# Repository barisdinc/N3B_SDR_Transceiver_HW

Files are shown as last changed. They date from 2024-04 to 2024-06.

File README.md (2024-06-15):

# N3B
V/U/SHF and QO-100 SDR Transceiver Project

This project is a SDR receiver transceiver project initiated to have a portable QO-100 Satellite ground station which can receiver on 739 MHz (direct output of a standard TV LNB) and transmit on 2.4 GHz QO-100 uplink frequency.
The basic idea of the SDR is based on Arjante Marvelde's implementation of Guido's uSDX implementation on raspberry pi pico (https://github.com/ArjanteMarvelde/uSDR-pico/).

Instead of HF components as Tyloe detector Analog Devices's IQ modulator and demodulator chips are chosen to be the IQ components.

I will update the documentation as soon as possible.
Baris DINC
OH2UDS / TA7W

initial pictures of qocurrent work done
initial pictures of the working HW 
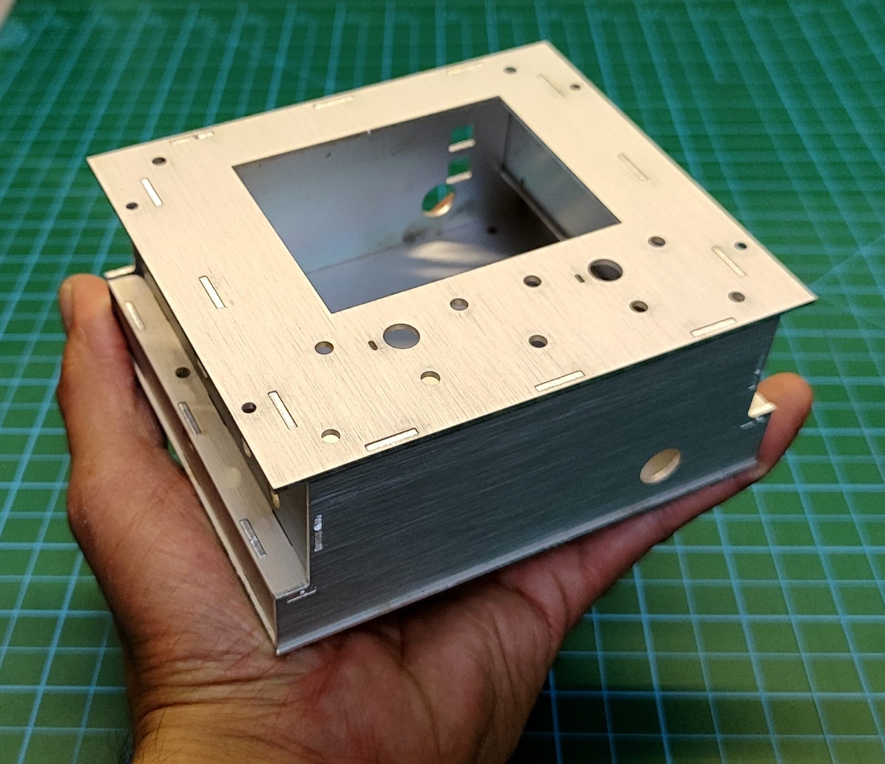
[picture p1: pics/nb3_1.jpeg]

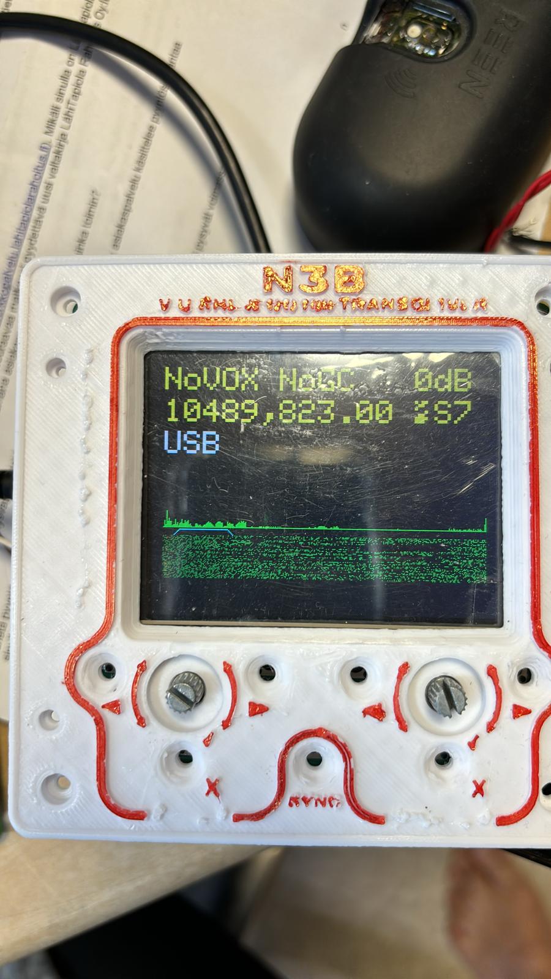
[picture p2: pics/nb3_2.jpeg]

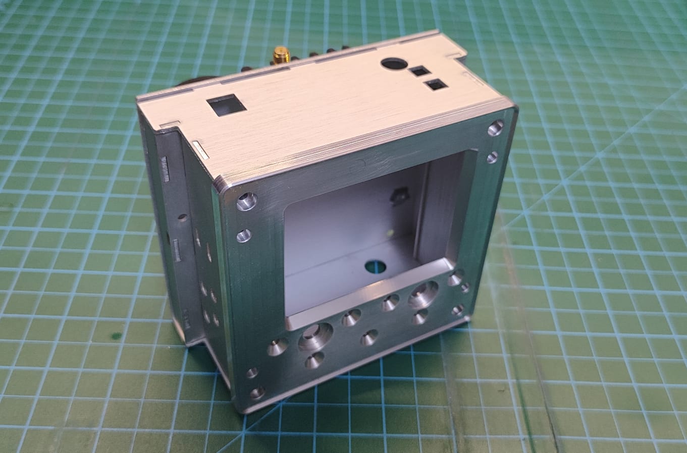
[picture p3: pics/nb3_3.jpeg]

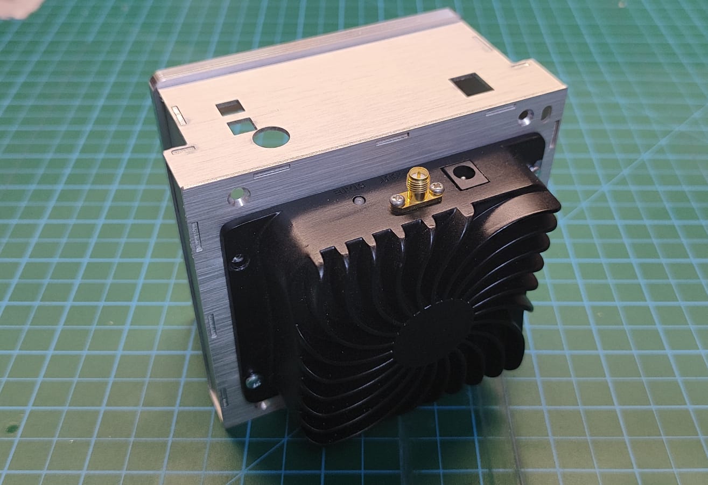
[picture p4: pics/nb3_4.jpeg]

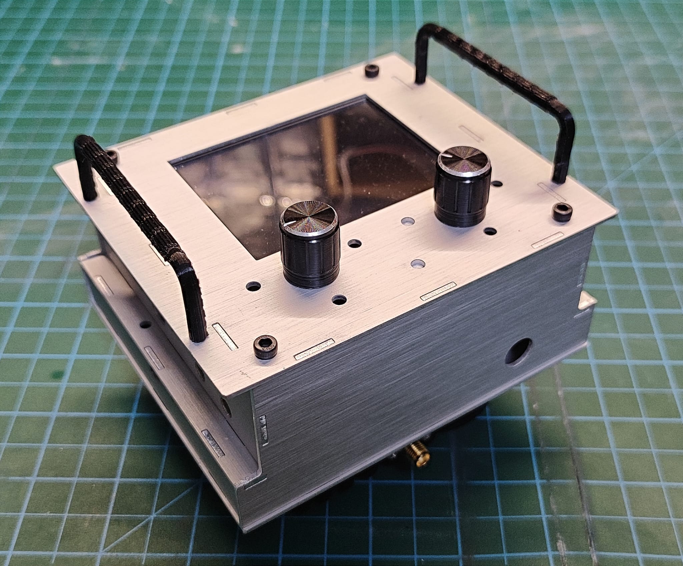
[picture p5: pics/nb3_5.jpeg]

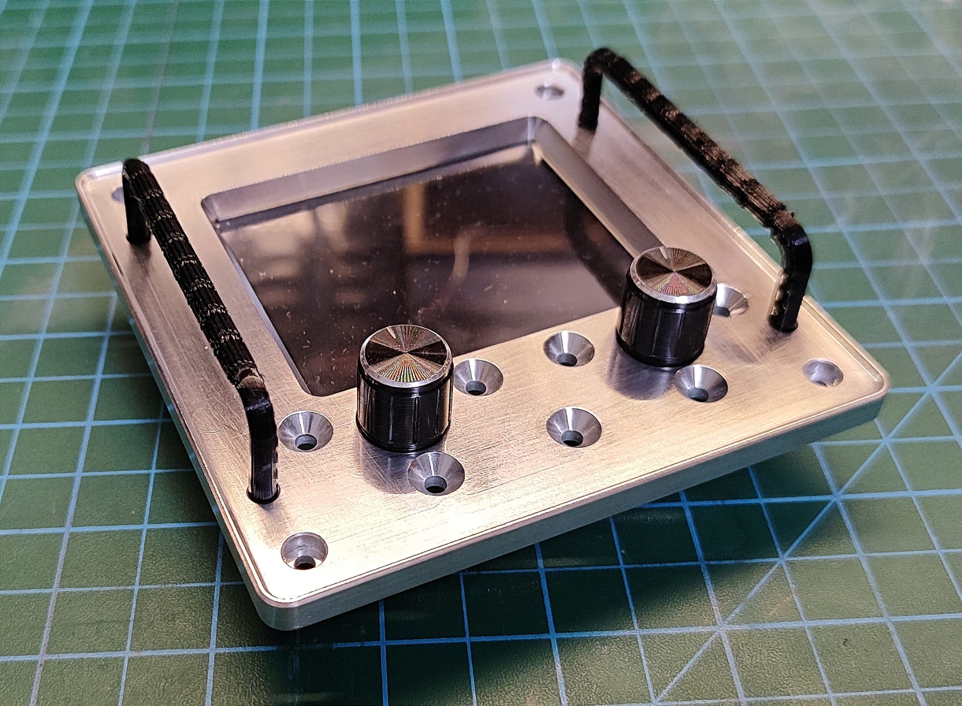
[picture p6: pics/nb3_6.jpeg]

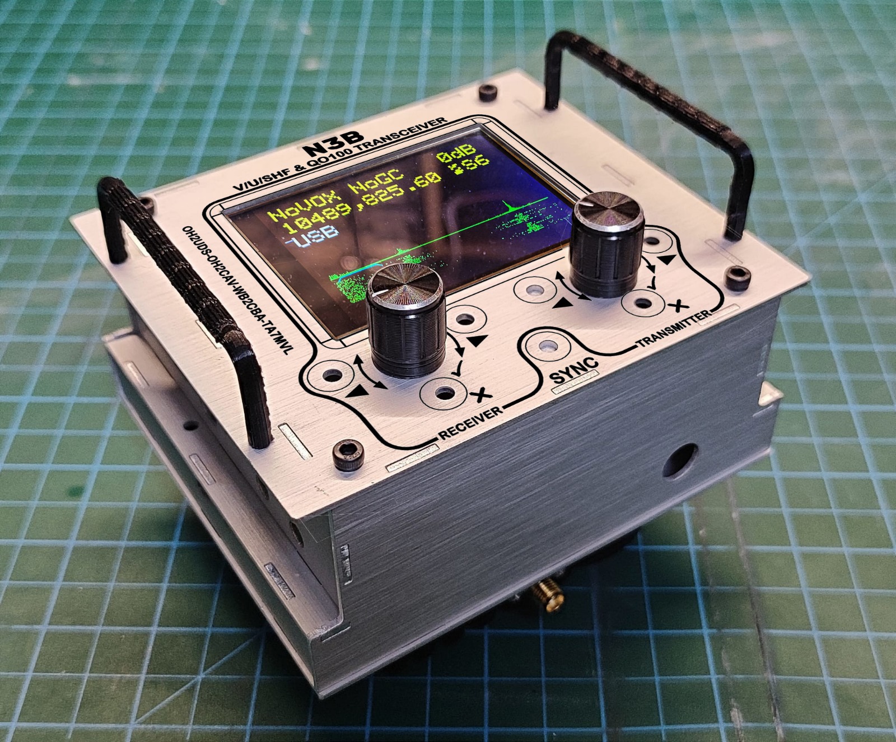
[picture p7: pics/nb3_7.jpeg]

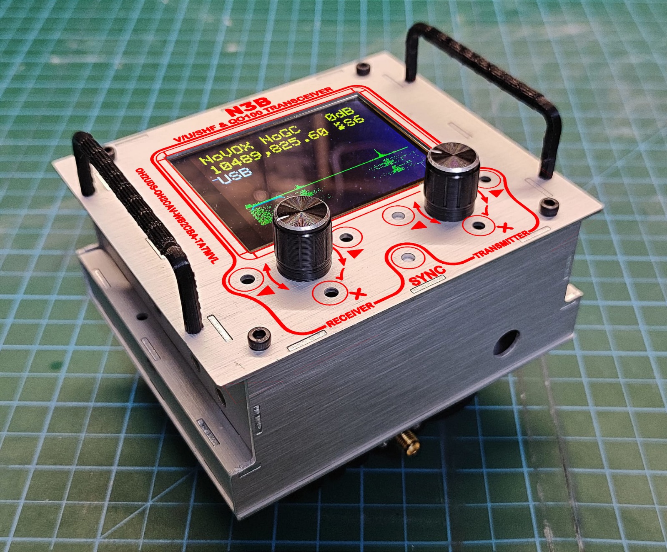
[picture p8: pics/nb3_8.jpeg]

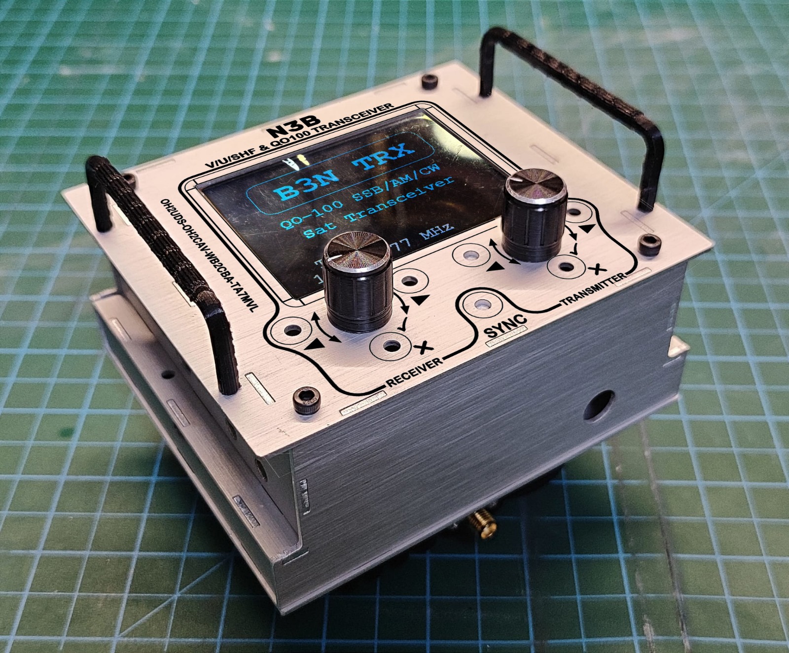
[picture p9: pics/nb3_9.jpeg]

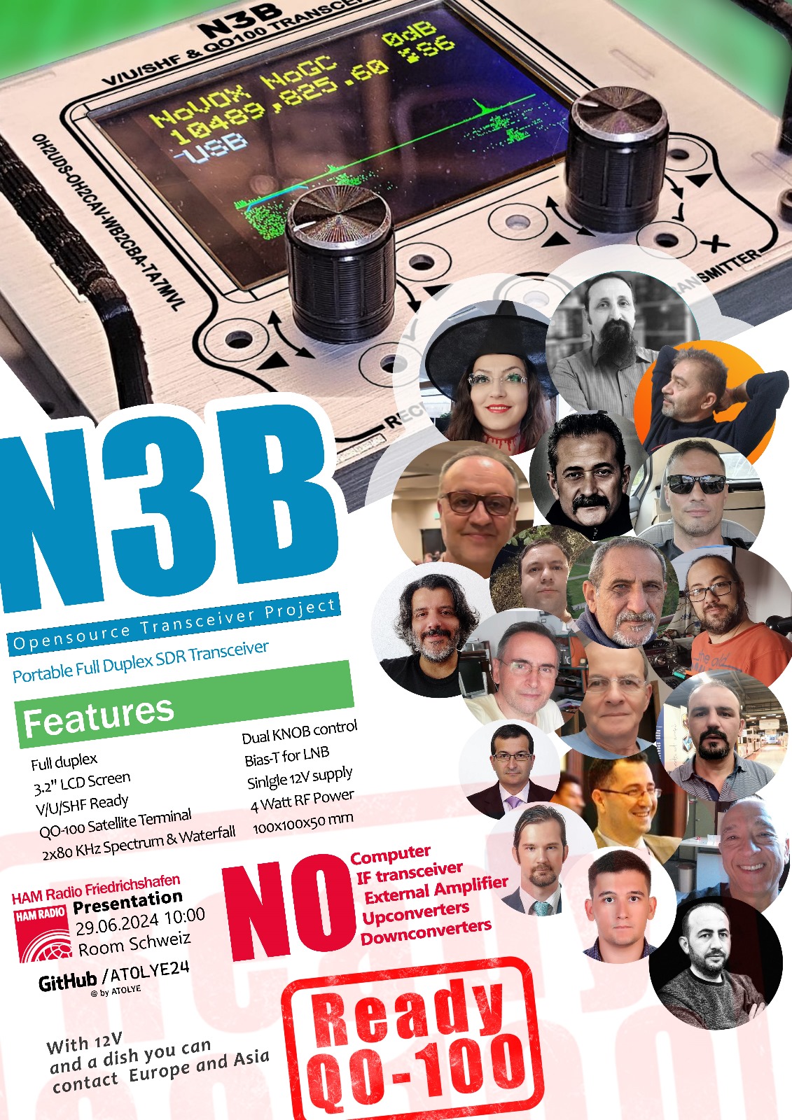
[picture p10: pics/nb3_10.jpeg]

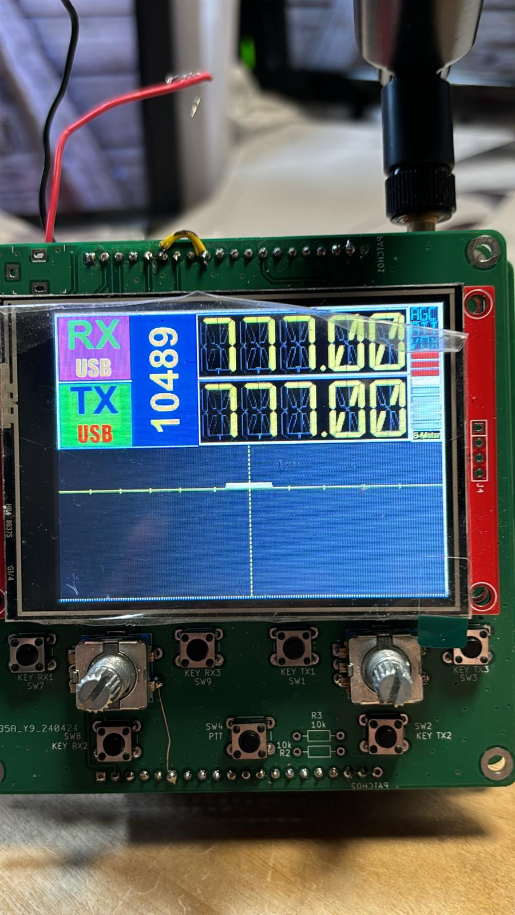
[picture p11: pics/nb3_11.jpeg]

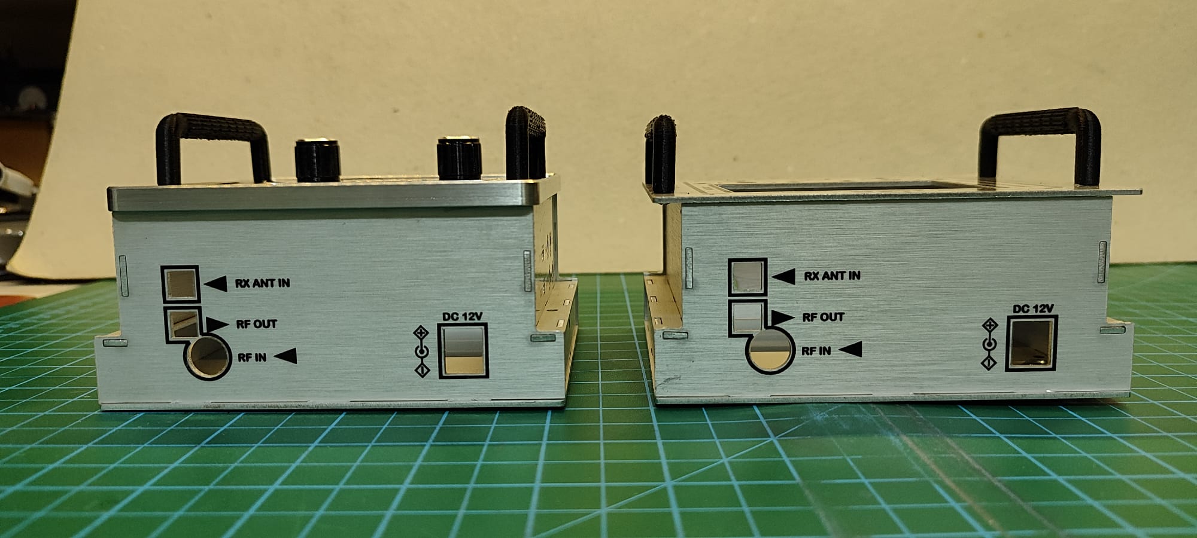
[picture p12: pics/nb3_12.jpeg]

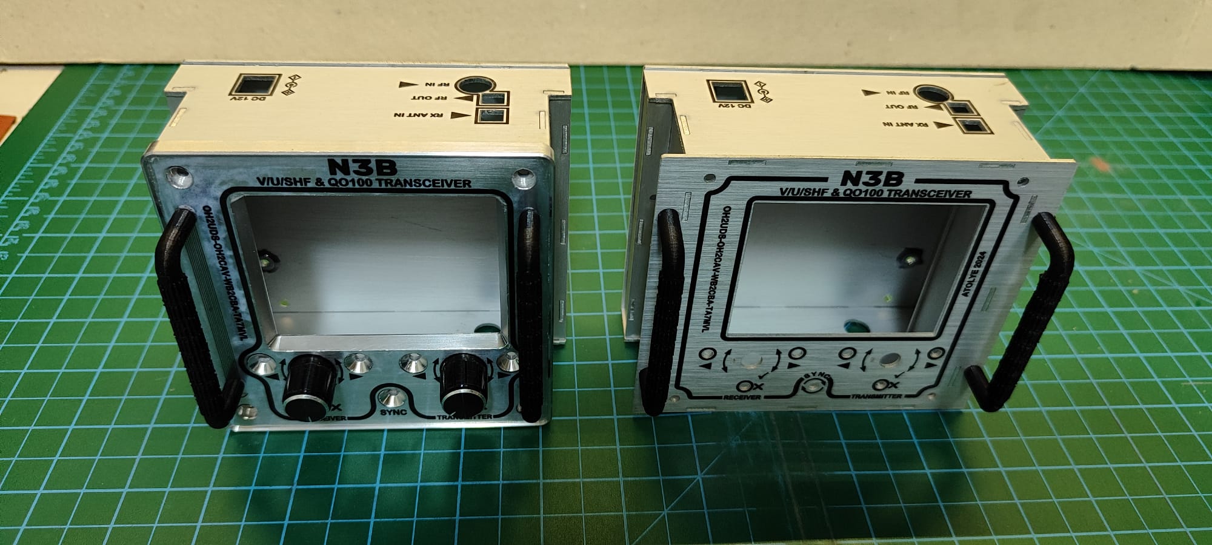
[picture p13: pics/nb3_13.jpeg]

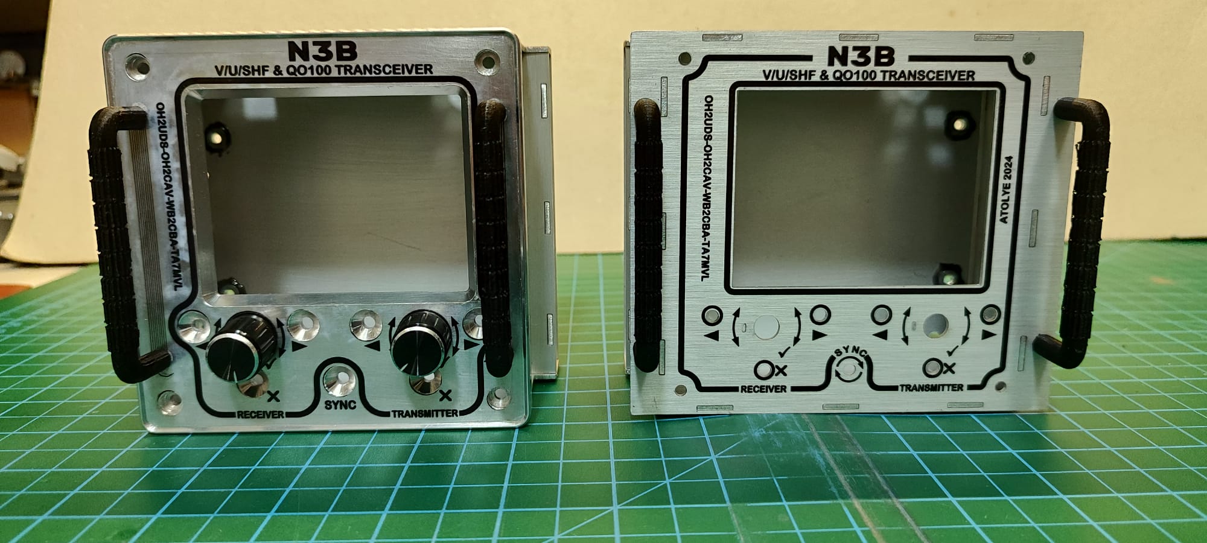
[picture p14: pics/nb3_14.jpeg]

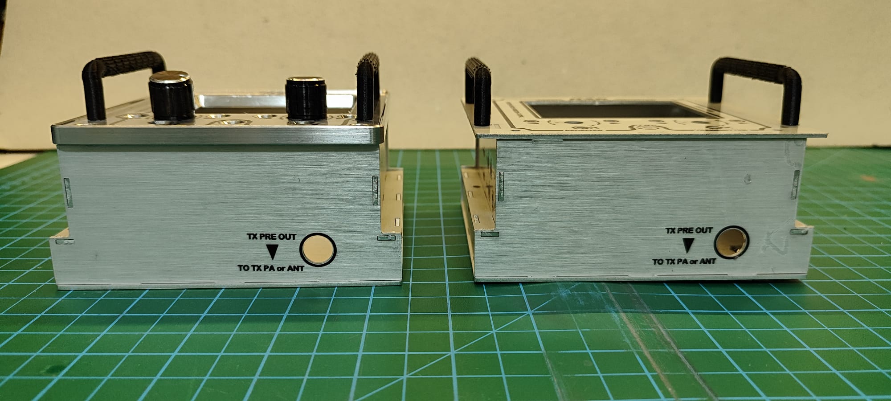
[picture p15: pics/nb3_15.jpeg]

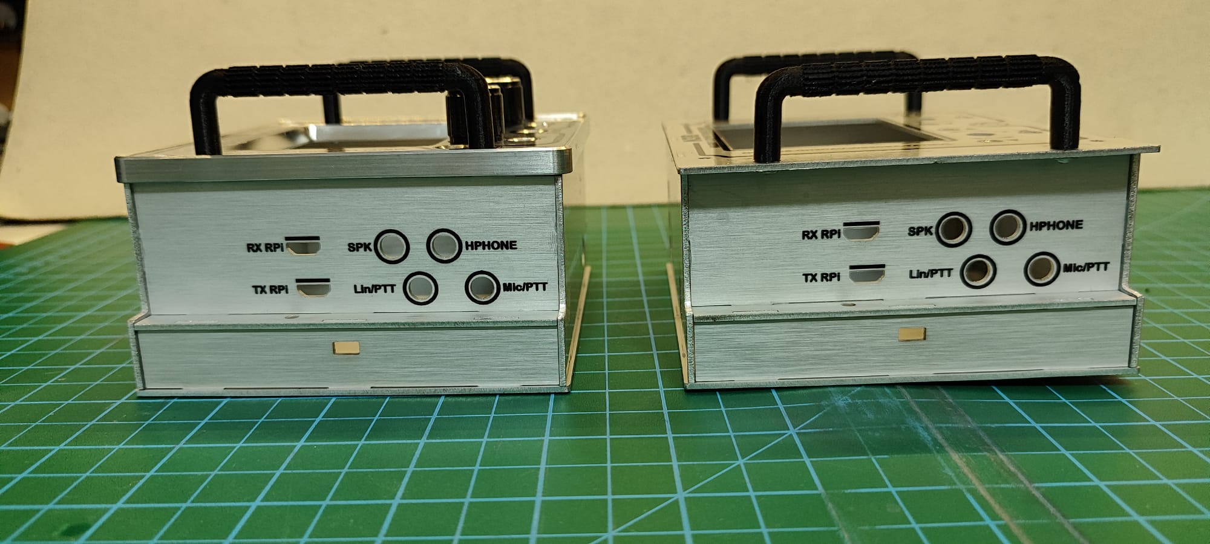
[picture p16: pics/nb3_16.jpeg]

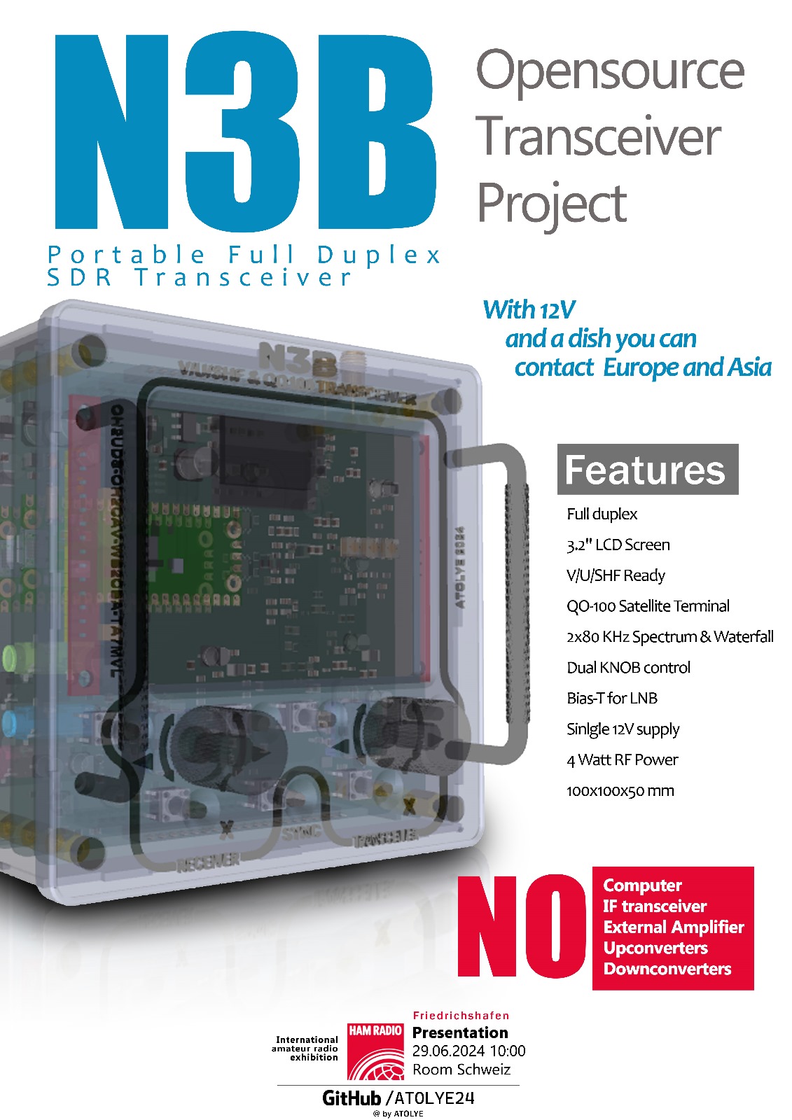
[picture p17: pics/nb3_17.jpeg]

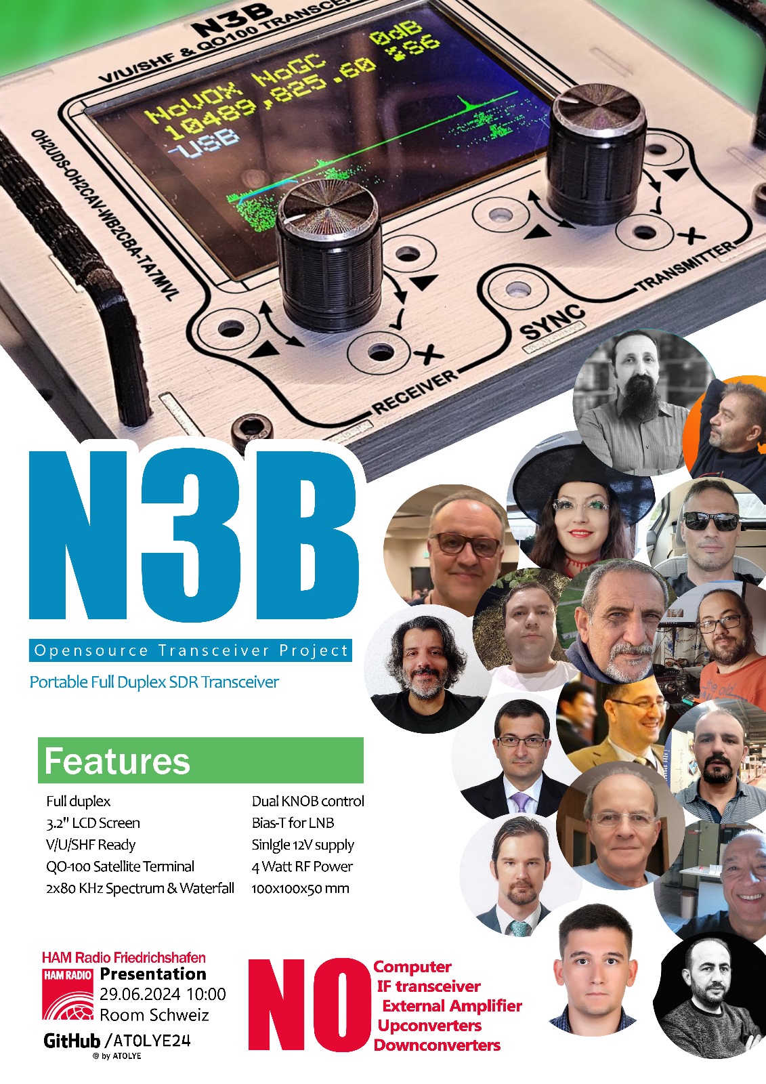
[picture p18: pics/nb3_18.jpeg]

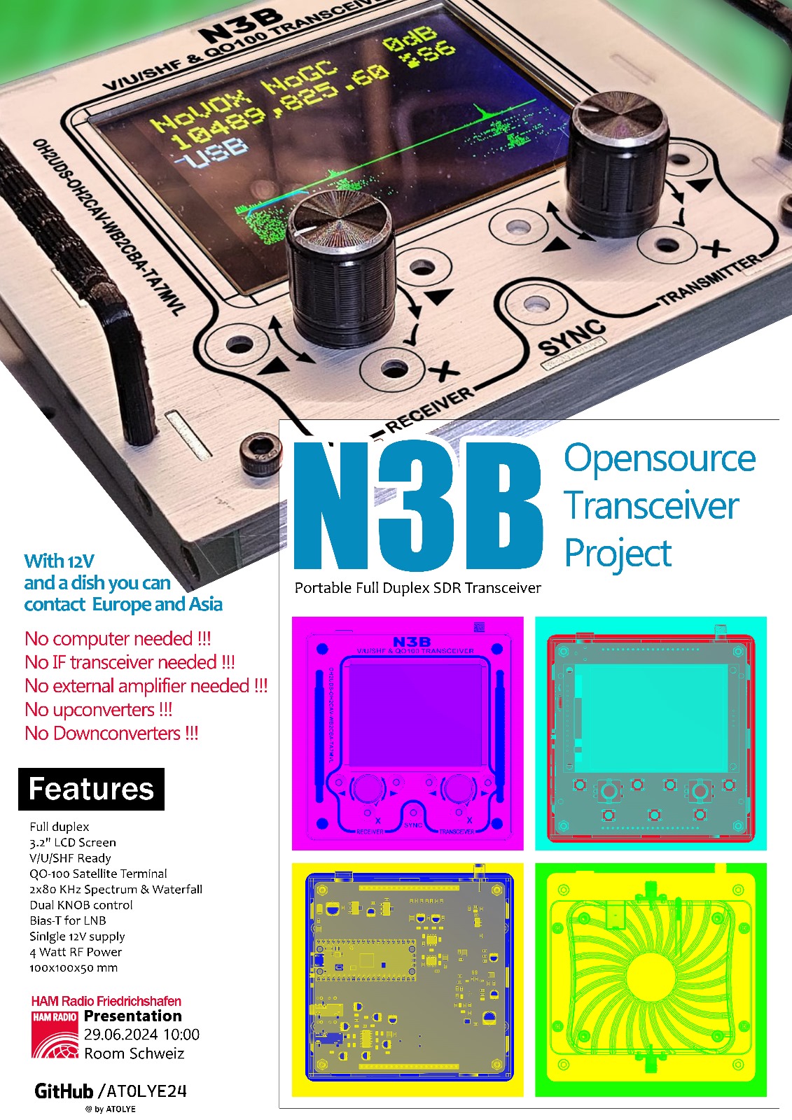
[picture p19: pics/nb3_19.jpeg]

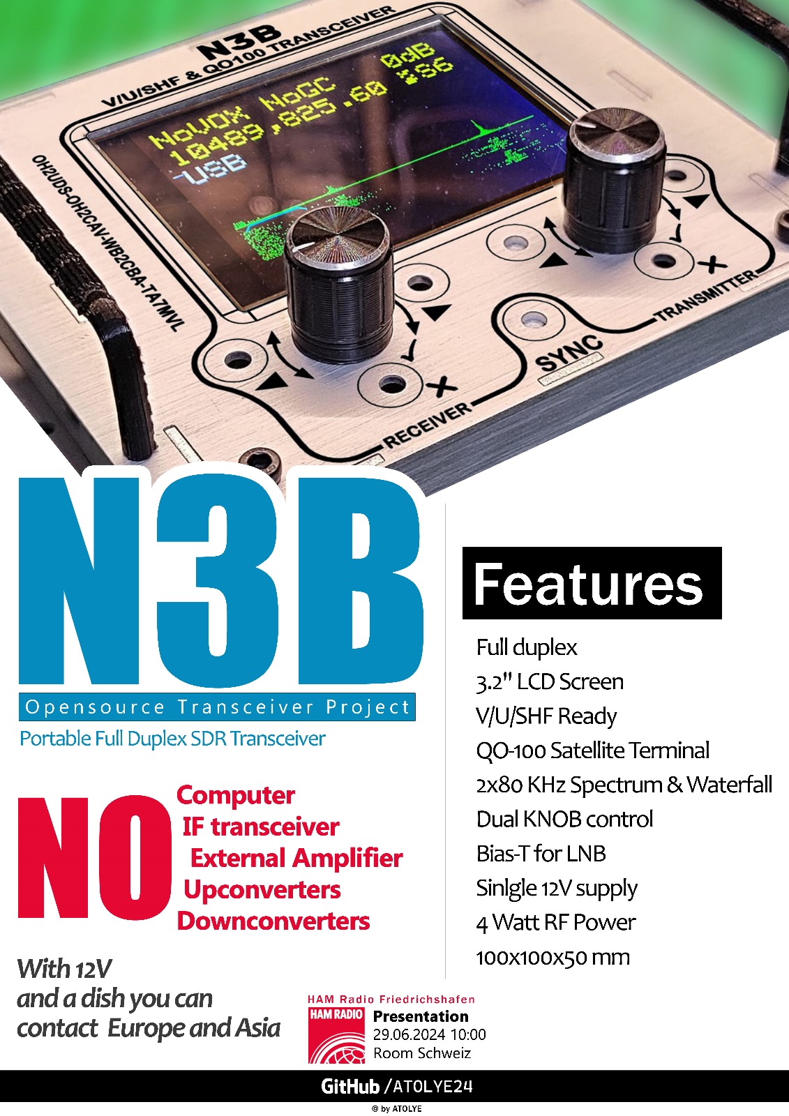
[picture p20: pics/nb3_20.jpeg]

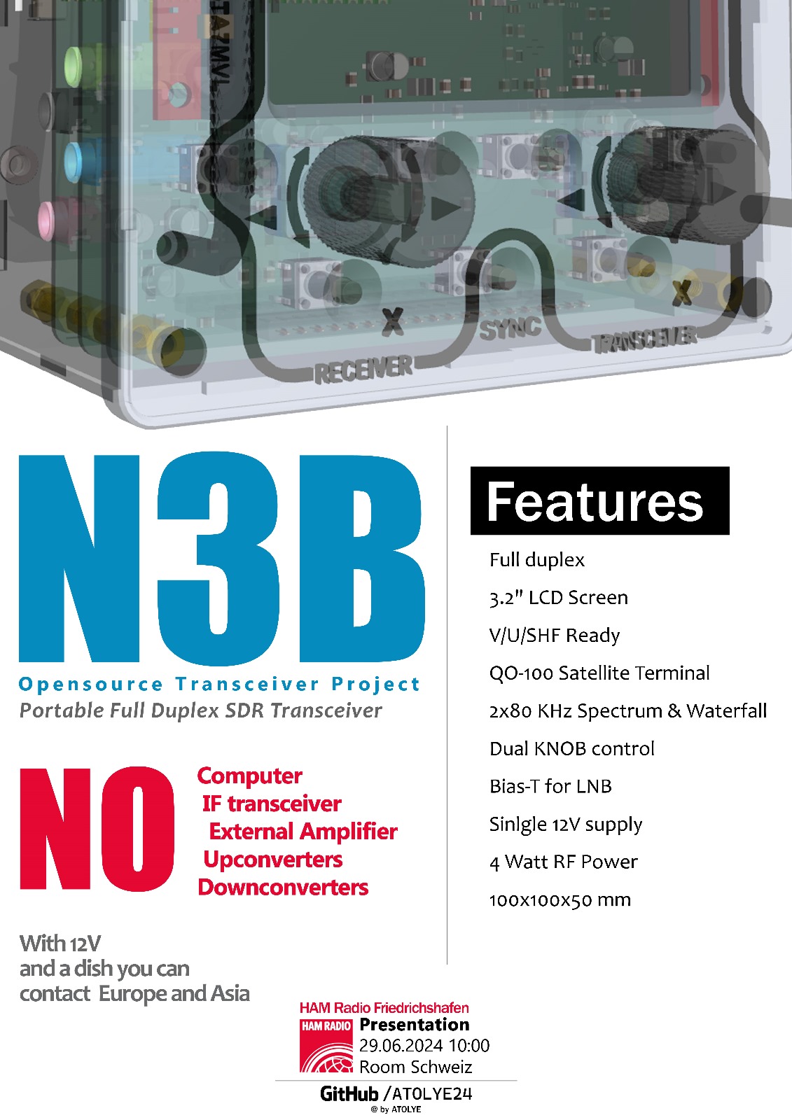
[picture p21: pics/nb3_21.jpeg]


OH2UDS / TA7W.

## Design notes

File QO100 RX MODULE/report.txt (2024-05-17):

Info: Change symbol path "C66:" to "/663CC0C7".
Info: Change symbol path "L5:" to "/664548BE".
Info: Processing component "R30:/664476E5:Resistor_SMD:R_0805_2012Metric".
Info: Change symbol path "C68:" to "/663DEFD4".
Info: Change symbol path "R30:" to "/664476E5".
Info: Processing component "C68:/663DEFD4:Capacitor_SMD:C_0805_2012Metric".
Info: Change symbol path "C67:" to "/6658E7D9".
Info: Processing component "R31:/662D891D:Resistor_SMD:R_0805_2012Metric".
Info: Processing component "C67:/6658E7D9:Capacitor_SMD:C_0805_2012Metric".
Info: Change symbol path "R33:" to "/66471DDC".
Info: Change symbol path "C76:" to "/664476D9".
Info: Processing component "R32:/664476DF:Resistor_SMD:R_0805_2012Metric".
Info: Processing component "C66:/663CC0C7:Capacitor_SMD:C_0805_2012Metric".
Info: Change symbol path "C65:" to "/6677DF00".
Info: Change symbol path "R29:" to "/662DA837".
Info: Processing component "C65:/6677DF00:Capacitor_SMD:C_0805_2012Metric".
Info: Processing component "R33:/66471DDC:Resistor_SMD:R_0805_2012Metric".
Info: Change symbol path "C64:" to "/663E3197".
Info: Processing component "C64:/663E3197:Capacitor_SMD:CP_Elec_4x5.4".
Info: Processing component "L6:/663A9446:Inductor_SMD:L_0603_1608Metric".
Info: Change symbol path "C63:" to "/6677C284".
Info: Processing component "R34:/66D28264:Resistor_SMD:R_0805_2012Metric".
Info: Processing component "C63:/6677C284:Capacitor_SMD:C_0805_2012Metric".
Info: Change symbol path "C62:" to "/663E1CF4".
Info: Change symbol path "R34:" to "/66D28264".
Info: Processing component "C62:/663E1CF4:Capacitor_SMD:C_0805_2012Metric".
Info: Processing component "R35:/66701C3B:Resistor_SMD:R_0805_2012Metric".
Info: Processing component "R27:/66D245A6:Resistor_SMD:R_0805_2012Metric".
Info: Change symbol path "R31:" to "/662D891D".
Info: Change symbol path "R24:" to "/66701C6C".
Info: Processing component "C76:/664476D9:Capacitor_SMD:C_0805_2012Metric".
Info: Processing component "R25:/668B2F03:Resistor_SMD:R_0805_2012Metric".
Info: Change symbol path "C75:" to "/662CEC74".
Info: Change symbol path "R25:" to "/668B2F03".
Info: Processing component "C75:/662CEC74:Capacitor_SMD:C_0805_2012Metric".
Info: Change symbol path "C74:" to "/66F02636".
Info: Processing component "R26:/668B1381:Resistor_SMD:R_0805_2012Metric".
Info: Processing component "C71:/662CAD43:Capacitor_SMD:C_0805_2012Metric".
Info: Change symbol path "R26:" to "/668B1381".
Info: Change symbol path "C73:" to "/66D249A5".
Info: Change symbol path "C61:" to "/6677A768".
Info: Processing component "C73:/66D249A5:Capacitor_SMD:C_0805_2012Metric".
Info: Change symbol path "C72:" to "/668B68FC".
Info: Change symbol path "R27:" to "/66D245A6".
Info: Processing component "C72:/668B68FC:Capacitor_SMD:C_0805_2012Metric".
Info: Processing component "R28:/662D695C:Resistor_SMD:R_0805_2012Metric".
Info: Processing component "C53:/669B0E9A:Capacitor_SMD:C_0805_2012Metric".
Info: Processing component "C47:/663A94C4:Capacitor_SMD:C_0805_2012Metric".
Info: Change symbol path "R28:" to "/662D695C".
Info: Change symbol path "C70:" to "/668B4AD4".
Info: Processing component "R29:/662DA837:Resistor_SMD:R_0805_2012Metric".
Info: Processing component "C70:/668B4AD4:Capacitor_SMD:C_0805_2012Metric".
Info: Change symbol path "C69:" to "/668B65B9".
Info: Processing component "C45:/663A943A:Capacitor_SMD:C_0805_2012Metric".
Info: Change symbol path "C53:" to "/669B0E9A".
Info: Processing component "U1:/66170904:RP2040_PICO:RPI2040_PICO_SMD".
Info: Processing component "C74:/66F02636:Capacitor_SMD:C_0805_2012Metric".
Info: Change symbol path "C52:" to "/6623EA73".
Info: Change symbol path "U1:" to "/66170904".
Info: Processing component "C52:/6623EA73:Capacitor_SMD:C_0805_2012Metric".
Info: Change symbol path "C51:" to "/66481EE1".
Info: Processing component "C51:/66481EE1:Capacitor_SMD:C_0805_2012Metric".
Info: Processing component "C50:/663A950D:Capacitor_SMD:CP_Elec_6.3x7.7".
Info: Processing component "C49:/663A9507:Capacitor_SMD:CP_Elec_4x5.4".
Info: Processing component "C48:/663A94CA:Capacitor_SMD:C_0805_2012Metric".
Info: Change symbol path "R1:" to "/66267878".
Info: Processing component "C46:/663A9440:Capacitor_SMD:C_0805_2012Metric".
Info: Processing component "C54:/668524BC:Capacitor_SMD:CP_Elec_4x5.4".
Info: Processing component "C44:/663A94BE:Capacitor_SMD:C_0805_2012Metric".
Info: Processing component "C43:/66706D0E:Capacitor_SMD:C_0805_2012Metric".
Info: Processing component "C42:/663A94B8:Capacitor_SMD:C_0805_2012Metric".
Info: Processing component "C41:/6670521F:Capacitor_SMD:C_0805_2012Metric".
Info: Processing component "C40:/663A94B2:Capacitor_SMD:C_0805_2012Metric".
Info: Processing component "C39:/663A94AC:Capacitor_SMD:C_0805_2012Metric".
Info: Processing component "R36:/66701C41:Resistor_SMD:R_0805_2012Metric".
Info: Processing component "L1:/662C1781:Inductor_SMD:L_1210_3225Metric".
Info: Processing component "C37:/6650C275:Capacitor_SMD:C_0805_2012Metric".
Info: Change symbol path "C36:" to "/6650DF28".
Info: Processing component "C36:/6650DF28:Capacitor_SMD:C_0805_2012Metric".
Info: Change symbol path "C35:" to "/663BE2B3".
Info: Processing component "RV2:/669DF9A2:Resistor_SMD:R_0805_2012Metric".
Info: Change symbol path "R35:" to "/66701C3B".
Info: Processing component "C61:/6677A768:Capacitor_SMD:C_0805_2012Metric".
Info: Change symbol path "R2:" to "/664604FC".
Info: Change symbol path "C57:" to "/667F7E6B".
Info: Processing component "C60:/669B49D2:Capacitor_SMD:C_0805_2012Metric".
Info: Change symbol path "R36:" to "/66701C41".
Info: Change symbol path "C59:" to "/66778975".
Info: Processing component "RV1:/669DDBF4:Resistor_SMD:R_0805_2012Metric".
Info: Processing component "C59:/66778975:Capacitor_SMD:C_0805_2012Metric".
Info: Change symbol path "C58:" to "/667087F0".
Info: Change symbol path "RV1:" to "/669DDBF4".
Info: Processing component "C58:/667087F0:Capacitor_SMD:C_0805_2012Metric".
Info: Change symbol path "RV3:" to "/669E166B".
Info: Processing component "H4:/66276D82:MountingHole:MountingHole_3.2mm_M3_DIN965_Pad".
Info: Processing component "C55:/6623D448:Capacitor_SMD:C_0805_2012Metric".
Info: Processing component "C57:/667F7E6B:Capacitor_SMD:C_0805_2012Metric".
Info: Change symbol path "RV2:" to "/669DF9A2".
Info: Change symbol path "C56:" to "/669B1360".
Info: Processing component "RV3:/669E166B:Resistor_SMD:R_0805_2012Metric".
Info: Processing component "C56:/669B1360:Capacitor_SMD:C_0805_2012Metric".
Info: Change symbol path "C55:" to "/6623D448".
Info: Change symbol path "C60:" to "/669B49D2".
Info: Processing component "SW1:/6629E30C:ADX_FOOTPRINT_LIBRARY:SW_Push_1P1T_NO_6x6mm_H9.5mm".
Info: Change symbol path "C54:" to "/668524BC".
Info: Change symbol path "SW1:" to "/6629E30C".
Info: Processing component "R5:/6645C210:Resistor_SMD:R_0805_2012Metric".
Info: Processing component "L2:/662BB9F9:Inductor_SMD:L_1210_3225Metric".
Info: Processing component "R2:/664604FC:Resistor_SMD:R_0805_2012Metric".
Info: Change symbol path "L1:" to "/662C1781".
Info: Processing component "C77:/66471DD6:Capacitor_SMD:C_0805_2012Metric".
Info: Change symbol path "J3:" to "/662B9816".
Info: Processing component "R3:/6645D7FB:Resistor_SMD:R_0805_2012Metric".
Info: Change symbol path "J6:" to "/666DE33C".
Info: Processing component "J6:/666DE33C:uSDX_MONO_PCB_Library:Jack_3.5mm_PJ-320B-SMT_Horizontal_CORR".
Info: Change symbol path "R3:" to "/6645D7FB".
Info: Processing component "R4:/6645EE0F:Resistor_SMD:R_0805_2012Metric".
Info: Change symbol path "J5:" to "/6626FDB7".
Info: Change symbol path "R4:" to "/6645EE0F".
Info: Processing component "J5:/6626FDB7:Connector_Coaxial:SMA_Samtec_SMA-J-P-X-ST-EM1_EdgeMount".
Info: Change symbol path "R8:" to "/6624112D".
Info: Change symbol path "L14:" to "/664476EB".
Info: Processing component "J3:/662B9816:uSDX_MONO_PCB_Library:Jack_3.5mm_PJ-320B-SMT_Horizontal_CORR".
Info: Change symbol path "R5:" to "/6645C210".
Info: Processing component "R6:/666D83CB:Resistor_SMD:R_0805_2012Metric".
Info: Change symbol path "R6:" to "/666D83CB".
Info: Processing component "R7:/6623FF50:Resistor_SMD:R_0805_2012Metric".
Info: Change symbol path "R7:" to "/6623FF50".
Info: Processing component "R8:/6624112D:Resistor_SMD:R_0805_2012Metric".
Info: Change symbol path "J2:" to "/6622BC8E".
Info: Change symbol path "C37:" to "/6650C275".
Info: Processing component "J2:/6622BC8E:Connector_PinHeader_2.54mm:PinHeader_1x20_P2.54mm_Vertical".
Info: Processing component "R9:/664AFDF3:Resistor_SMD:R_0805_2012Metric".
Info: Processing component "L7:/663A944C:Inductor_SMD:L_0603_1608Metric".
Info: Change symbol path "L13:" to "/66307578".
Info: Processing component "L13:/66307578:Inductor_SMD:L_0805_2012Metric".
Info: Change symbol path "L12:" to "/663E4A50".
Info: Processing component "L14:/664476EB:Inductor_SMD:L_0805_2012Metric".
Info: Processing component "L12:/663E4A50:Inductor_SMD:L_1210_3225Metric".
Info: Processing component "FL1:/662F43A0:SPF2126E:SF2126E".
Info: Change symbol path "L11:" to "/667F9DFE".
Info: Processing component "L15:/66471DE8:Inductor_SMD:L_0805_2012Metric".
Info: Processing component "L11:/667F9DFE:Inductor_SMD:L_1210_3225Metric".
Info: Processing component "L10:/663A9501:Inductor_SMD:L_1210_3225Metric".
Info: Processing component "L9:/663A9463:Inductor_SMD:L_0603_1608Metric".
Info: Processing component "L8:/663A945D:Inductor_SMD:L_0603_1608Metric".
Info: Change symbol path "R9:" to "/664AFDF3".
Info: Processing component "C38:/6676790A:Capacitor_SMD:C_0805_2012Metric".
Info: Change symbol path "L2:" to "/662BB9F9".
Info: Change symbol path "L15:" to "/66471DE8".
Info: Processing component "L5:/664548BE:Inductor_SMD:L_1210_3225Metric".
Info: Processing component "L16:/66D2CAC6:Inductor_SMD:L_0805_2012Metric".
Info: Change symbol path "L4:" to "/6636294A".
Info: Processing component "L4:/6636294A:Inductor_SMD:L_1210_3225Metric".
Info: Change symbol path "L16:" to "/66D2CAC6".
Info: Change symbol path "L3:" to "/663BB9BA".
Info: Processing component "R1:/66267878:Resistor_SMD:R_0805_2012Metric".
Info: Change symbol path "C82:" to "/66701C7A".
Info: Processing component "C80:/665907AD:Capacitor_SMD:C_0805_2012Metric".
Info: Change symbol path "R21:" to "/66243747".
Info: Change symbol path "C84:" to "/66701C74".
Info: Processing component "R19:/66683939:Resistor_SMD:R_0805_2012Metric".
Info: Processing component "C84:/66701C74:Capacitor_SMD:C_0805_2012Metric".
Info: Change symbol path "C83:" to "/66701C80".
Info: Change symbol path "R19:" to "/66683939".
Info: Processing component "C83:/66701C80:Capacitor_SMD:C_0805_2012Metric".
Info: Processing component "R20:/66681E04:Resistor_SMD:R_0805_2012Metric".
Info: Processing component "U10:/66224E30:Package_SO:SO-8_3.9x4.9mm_P1.27mm".
Info: Change symbol path "R20:" to "/66681E04".
Info: Processing component "C82:/66701C7A:Capacitor_SMD:C_0805_2012Metric".
Info: Change symbol path "C81:" to "/6658C40F".
Info: Processing component "R21:/66243747:Resistor_SMD:R_0805_2012Metric".
Info: Processing component "C81:/6658C40F:Capacitor_SMD:C_0805_2012Metric".
Info: Change symbol path "R18:" to "/669DA5DA".
Info: Change symbol path "C80:" to "/665907AD".
Info: Processing component "R22:/6646AC53:Resistor_SMD:R_0805_2012Metric".
Info: Processing component "L3:/663BB9BA:Inductor_SMD:L_0402_1005Metric".
Info: Change symbol path "C79:" to "/662CCD4D".
Info: Change symbol path "R22:" to "/6646AC53".
Info: Processing component "C79:/662CCD4D:Capacitor_SMD:C_0805_2012Metric".
Info: Processing component "R23:/6624490F:Resistor_SMD:R_0805_2012Metric".
Info: Change symbol path "C78:" to "/66D2A876".
Info: Processing component "C78:/66D2A876:Capacitor_SMD:C_0805_2012Metric".
Info: Change symbol path "R23:" to "/6624490F".
Info: Change symbol path "C77:" to "/66471DD6".
Info: Processing component "H3:/66276969:MountingHole:MountingHole_3.2mm_M3_DIN965_Pad".
Info: Change symbol path "R13:" to "/669DA320".
Info: Processing component "R10:/662424AE:Resistor_SMD:R_0805_2012Metric".
Info: Change symbol path "R10:" to "/662424AE".
Info: Processing component "R11:/663A940E:Resistor_SMD:R_0805_2012Metric".
Info: Processing component "R12:/669D85E4:Resistor_SMD:R_0805_2012Metric".
Info: Change symbol path "J1:" to "/6622BC88".
Info: Change symbol path "R12:" to "/669D85E4".
Info: Processing component "J1:/6622BC88:Connector_PinHeader_2.54mm:PinHeader_1x20_P2.54mm_Vertical".
Info: Change symbol path "R15:" to "/66B90303".
Info: Change symbol path "C23:" to "/661E46CD".
Info: Processing component "H2:/662752CF:MountingHole:MountingHole_3.2mm_M3_DIN965_Pad".
Info: Processing component "H1:/6627385C:MountingHole:MountingHole_3.2mm_M3_DIN965_Pad".
Info: Processing component "R13:/669DA320:Resistor_SMD:R_0805_2012Metric".
Info: Processing component "C1:/661A04E7:Capacitor_SMD:C_0805_2012Metric".
Info: Processing component "R14:/663A9422:Resistor_SMD:R_0805_2012Metric".
Info: Change symbol path "FL1:" to "/662F43A0".
Info: Processing component "R15:/66B90303:Resistor_SMD:R_0805_2012Metric".
Info: Change symbol path "C71:" to "/662CAD43".
Info: Processing component "R24:/66701C6C:Resistor_SMD:R_0805_2012Metric".
Info: Change symbol path "D1:" to "/664282D6".
Info: Processing component "R16:/6673A672:Resistor_SMD:R_0805_2012Metric".
Info: Processing component "D1:/664282D6:Diode_SMD:D_SMA".
Info: Processing component "R17:/66708C14:Resistor_SMD:R_0805_2012Metric".
Info: Processing component "R18:/669DA5DA:Resistor_SMD:R_0805_2012Metric".
Info: Change symbol path "C85:" to "/66701C66".
Info: Processing component "C85:/66701C66:Capacitor_SMD:C_0805_2012Metric".
Info: Change symbol path "C6:" to "/661A8007".
Info: Change symbol path "U2:" to "/666D18F3".
Info: Processing component "C30:/666D56C6:Capacitor_SMD:CP_Elec_6.3x7.7".
Info: Processing component "U2:/666D18F3:Package_SO:SO-8_3.9x4.9mm_P1.27mm".
Info: Processing component "C5:/662C6E13:Capacitor_SMD:C_0805_2012Metric".
Info: Processing component "C17:/66459781:Capacitor_SMD:C_0805_2012Metric".
Info: Processing component "C12:/666D3F2C:Capacitor_SMD:C_0805_2012Metric".
Info: Processing component "U5:/6617BE55:Package_TO_SOT_SMD:SOT-223-3_TabPin2".
Info: Change symbol path "C30:" to "/666D56C6".
Info: Change symbol path "C4:" to "/6626E9A2".
Info: Processing component "C4:/6626E9A2:Capacitor_SMD:C_0805_2012Metric".
Info: Change symbol path "C11:" to "/6645ACA6".
Info: Change symbol path "C16:" to "/666DB293".
Info: Change symbol path "C18:" to "/661DE9E5".
Info: Change symbol path "U9:" to "/6621ED04".
Info: Processing component "C31:/663A946B:Capacitor_SMD:C_0805_2012Metric".
Info: Change symbol path "U6:" to "/6617CADD".
Info: Processing component "C20:/663A93F3:Capacitor_SMD:C_0805_2012Metric".
Info: Processing component "C32:/6627184F:Capacitor_SMD:C_0805_2012Metric".
Info: Processing component "C11:/6645ACA6:Capacitor_SMD:C_0805_2012Metric".
Info: Change symbol path "U3:" to "/664305AF".
Info: Change symbol path "C27:" to "/661E6F20".
Info: Change symbol path "U10:" to "/66224E30".
Info: Change symbol path "C9:" to "/661A4FAA".
Info: Processing component "C18:/661DE9E5:Capacitor_SMD:C_0805_2012Metric".
Info: Processing component "C6:/661A8007:Capacitor_SMD:C_0805_2012Metric".
Info: Processing component "C25:/666D6E58:Capacitor_SMD:C_0805_2012Metric".
Info: Processing component "C28:/66271849:Capacitor_SMD:CP_Elec_6.3x7.7".
Info: Processing component "C24:/663A9402:Capacitor_SMD:C_0805_2012Metric".
Info: Processing component "C69:/668B65B9:Capacitor_SMD:C_0805_2012Metric".
Info: Change symbol path "C25:" to "/666D6E58".
Info: Change symbol path "C10:" to "/667DC316".
Info: Processing component "C23:/661E46CD:Capacitor_SMD:CP_Elec_4x5.4".
Info: Change symbol path "C5:" to "/662C6E13".
Info: Change symbol path "C17:" to "/66459781".
Info: Change symbol path "C28:" to "/66271849".
Info: Change symbol path "C19:" to "/66458273".
Info: Change symbol path "U5:" to "/6617BE55".
Info: Change symbol path "C12:" to "/666D3F2C".
Info: Processing component "U6:/6617CADD:Package_TO_SOT_SMD:SOT-223-3_TabPin2".
Info: Change symbol path "C7:" to "/66454012".
Info: Processing component "C29:/663A942E:Capacitor_SMD:C_0805_2012Metric".
Info: Change symbol path "U7:" to "/663A5B81".
Info: Change symbol path "C2:" to "/661A2793".
Info: Processing component "U3:/664305AF:Package_SO:SO-8_3.9x4.9mm_P1.27mm".
Info: Processing component "C26:/663A9408:Capacitor_SMD:C_0805_2012Metric".
Info: Change symbol path "C34:" to "/66271855".
Info: Change symbol path "C1:" to "/661A04E7".
Info: Change symbol path "U11:" to "/66289188".
Info: Processing component "C7:/66454012:Capacitor_SMD:CP_Elec_4x5.4".
Info: Processing component "C2:/661A2793:Capacitor_SMD:C_0805_2012Metric".
Info: Change symbol path "C13:" to "/662856A4".
Info: Change symbol path "C21:" to "/661DF5A6".
Info: Processing component "C34:/66271855:Capacitor_SMD:C_0805_2012Metric".
Info: Processing component "C35:/663BE2B3:Capacitor_SMD:C_0805_2012Metric".
Info: Change symbol path "C14:" to "/66283728".
Info: Processing component "C21:/661DF5A6:Capacitor_SMD:C_0805_2012Metric".
Info: Processing component "C16:/666DB293:Capacitor_SMD:CP_Elec_4x5.4".
Info: Processing component "C22:/666D9ABC:Capacitor_SMD:C_0805_2012Metric".
Info: Change symbol path "C8:" to "/661A762A".
Info: Processing component "C14:/66283728:Capacitor_SMD:C_0805_2012Metric".
Info: Processing component "Y1:/661E7D14:Crystal:Crystal_SMD_SeikoEpson_FA238V-4Pin_3.2x2.5mm".
Info: Processing component "U4:/66271843:Package_TO_SOT_SMD:SOT-223-3_TabPin2".
Info: Processing component "C10:/667DC316:Capacitor_SMD:CP_Elec_4x5.4".
Info: Processing component "C13:/662856A4:Capacitor_SMD:C_0805_2012Metric".
Info: Processing component "U11:/66289188:AD8348ARUZ:AD8348SEDA".
Info: Change symbol path "R32:" to "/664476DF".
Info: Change symbol path "C22:" to "/666D9ABC".
Info: Processing component "C9:/661A4FAA:Capacitor_SMD:C_0805_2012Metric".
Info: Change symbol path "C32:" to "/6627184F".
Info: Change symbol path "C3:" to "/661B85C5".
Info: Processing component "C8:/661A762A:Capacitor_SMD:C_0805_2012Metric".
Info: Change symbol path "U4:" to "/66271843".
Info: Processing component "C27:/661E6F20:Capacitor_SMD:C_0805_2012Metric".
Info: Change symbol path "C15:" to "/661DD41F".
Info: Processing component "C33:/66455496:Capacitor_SMD:CP_Elec_4x5.4".
Info: Processing component "C19:/66458273:Capacitor_SMD:C_0805_2012Metric".
Info: Processing component "U7:/663A5B81:BGA7L1BN6:IC_BGC100GN6E6327XTSA1".
Info: Processing component "C3:/661B85C5:Capacitor_SMD:C_0805_2012Metric".
Info: Change symbol path "C33:" to "/66455496".
Info: Processing component "U9:/6621ED04:Package_SO:SO-8_3.9x4.9mm_P1.27mm".
Info: Processing component "U8:/66390867:ADF4360-5BCP:ADF4360SEDA".
Info: Processing component "C15:/661DD41F:Capacitor_SMD:CP_Elec_6.3x7.7".
Connect R10 pin 1 to Net-(R10-Pad1).
Connect R9 pin 1 to LNA_Cont.
Add R12 (footprint "Resistor_SMD:R_0805_2012Metric").
Change REF** reference to R12.
Change R12 value from R_0805_2012Metric to 200R.
Connect U10 pin 7 to Net-(C84-Pad1).
Connect U10 pin 8 to Net-(C55-Pad1).
Connect R12 pin 2 to GNDPWR.
Connect R12 pin 1 to IOFS.
Change U10 value from SO-8_3.9x4.9mm_P1.27mm to LM4562.
Connect U10 pin 6 to Net-(C83-Pad1).
Connect U10 pin 5 to Net-(C82-Pad1).
Connect R10 pin 2 to VCMO.
Add R15 (footprint "Resistor_SMD:R_0805_2012Metric").
Change R10 value from R_0805_2012Metric to 10R.
Change REF** reference to R10.
Add R10 (footprint "Resistor_SMD:R_0805_2012Metric").
Connect U10 pin 4 to GNDPWR.
Change REF** reference to R7.
Connect R19 pin 1 to Net-(C59-Pad1).
Change R8 value from R_0805_2012Metric to 1k.
Connect U9 pin 8 to Net-(C55-Pad1).
Connect R18 pin 2 to GNDPWR.
Change U9 value from SO-8_3.9x4.9mm_P1.27mm to LM4562.
Connect R18 pin 1 to Net-(C60-Pad1).
Connect R20 pin 1 to Net-(C59-Pad1).
Connect U7 pin 4 to GNDPWR.
Change REF** reference to R19.
Change R19 value from R_0805_2012Metric to 3.9k.
Add U9 (footprint "Package_SO:SO-8_3.9x4.9mm_P1.27mm").
Connect R19 pin 2 to Net-(R19-Pad2).
Change R18 value from R_0805_2012Metric to 200R.
Add R20 (footprint "Resistor_SMD:R_0805_2012Metric").
Connect U7 pin 5 to Net-(L3-Pad2).
Change REF** reference to R20.
Change R20 value from R_0805_2012Metric to 3.9k.
Connect U7 pin 2 to Net-(C36-Pad1).
Connect R20 pin 2 to Net-(R20-Pad2).
Connect U9 pin 2 to VCMO.
Change REF** reference to U9.
Add R21 (footprint "Resistor_SMD:R_0805_2012Metric").
Change REF** reference to R21.
Change R15 value from R_0805_2012Metric to 3.9k.
Add U10 (footprint "Package_SO:SO-8_3.9x4.9mm_P1.27mm").
Add R13 (footprint "Resistor_SMD:R_0805_2012Metric").
Change REF** reference to R13.
Change R13 value from R_0805_2012Metric to 200R.
Connect R13 pin 2 to GNDPWR.
Connect R13 pin 1 to QOFS.
Connect U9 pin 1 to Net-(R10-Pad1).
Change REF** reference to R1.
Connect L15 pin 1 to QAIN.
Change REF** reference to R15.
Change REF** reference to U10.
Connect U9 pin 3 to Net-(C52-Pad1).
Connect U9 pin 4 to GNDPWR.
Connect R15 pin 2 to Net-(R15-Pad2).
Connect R15 pin 1 to Net-(C59-Pad1).
Connect U9 pin 5 to Net-(U9-Pad5).
Connect U9 pin 6 to GNDPWR.
Connect U9 pin 7 to Net-(U9-Pad5).
Add R18 (footprint "Resistor_SMD:R_0805_2012Metric").
Change REF** reference to R18.
Connect R2 pin 2 to Net-(C10-Pad2).
Add C33 (footprint "Capacitor_SMD:CP_Elec_4x5.4").
Connect U11 pin 12 to Net-(C59-Pad1).
Add L16 (footprint "Inductor_SMD:L_0805_2012Metric").
Change REF** reference to L16.
Change L16 value from L_0805_2012Metric to 1.2uH.
Connect U11 pin 13 to IOFS.
Connect L16 pin 2 to Net-(C74-Pad1).
Connect U11 pin 14 to Net-(C58-Pad1).
Connect L16 pin 1 to Net-(L16-Pad1).
Connect U11 pin 15 to Net-(R20-Pad2).
Add R1 (footprint "Resistor_SMD:R_0805_2012Metric").
Connect L14 pin 1 to Net-(C76-Pad1).
Change L13 value from L_0805_2012Metric to 680nH.
Change R1 value from R_0805_2012Metric to 4.7k.
Connect U11 pin 17 to Net-(RV3-Pad2).
Connect R1 pin 2 to Net-(R1-Pad2).
Connect R1 pin 1 to Net-(C4-Pad1).
Connect U11 pin 18 to Net-(U11-Pad18).
Add R2 (footprint "Resistor_SMD:R_0805_2012Metric").
Connect U11 pin 19 to Net-(U11-Pad19).
Change REF** reference to R2.
Change R2 value from R_0805_2012Metric to 12k.
Connect U11 pin 20 to Net-(C59-Pad1).
Connect U11 pin 21 to QMXO.
Add R19 (footprint "Resistor_SMD:R_0805_2012Metric").
Connect U11 pin 11 to Net-(C70-Pad1).
Add C1 (footprint "Capacitor_SMD:C_0805_2012Metric").
Connect L13 pin 2 to Net-(L13-Pad2).
Connect L13 pin 1 to Net-(C75-Pad1).
Connect U11 pin 1 to ADF_LOP.
Add L14 (footprint "Inductor_SMD:L_0805_2012Metric").
Change REF** reference to L14.
Connect U11 pin 2 to Net-(C59-Pad1).
Change L14 value from L_0805_2012Metric to 680nH.
Connect U11 pin 3 to DEM_I_N.
Connect L14 pin 2 to Net-(L14-Pad2).
Add R6 (footprint "Resistor_SMD:R_0805_2012Metric").
Change REF** reference to R6.
Connect U11 pin 5 to VCMO.
Connect U11 pin 6 to IAIN.
Connect U11 pin 7 to GNDPWR.
Connect U11 pin 8 to IMXO.
Add L15 (footprint "Inductor_SMD:L_0805_2012Metric").
Change REF** reference to L15.
Connect U11 pin 9 to GNDPWR.
Change L15 value from L_0805_2012Metric to 1.2uH.
Connect U11 pin 10 to Net-(C69-Pad1).
Connect L15 pin 2 to Net-(L15-Pad2).
Connect R7 pin 1 to Net-(C55-Pad1).
Connect R4 pin 2 to Net-(C11-Pad1).
Connect R4 pin 1 to Net-(C17-Pad2).
Change R6 value from R_0805_2012Metric to 10R.
Change REF** reference to U11.
Connect R6 pin 2 to GNDPWR.
Connect R6 pin 1 to Net-(C25-Pad2).
Add R7 (footprint "Resistor_SMD:R_0805_2012Metric").
Connect U6 pin 2 to +3V3.
Change R7 value from R_0805_2012Metric to 1k.
Add U11 (footprint "AD8348ARUZ:AD8348SEDA").
Connect R7 pin 2 to Net-(C52-Pad1).
Change U11 value from SOP65P640X120-28N to AD8348ARUZ.
Change REF** reference to R8.
Change REF** reference to C77.
Connect U10 pin 1 to Net-(C68-Pad2).
Connect R8 pin 2 to GNDPWR.
Connect U10 pin 2 to Net-(C80-Pad1).
Connect R8 pin 1 to Net-(C52-Pad1).
Connect U10 pin 3 to Net-(C67-Pad1).
Add R9 (footprint "Resistor_SMD:R_0805_2012Metric").
Change REF** reference to R9.
Change R9 value from R_0805_2012Metric to 10k.
Change REF** reference to R4.
Connect R2 pin 1 to Net-(C11-Pad1).
Connect U11 pin 22 to GNDPWR.
Add R8 (footprint "Resistor_SMD:R_0805_2012Metric").
Change REF** reference to R3.
Change R3 value from R_0805_2012Metric to 12k.
Connect U11 pin 23 to QAIN.
Connect R3 pin 2 to Net-(C11-Pad1).
Connect R3 pin 1 to Net-(C17-Pad1).
Connect U11 pin 24 to Net-(R19-Pad2).
Add R4 (footprint "Resistor_SMD:R_0805_2012Metric").
Connect U11 pin 25 to DEM_Q_P.
Connect R9 pin 2 to Net-(C36-Pad1).
Change R4 value from R_0805_2012Metric to 100k.
Connect U11 pin 26 to DEM_Q_N.
Connect U2 pin 6 to +12VA.
Change RV1 value from R_0805_2012Metric to 5k.
Connect U11 pin 27 to GNDPWR.
Connect U11 pin 28 to ADF_LON.
Add R5 (footprint "Resistor_SMD:R_0805_2012Metric").
Change REF** reference to R5.
Change R5 value from R_0805_2012Metric to 100k.
Connect R5 pin 2 to GNDPWR.
Connect R5 pin 1 to Net-(R5-Pad1).
Change RV2 value from R_0805_2012Metric to 5k.
Connect U2 pin 5 to Net-(C25-Pad1).
Add RV1 (footprint "Resistor_SMD:R_0805_2012Metric").
Change REF** reference to RV1.
Connect U2 pin 2 to GNDPWR.
Connect U11 pin 4 to DEM_I_P.
Connect U2 pin 7 to Net-(U2-Pad7).
Connect RV1 pin 2 to Net-(C59-Pad1).
Connect RV1 pin 1 to Net-(C59-Pad1).
Connect U2 pin 8 to Net-(C12-Pad1).
Add RV2 (footprint "Resistor_SMD:R_0805_2012Metric").
Change REF** reference to RV2.
Connect R36 pin 1 to Net-(C83-Pad1).
Change U2 value from SO-8_3.9x4.9mm_P1.27mm to LM386.
Connect RV2 pin 2 to Net-(C59-Pad1).
Change REF** reference to U2.
Change REF** reference to R34.
Change R34 value from R_0805_2012Metric to 2.
Add RV3 (footprint "Resistor_SMD:R_0805_2012Metric").
Change REF** reference to RV3.
Change RV3 value from R_0805_2012Metric to 5k.
Connect RV3 pin 2 to Net-(RV3-Pad2).
Connect RV3 pin 1 to Net-(R15-Pad2).
Connect U1 pin 1 to RXUART_TX.
Change REF** reference to R35.
Connect R33 pin 2 to Net-(L15-Pad2).
Connect R33 pin 1 to Net-(C76-Pad2).
Add R34 (footprint "Resistor_SMD:R_0805_2012Metric").
Change U3 value from SO-8_3.9x4.9mm_P1.27mm to LM4562.
Connect RV2 pin 1 to Net-(C59-Pad1).
Add U2 (footprint "Package_SO:SO-8_3.9x4.9mm_P1.27mm").
Connect R34 pin 2 to IAIN.
Connect R34 pin 1 to Net-(L16-Pad1).
Change REF** reference to U3.
Add U3 (footprint "Package_SO:SO-8_3.9x4.9mm_P1.27mm").
Add R35 (footprint "Resistor_SMD:R_0805_2012Metric").
Connect U1 pin 2 to RXUART_RX.
Change R35 value from R_0805_2012Metric to 3.3k.
Connect U2 pin 1 to Net-(C12-Pad2).
Connect R35 pin 2 to Net-(C83-Pad1).
Connect R35 pin 1 to DEM_Q_N.
Connect U1 pin 16 to ILI_CS.
Connect U1 pin 17 to ADF_RX_LE.
Add R36 (footprint "Resistor_SMD:R_0805_2012Metric").
Change R36 value from R_0805_2012Metric to 4.7k.
Connect U2 pin 3 to Net-(C10-Pad1).
Connect U2 pin 4 to GNDPWR.
Connect R36 pin 2 to Net-(C84-Pad1).
Connect U1 pin 32 to RX_Q.
Connect U1 pin 11 to KEYRX2.
Connect U1 pin 12 to KEYRX3.
Connect U1 pin 13 to GNDPWR.
Connect U1 pin 14 to ILI_SCK.
Connect U1 pin 15 to ILI_MOSI.
Connect U1 pin 8 to GNDPWR.
Connect U6 pin 3 to +5V.
Connect U1 pin 18 to GNDPWR.
Connect U1 pin 34 to Net-(U1-Pad34).
Connect U1 pin 33 to GNDPWR.
Connect U1 pin 19 to ADF_RX_CLK.
Connect U1 pin 10 to KEYRX1.
Connect U1 pin 31 to RX_I.
Connect U1 pin 30 to RST_RX.
Connect U1 pin 29 to Net-(R1-Pad2).
Connect U1 pin 28 to GNDPWR.
Connect U1 pin 20 to ADF_RX_DATA.
Connect U1 pin 27 to Net-(U1-Pad27).
Connect SW1 pin 1 to RST_RX.
Connect SW1 pin 1 to RST_RX.
Connect U1 pin 25 to LCD_SCL.
Connect U1 pin 21 to MCU_SDA.
Connect U1 pin 24 to LCD_SDA.
Connect U1 pin 23 to GNDPWR.
Change REF** reference to U1.
Add SW1 (footprint "ADX_FOOTPRINT_LIBRARY:SW_Push_1P1T_NO_6x6mm_H9.5mm").
Change REF** reference to SW1.
Change SW1 value from SW_Push_1P1T_NO_6x6mm_H9.5mm Mod to RESET.
Connect U1 pin 3 to GNDPWR.
Connect U1 pin 4 to ROTRX_A.
Connect SW1 pin 2 to GNDPWR.
Change REF** reference to U7.
Connect U1 pin 26 to LNA_Cont.
Connect SW1 pin 2 to GNDPWR.
Connect U1 pin 5 to ROTRX_B.
Add U1 (footprint "RP2040_PICO:RPI2040_PICO_SMD").
Connect U3 pin 8 to Net-(C19-Pad1).
Connect U1 pin 6 to ILI_DC.
Change U1 value from RPI_PICO to RP2040_PICO.
Connect U1 pin 7 to ILI_RST.
Connect U1 pin 40 to Net-(C19-Pad1).
Connect U1 pin 39 to Net-(U1-Pad39).
Connect U1 pin 38 to GNDPWR.
Connect R25 pin 2 to Net-(C72-Pad1).
Connect U1 pin 37 to Net-(U1-Pad37).
Connect U1 pin 35 to Net-(U1-Pad35).
Connect U1 pin 9 to ROTRX_SW.
Connect U5 pin 2 to +5V.
Connect R24 pin 2 to DEM_Q_P.
Connect R24 pin 1 to Net-(C82-Pad1).
Change U6 value from SOT-223-3_TabPin2 to LM1117-3.3.
Add R25 (footprint "Resistor_SMD:R_0805_2012Metric").
Change REF** reference to U6.
Change REF** reference to R25.
Change R25 value from R_0805_2012Metric to 57.6R.
Add U6 (footprint "Package_TO_SOT_SMD:SOT-223-3_TabPin2").
Add R27 (footprint "Resistor_SMD:R_0805_2012Metric").
Connect R25 pin 1 to GNDPWR.
Change R24 value from R_0805_2012Metric to 3.3k.
Add R26 (footprint "Resistor_SMD:R_0805_2012Metric").
Change REF** reference to R26.
Change R26 value from R_0805_2012Metric to 174R.
Connect U5 pin 2 to +5V.
Connect U5 pin 3 to +12VA.
Connect R26 pin 2 to Net-(C72-Pad1).
Connect R26 pin 1 to Net-(C70-Pad2).
Connect U5 pin 1 to GNDPWR.
Change REF** reference to R27.
Connect U1 pin 36 to Net-(U1-Pad36).
Change R27 value from R_0805_2012Metric to 100.
Connect R22 pin 1 to Net-(C67-Pad1).
Change R21 value from R_0805_2012Metric to 3.3k.
Connect U7 pin 6 to LNA_Cont.
Connect U7 pin 1 to GNDPWR.
Connect R21 pin 2 to Net-(C80-Pad1).
Connect R21 pin 1 to DEM_I_N.
Add R22 (footprint "Resistor_SMD:R_0805_2012Metric").
Change REF** reference to R22.
Change U7 value from IC_BGC100GN6E6327XTSA1 to MXD8015LL.
Change R22 value from R_0805_2012Metric to 3.3k.
Connect R22 pin 2 to DEM_I_P.
Change C52 value from C_0805_2012Metric to 100nF.
Change U5 value from SOT-223-3_TabPin2 to LM1117-5.0.
Add U7 (footprint "BGA7L1BN6:IC_BGC100GN6E6327XTSA1").
Add R23 (footprint "Resistor_SMD:R_0805_2012Metric").
Change REF** reference to R23.
Change R23 value from R_0805_2012Metric to 4.7k.
Connect U6 pin 2 to +3V3.
Connect R23 pin 2 to Net-(C68-Pad2).
Connect U1 pin 22 to MCU_SCL.
Connect R23 pin 1 to Net-(C80-Pad1).
Add R24 (footprint "Resistor_SMD:R_0805_2012Metric").
Change REF** reference to R24.
Connect U3 pin 3 to Net-(R5-Pad1).
Change REF** reference to U4.
Add R32 (footprint "Resistor_SMD:R_0805_2012Metric").
Connect R30 pin 2 to QMXO.
Connect R30 pin 1 to Net-(C76-Pad1).
Add U4 (footprint "Package_TO_SOT_SMD:SOT-223-3_TabPin2").
Add R31 (footprint "Resistor_SMD:R_0805_2012Metric").
Change REF** reference to R31.
Change R31 value from R_0805_2012Metric to 2.
Connect U3 pin 1 to Net-(C17-Pad1).
Connect R31 pin 2 to Net-(L13-Pad2).
Connect R31 pin 1 to Net-(C74-Pad1).
Connect U3 pin 2 to Net-(C17-Pad2).
Change C34 value from C_0805_2012Metric to 100nF.
Connect C34 pin 2 to GNDPWR.
Change REF** reference to R32.
Change R32 value from R_0805_2012Metric to 2.
Connect U3 pin 4 to GNDPWR.
Connect R32 pin 2 to Net-(L14-Pad2).
Connect U3 pin 5 to Net-(U3-Pad5).
Connect R32 pin 1 to Net-(C76-Pad2).
Connect U3 pin 6 to GNDPWR.
Add R33 (footprint "Resistor_SMD:R_0805_2012Metric").
Change REF** reference to R33.
Change R33 value from R_0805_2012Metric to 2.
Connect U7 pin 3 to AD8348_IN.
Change REF** reference to R29.
Connect R27 pin 2 to VCMO.
Connect R27 pin 1 to IAIN.
Change REF** reference to U5.
Add U5 (footprint "Package_TO_SOT_SMD:SOT-223-3_TabPin2").
Add R28 (footprint "Resistor_SMD:R_0805_2012Metric").
Change REF** reference to R28.
Change R28 value from R_0805_2012Metric to 100.
Connect R28 pin 2 to VCMO.
Connect U4 pin 2 to Net-(C34-Pad1).
Connect R28 pin 1 to QAIN.
Connect U4 pin 2 to Net-(C34-Pad1).
Connect U3 pin 7 to GNDPWR.
Add R29 (footprint "Resistor_SMD:R_0805_2012Metric").
Change R29 value from R_0805_2012Metric to 200.
Connect U4 pin 3 to +12VA.
Connect U4 pin 1 to GNDPWR.
Connect R29 pin 2 to IMXO.
Connect R29 pin 1 to Net-(C75-Pad1).
Add R30 (footprint "Resistor_SMD:R_0805_2012Metric").
Change REF** reference to R30.
Change R30 value from R_0805_2012Metric to 100.
Change U4 value from SOT-223-3_TabPin2 to LM1117-5.0.
Change REF** reference to C37.
Add C37 (footprint "Capacitor_SMD:C_0805_2012Metric").
Change REF** reference to C34.
Connect C34 pin 1 to Net-(C34-Pad1).
Add C35 (footprint "Capacitor_SMD:C_0805_2012Metric").
Change REF** reference to C35.
Change C35 value from C_0805_2012Metric to 1nF.
Connect C35 pin 2 to Net-(C35-Pad2).
Connect C35 pin 1 to Net-(C35-Pad1).
Add C36 (footprint "Capacitor_SMD:C_0805_2012Metric").
Change REF** reference to C36.
Change C36 value from C_0805_2012Metric to 100pF.
Connect C36 pin 2 to GNDPWR.
Connect C36 pin 1 to Net-(C36-Pad1).
Change REF** reference to C33.
Change REF** reference to R36.
Change C37 value from C_0805_2012Metric to 1nF.
Connect C37 pin 2 to GNDPWR.
Connect C37 pin 1 to Net-(C36-Pad1).
Add C51 (footprint "Capacitor_SMD:C_0805_2012Metric").
Change REF** reference to C51.
Change C51 value from C_0805_2012Metric to 100nF.
Connect C51 pin 2 to GNDPWR.
Connect C51 pin 1 to Net-(C36-Pad1).
Add C52 (footprint "Capacitor_SMD:C_0805_2012Metric").
Change REF** reference to C52.
Connect C28 pin 2 to GNDPWR.
Connect C28 pin 1 to +12VA.
Connect C52 pin 1 to Net-(C52-Pad1).
Change C30 value from CP_Elec_6.3x7.7 to 220uF/16V.
Connect C25 pin 1 to Net-(C25-Pad1).
Add C27 (footprint "Capacitor_SMD:C_0805_2012Metric").
Change REF** reference to C27.
Change C27 value from C_0805_2012Metric to 100nF.
Connect C27 pin 2 to GNDPWR.
Connect C27 pin 1 to +3V3.
Add C28 (footprint "Capacitor_SMD:CP_Elec_6.3x7.7").
Change REF** reference to C28.
Change C28 value from CP_Elec_6.3x7.7 to 100uF/16V.
Connect U11 pin 16 to QOFS.
Connect C52 pin 2 to GNDPWR.
Add C30 (footprint "Capacitor_SMD:CP_Elec_6.3x7.7").
Change REF** reference to C30.
Add C53 (footprint "Capacitor_SMD:C_0805_2012Metric").
Connect C30 pin 2 to Net-(C30-Pad2).
Connect C30 pin 1 to Net-(C25-Pad1).
Add C32 (footprint "Capacitor_SMD:C_0805_2012Metric").
Change REF** reference to C32.
Change C32 value from C_0805_2012Metric to 100nF.
Connect C32 pin 2 to GNDPWR.
Connect C32 pin 1 to +12VA.
Add C60 (footprint "Capacitor_SMD:C_0805_2012Metric").
Change REF** reference to C60.
Connect U6 pin 1 to GNDPWR.
Connect C33 pin 2 to Net-(C33-Pad2).
Connect C33 pin 1 to Net-(C17-Pad1).
Add C34 (footprint "Capacitor_SMD:C_0805_2012Metric").
Connect C61 pin 2 to GNDPWR.
Connect C58 pin 1 to Net-(C58-Pad1).
Add C59 (footprint "Capacitor_SMD:C_0805_2012Metric").
Change REF** reference to C59.
Change C59 value from C_0805_2012Metric to 1nF.
Connect C59 pin 2 to GNDPWR.
Connect C59 pin 1 to Net-(C59-Pad1).
Add C56 (footprint "Capacitor_SMD:C_0805_2012Metric").
Change REF** reference to C56.
Change C60 value from C_0805_2012Metric to 100nF.
Connect C60 pin 2 to GNDPWR.
Connect C60 pin 1 to Net-(C60-Pad1).
Add C61 (footprint "Capacitor_SMD:C_0805_2012Metric").
Change REF** reference to C61.
Change C61 value from C_0805_2012Metric to 10nF.
Connect C58 pin 2 to GNDPWR.
Connect C61 pin 1 to Net-(C59-Pad1).
Add C62 (footprint "Capacitor_SMD:C_0805_2012Metric").
Change REF** reference to C62.
Change C62 value from C_0805_2012Metric to 100nF.
Connect C53 pin 2 to GNDPWR.
Connect C53 pin 1 to IOFS.
Connect C62 pin 1 to +5V.
Add C63 (footprint "Capacitor_SMD:C_0805_2012Metric").
Change REF** reference to C63.
Change C63 value from C_0805_2012Metric to 1nF.
Connect C63 pin 2 to GNDPWR.
Connect C63 pin 1 to Net-(C59-Pad1).
Add C64 (footprint "Capacitor_SMD:CP_Elec_4x5.4").
Change REF** reference to C64.
Connect C55 pin 1 to Net-(C55-Pad1).
Change REF** reference to C53.
Change C53 value from C_0805_2012Metric to 100nF.
Connect C11 pin 1 to Net-(C11-Pad1).
Connect C62 pin 2 to GNDPWR.
Add C54 (footprint "Capacitor_SMD:CP_Elec_4x5.4").
Change REF** reference to C54.
Change C54 value from CP_Elec_4x5.4 to 10uF/16V.
Connect C54 pin 2 to GNDPWR.
Connect C54 pin 1 to +5V.
Add C55 (footprint "Capacitor_SMD:C_0805_2012Metric").
Change REF** reference to C55.
Change C55 value from C_0805_2012Metric to 100nF.
Connect C55 pin 2 to GNDPWR.
Connect C25 pin 2 to Net-(C25-Pad2).
Connect C2 pin 1 to ROTRX_B.
Change C56 value from C_0805_2012Metric to 100nF.
Connect C56 pin 2 to GNDPWR.
Connect C56 pin 1 to QOFS.
Add C57 (footprint "Capacitor_SMD:C_0805_2012Metric").
Change REF** reference to C57.
Change C57 value from C_0805_2012Metric to 100nF.
Connect C57 pin 2 to GNDPWR.
Connect C57 pin 1 to +5V.
Add C58 (footprint "Capacitor_SMD:C_0805_2012Metric").
Change REF** reference to C58.
Change C58 value from C_0805_2012Metric to 100nF.
Connect C9 pin 2 to GNDPWR.
Connect C6 pin 1 to KEYRX3.
Add C7 (footprint "Capacitor_SMD:CP_Elec_4x5.4").
Change REF** reference to C7.
Change C7 value from CP_Elec_4x5.4 to 4.7uF/16V.
Connect C7 pin 2 to Net-(C4-Pad1).
Connect C7 pin 1 to Net-(C10-Pad2).
Add C8 (footprint "Capacitor_SMD:C_0805_2012Metric").
Change REF** reference to C8.
Change C8 value from C_0805_2012Metric to 100nF.
Connect C8 pin 2 to GNDPWR.
Connect C8 pin 1 to KEYRX2.
Add C9 (footprint "Capacitor_SMD:C_0805_2012Metric").
Change REF** reference to C9.
Change C9 value from C_0805_2012Metric to 100nF.
Connect C6 pin 2 to GNDPWR.
Connect C9 pin 1 to KEYRX1.
Add C10 (footprint "Capacitor_SMD:CP_Elec_4x5.4").
Change REF** reference to C10.
Change C10 value from CP_Elec_4x5.4 to 4.7uF/16V.
Connect C10 pin 2 to Net-(C10-Pad2).
Connect C10 pin 1 to Net-(C10-Pad1).
Add C11 (footprint "Capacitor_SMD:C_0805_2012Metric").
Change REF** reference to C11.
Change C11 value from C_0805_2012Metric to 10nF.
Connect C11 pin 2 to GNDPWR.
Connect C17 pin 1 to Net-(C17-Pad1).
Add C12 (footprint "Capacitor_SMD:C_0805_2012Metric").
Change REF** reference to C12.
Connect C3 pin 1 to ROTRX_SW.
Change REF** reference to C1.
Change C1 value from C_0805_2012Metric to 100nF.
Connect C1 pin 2 to GNDPWR.
Connect C1 pin 1 to ROTRX_A.
Add C2 (footprint "Capacitor_SMD:C_0805_2012Metric").
Change REF** reference to C2.
Change C2 value from C_0805_2012Metric to 100nF.
Connect C2 pin 2 to GNDPWR.
Change REF** reference to C5.
Change C5 value from C_0805_2012Metric to 100nF.
Add C3 (footprint "Capacitor_SMD:C_0805_2012Metric").
Change REF** reference to C3.
Change C3 value from C_0805_2012Metric to 100nF.
Connect C3 pin 2 to GNDPWR.
Change C12 value from C_0805_2012Metric to 10uF.
Add C4 (footprint "Capacitor_SMD:C_0805_2012Metric").
Change REF** reference to C4.
Change C4 value from C_0805_2012Metric to 4.7nF.
Connect C4 pin 2 to GNDPWR.
Connect C4 pin 1 to Net-(C4-Pad1).
Add C5 (footprint "Capacitor_SMD:C_0805_2012Metric").
Connect C12 pin 1 to Net-(C12-Pad1).
Change REF** reference to C19.
Connect C5 pin 2 to GNDPWR.
Connect C5 pin 1 to +5V.
Add C6 (footprint "Capacitor_SMD:C_0805_2012Metric").
Change REF** reference to C6.
Change C6 value from C_0805_2012Metric to 100nF.
Connect C21 pin 1 to +5V.
Change REF** reference to C18.
Change C18 value from C_0805_2012Metric to 100nF.
Connect C18 pin 2 to GNDPWR.
Connect C18 pin 1 to +12VA.
Connect C22 pin 1 to +12VA.
Connect C22 pin 2 to GNDPWR.
Change C22 value from C_0805_2012Metric to 100nF.
Change REF** reference to C22.
Add C22 (footprint "Capacitor_SMD:C_0805_2012Metric").
Add C18 (footprint "Capacitor_SMD:C_0805_2012Metric").
Connect C21 pin 2 to GNDPWR.
Change C21 value from C_0805_2012Metric to 100nF.
Change REF** reference to C21.
Add C21 (footprint "Capacitor_SMD:C_0805_2012Metric").
Connect C19 pin 1 to Net-(C19-Pad1).
Connect C19 pin 2 to GNDPWR.
Change C19 value from C_0805_2012Metric to 100nF.
Add C19 (footprint "Capacitor_SMD:C_0805_2012Metric").
Add C23 (footprint "Capacitor_SMD:CP_Elec_4x5.4").
Change REF** reference to C23.
Change C23 value from CP_Elec_4x5.4 to 10uF/16V.
Connect C23 pin 2 to GNDPWR.
Connect C23 pin 1 to +5V.
Add C25 (footprint "Capacitor_SMD:C_0805_2012Metric").
Change REF** reference to C25.
Change C33 value from CP_Elec_4x5.4 to 4.7uF/16V.
Change C25 value from C_0805_2012Metric to 47nF.
Change REF** reference to C15.
Connect C12 pin 2 to Net-(C12-Pad2).
Change C15 value from CP_Elec_6.3x7.7 to 100uF/16V.
Connect C15 pin 2 to GNDPWR.
Change REF** reference to C13.
Change C13 value from C_0805_2012Metric to 100pF.
Connect C13 pin 2 to Net-(C13-Pad2).
Connect C13 pin 1 to Net-(C13-Pad1).
Add C14 (footprint "Capacitor_SMD:C_0805_2012Metric").
Change REF** reference to C14.
Change C14 value from C_0805_2012Metric to 1nF.
Connect C14 pin 2 to Net-(C13-Pad2).
Connect C14 pin 1 to Net-(C13-Pad1).
Add C15 (footprint "Capacitor_SMD:CP_Elec_6.3x7.7").
Add L13 (footprint "Inductor_SMD:L_0805_2012Metric").
Connect J2 pin 5 to KEYRX1.
Add C13 (footprint "Capacitor_SMD:C_0805_2012Metric").
Connect C15 pin 1 to +12VA.
Add C16 (footprint "Capacitor_SMD:CP_Elec_4x5.4").
Change REF** reference to C16.
Change C16 value from CP_Elec_4x5.4 to 10uF/16V.
Connect C16 pin 2 to GNDPWR.
Connect C16 pin 1 to +12VA.
Add C17 (footprint "Capacitor_SMD:C_0805_2012Metric").
Change REF** reference to C17.
Change C17 value from C_0805_2012Metric to 220pF.
Connect C17 pin 2 to Net-(C17-Pad2).
Connect J2 pin 17 to LCD_SDA.
Connect J2 pin 16 to LCD_SCL.
Connect J1 pin 5 to ILI_RST.
Connect J1 pin 4 to ILI_SCK.
Connect J1 pin 3 to ILI_MOSI.
Connect J1 pin 2 to ILI_CS.
Connect J1 pin 1 to ILI_DC.
Add J2 (footprint "Connector_PinHeader_2.54mm:PinHeader_1x20_P2.54mm_Vertical").
Change REF** reference to J2.
Change J2 value from PinHeader_1x20_P2.54mm_Vertical to PATCH02.
Connect J2 pin 20 to GNDPWR.
Connect J2 pin 19 to GNDPWR.
Connect J2 pin 18 to GNDPWR.
Connect C64 pin 2 to GNDPWR.
Connect J2 pin 14 to TXUART_RX.
Connect J2 pin 15 to RST_RX.
Connect J1 pin 6 to ILI+5V.
Connect J2 pin 13 to TXUART_TX.
Connect J2 pin 12 to MCU_SDA.
Connect J2 pin 11 to MCU_SCL.
Connect J2 pin 10 to +3V3.
Connect J2 pin 9 to +5V.
Connect J2 pin 8 to RXUART_RX.
Connect J2 pin 7 to RXUART_TX.
Connect J2 pin 6 to ROTRX_SW.
Change REF** reference to L11.
Connect J2 pin 3 to KEYRX3.
Connect J2 pin 2 to ROTRX_A.
Connect J2 pin 1 to ROTRX_B.
Connect J1 pin 20 to GNDPWR.
Change REF** reference to FL1.
Change FL1 value from SM3030-8_RFI to SF2126E.
Connect FL1 pin 4 to GNDPWR.
Connect FL1 pin 6 to GNDPWR.
Connect FL1 pin 8 to GNDPWR.
Connect FL1 pin 2 to GNDPWR.
Connect FL1 pin 7 to GNDPWR.
Connect FL1 pin 5 to Net-(C35-Pad2).
Connect FL1 pin 3 to GNDPWR.
Connect FL1 pin 1 to Net-(C13-Pad1).
Add J1 (footprint "Connector_PinHeader_2.54mm:PinHeader_1x20_P2.54mm_Vertical").
Change REF** reference to J1.
Change J1 value from PinHeader_1x20_P2.54mm_Vertical to PATCH01.
Add J3 (footprint "uSDX_MONO_PCB_Library:Jack_3.5mm_PJ-320B-SMT_Horizontal_CORR").
Connect J1 pin 19 to GNDPWR.
Connect J1 pin 18 to GNDPWR.
Connect J1 pin 17 to PTT.
Connect J1 pin 16 to ROTX_SW.
Connect J1 pin 15 to ROTX_B.
Connect J1 pin 14 to ROTX_A.
Connect J1 pin 13 to KEYTX3.
Connect J1 pin 12 to KEYTX2.
Connect J1 pin 11 to KEYTX1.
Connect J1 pin 10 to TX+3.3V.
Connect J1 pin 9 to TX+5V.
Connect J1 pin 8 to +12V.
Connect J1 pin 7 to RST_TX.
Change L5 value from L_1210_3225Metric to 100uH.
Connect L2 pin 1 to +12V.
Add L3 (footprint "Inductor_SMD:L_0402_1005Metric").
Change REF** reference to L3.
Change L3 value from L_0402_1005Metric to 33nH.
Connect L3 pin 2 to Net-(L3-Pad2).
Add C73 (footprint "Capacitor_SMD:C_0805_2012Metric").
Add L4 (footprint "Inductor_SMD:L_1210_3225Metric").
Change REF** reference to L4.
Change L4 value from L_1210_3225Metric to 100uH.
Connect L4 pin 2 to ILI+5V.
Connect L4 pin 1 to Net-(C34-Pad1).
Add L5 (footprint "Inductor_SMD:L_1210_3225Metric").
Change REF** reference to L5.
Connect L2 pin 2 to Net-(C13-Pad2).
Connect L5 pin 2 to Net-(C36-Pad1).
Connect L5 pin 1 to +3V3.
Add L11 (footprint "Inductor_SMD:L_1210_3225Metric").
Connect J2 pin 4 to KEYRX2.
Change L11 value from L_1210_3225Metric to 100uH.
Connect L11 pin 2 to Net-(C59-Pad1).
Connect L11 pin 1 to +5V.
Add L12 (footprint "Inductor_SMD:L_1210_3225Metric").
Change REF** reference to L12.
Change L12 value from L_1210_3225Metric to 100uH.
Connect L12 pin 2 to +5V.
Connect L12 pin 1 to Net-(C55-Pad1).
Change REF** reference to L13.
Add J6 (footprint "uSDX_MONO_PCB_Library:Jack_3.5mm_PJ-320B-SMT_Horizontal_CORR").
Change REF** reference to J3.
Change J3 value from Jack_3.5mm_PJ-320B-SMT_Horizontal_CORR to HEADPHONE.
Connect J3 pin R to GNDPWR.
Connect J3 pin S to GNDPWR.
Connect J3 pin T to Net-(C33-Pad2).
Add J5 (footprint "Connector_Coaxial:SMA_Samtec_SMA-J-P-X-ST-EM1_EdgeMount").
Change REF** reference to J5.
Change J5 value from SMA_Samtec_SMA-J-P-X-ST-EM1_EdgeMount to SMA RF Input.
Connect J5 pin 1 to Net-(C13-Pad2).
Connect J5 pin 2 to GNDPWR.
Connect J5 pin 2 to GNDPWR.
Connect J5 pin 2 to GNDPWR.
Connect J5 pin 2 to GNDPWR.
Add R3 (footprint "Resistor_SMD:R_0805_2012Metric").
Change REF** reference to J6.
Change J6 value from Jack_3.5mm_PJ-320B-SMT_Horizontal_CORR to SPEAKER.
Connect J6 pin R to GNDPWR.
Connect J6 pin S to GNDPWR.
Connect J6 pin T to Net-(C30-Pad2).
Add L1 (footprint "Inductor_SMD:L_1210_3225Metric").
Change REF** reference to L1.
Change L1 value from L_1210_3225Metric to 100uH.
Connect L1 pin 2 to Net-(C19-Pad1).
Connect L1 pin 1 to +5V.
Add L2 (footprint "Inductor_SMD:L_1210_3225Metric").
Change REF** reference to L2.
Change L2 value from L_1210_3225Metric to 100uH.
Change REF** reference to C66.
Change REF** reference to C70.
Change C70 value from C_0805_2012Metric to 820pF.
Connect C70 pin 2 to Net-(C70-Pad2).
Connect C70 pin 1 to Net-(C70-Pad1).
Add C71 (footprint "Capacitor_SMD:C_0805_2012Metric").
Change REF** reference to C71.
Change C71 value from C_0805_2012Metric to 82pF.
Connect C71 pin 2 to VCMO.
Connect C71 pin 1 to QAIN.
Add C72 (footprint "Capacitor_SMD:C_0805_2012Metric").
Change REF** reference to C72.
Connect C74 pin 1 to Net-(C74-Pad1).
Add C75 (footprint "Capacitor_SMD:C_0805_2012Metric").
Connect C72 pin 2 to AD8348_IN.
Connect C72 pin 1 to Net-(C72-Pad1).
Add C70 (footprint "Capacitor_SMD:C_0805_2012Metric").
Change REF** reference to C73.
Change C73 value from C_0805_2012Metric to 82pF.
Connect C73 pin 2 to VCMO.
Connect C73 pin 1 to IAIN.
Add C74 (footprint "Capacitor_SMD:C_0805_2012Metric").
Change REF** reference to C74.
Change C74 value from C_0805_2012Metric to 150pF.
Connect C74 pin 2 to VCMO.
Change C82 value from C_0805_2012Metric to 47nF.
Connect C82 pin 2 to GNDPWR.
Change REF** reference to C75.
Change C75 value from C_0805_2012Metric to 4.7pF.
Connect C75 pin 2 to Net-(C74-Pad1).
Change REF** reference to C67.
Change C64 value from CP_Elec_4x5.4 to 10uF/16V.
Connect C64 pin 1 to +5V.
Add C65 (footprint "Capacitor_SMD:C_0805_2012Metric").
Change REF** reference to C65.
Change C65 value from C_0805_2012Metric to 10nF.
Connect C65 pin 2 to GNDPWR.
Add C66 (footprint "Capacitor_SMD:C_0805_2012Metric").
Connect C68 pin 2 to Net-(C68-Pad2).
Change C66 value from C_0805_2012Metric to 100nF.
Connect C66 pin 2 to Net-(C55-Pad1).
Connect C66 pin 1 to GNDPWR.
Add C67 (footprint "Capacitor_SMD:C_0805_2012Metric").
Connect D1 pin 1 to +12VA.
Change C67 value from C_0805_2012Metric to 47nF.
Connect C67 pin 2 to GNDPWR.
Connect C67 pin 1 to Net-(C67-Pad1).
Add C68 (footprint "Capacitor_SMD:C_0805_2012Metric").
Change REF** reference to C68.
Change C68 value from C_0805_2012Metric to 1uF.
Change REF** reference to C76.
Connect C68 pin 1 to RX_I.
Add C69 (footprint "Capacitor_SMD:C_0805_2012Metric").
Change REF** reference to C69.
Change C69 value from C_0805_2012Metric to 820pF.
Connect C69 pin 2 to GNDPWR.
Connect C69 pin 1 to Net-(C69-Pad1).
Change REF** reference to C84.
Connect C81 pin 2 to Net-(C80-Pad1).
Connect C81 pin 1 to Net-(C68-Pad2).
Add C82 (footprint "Capacitor_SMD:C_0805_2012Metric").
Change REF** reference to C82.
Change C72 value from C_0805_2012Metric to 1nF.
Connect C82 pin 1 to Net-(C82-Pad1).
Add C83 (footprint "Capacitor_SMD:C_0805_2012Metric").
Change REF** reference to C83.
Change C83 value from C_0805_2012Metric to 47nF.
Connect C83 pin 2 to GNDPWR.
Connect C83 pin 1 to Net-(C83-Pad1).
Add C84 (footprint "Capacitor_SMD:C_0805_2012Metric").
Add C76 (footprint "Capacitor_SMD:C_0805_2012Metric").
Change C84 value from C_0805_2012Metric to 220pF.
Connect C84 pin 2 to Net-(C83-Pad1).
Connect C84 pin 1 to Net-(C84-Pad1).
Add C85 (footprint "Capacitor_SMD:C_0805_2012Metric").
Add C81 (footprint "Capacitor_SMD:C_0805_2012Metric").
Change C85 value from C_0805_2012Metric to 1uF.
Connect C85 pin 2 to Net-(C84-Pad1).
Connect C85 pin 1 to RX_I.
Add D1 (footprint "Diode_SMD:D_SMA").
Change REF** reference to D1.
Change D1 value from D_SMA to SS34.
Connect D1 pin 2 to +12V.
Add FL1 (footprint "SPF2126E:SF2126E").
Change REF** reference to C81.
Connect C75 pin 1 to Net-(C75-Pad1).
Connect L3 pin 1 to Net-(C35-Pad1).
Connect C78 pin 2 to IAIN.
Connect C65 pin 1 to Net-(C59-Pad1).
Connect C76 pin 2 to Net-(C76-Pad2).
Connect C76 pin 1 to Net-(C76-Pad1).
Add C77 (footprint "Capacitor_SMD:C_0805_2012Metric").
Change C77 value from C_0805_2012Metric to 8.2pF.
Connect C77 pin 2 to Net-(C76-Pad2).
Connect C77 pin 1 to QAIN.
Add C78 (footprint "Capacitor_SMD:C_0805_2012Metric").
Change REF** reference to C78.
Change C78 value from C_0805_2012Metric to 8.2pF.
Connect C78 pin 1 to Net-(C74-Pad1).
Change C81 value from C_0805_2012Metric to 220pF.
Change C76 value from C_0805_2012Metric to 4.7pF.
Connect C80 pin 1 to Net-(C80-Pad1).
Connect C80 pin 2 to GNDPWR.
Change C80 value from C_0805_2012Metric to 47nF.
Change REF** reference to C80.
Add C80 (footprint "Capacitor_SMD:C_0805_2012Metric").
Connect C79 pin 1 to Net-(C76-Pad2).
Connect C79 pin 2 to VCMO.
Change C79 value from C_0805_2012Metric to 150pF.
Change REF** reference to C79.
Add C79 (footprint "Capacitor_SMD:C_0805_2012Metric").
Change REF** reference to C85.
Error: RV1 pad 3 not found in Resistor_SMD:R_0805_2012Metric.
Error: RV2 pad 3 not found in Resistor_SMD:R_0805_2012Metric.
Error: RV3 pad 3 not found in Resistor_SMD:R_0805_2012Metric.

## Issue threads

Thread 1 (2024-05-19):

RX Prototipindeki  tespit edilen hatalar ve modifikasyonlar.

partal, 2024-05-19:
Prototip üzerinde çalışırken aşağıdaki sorunları tespi eddik ve düzeltmeleri yaptık.
@barisdinc @wb2cba

- [ ] Mod 1: pin 13,16 100 nf > gnd
Değişken gerilim bölücüler iptal.
Figure 49. Basic Connections
Schematic

- [ ] Mod 2 :U3B pin7-pin5 bağlanacak .  Opamp çıkışı gnd ye kısadevre.
- [ ] Mod 3: R11 iptal  tcxo kontrol pini negatif te ikende çalıştı .
- [ ] Mod 4: Opampların pozitif girişleri polarıldı.
İnvert sinyaller kullanılmadı.
AC kuplaj için kontensatör ilave edildi.

Hatırladığım kadar giriş dirençleri yükseltildi
Detay için modifiyeli karta bak
- [ ] Mod 5:Şemada ROTRX_SW j2-6 gidiyor .
Oysa pcb de J1-7 ge bağlanmış. PCB düzeltilecek.
- [ ] Mod 6: U3A pin e 3 pozitife  verilercek. örnek R12
- [ ] Mod 7 :  Lop filitredeki serikol ters dönecek. C43 R17  yerdeğişecek.
[Rx_modi.pdf](https://github.com/barisdinc/N3B_SDR_Transceiver_HW/files/15370299/Rx_modi.pdf)

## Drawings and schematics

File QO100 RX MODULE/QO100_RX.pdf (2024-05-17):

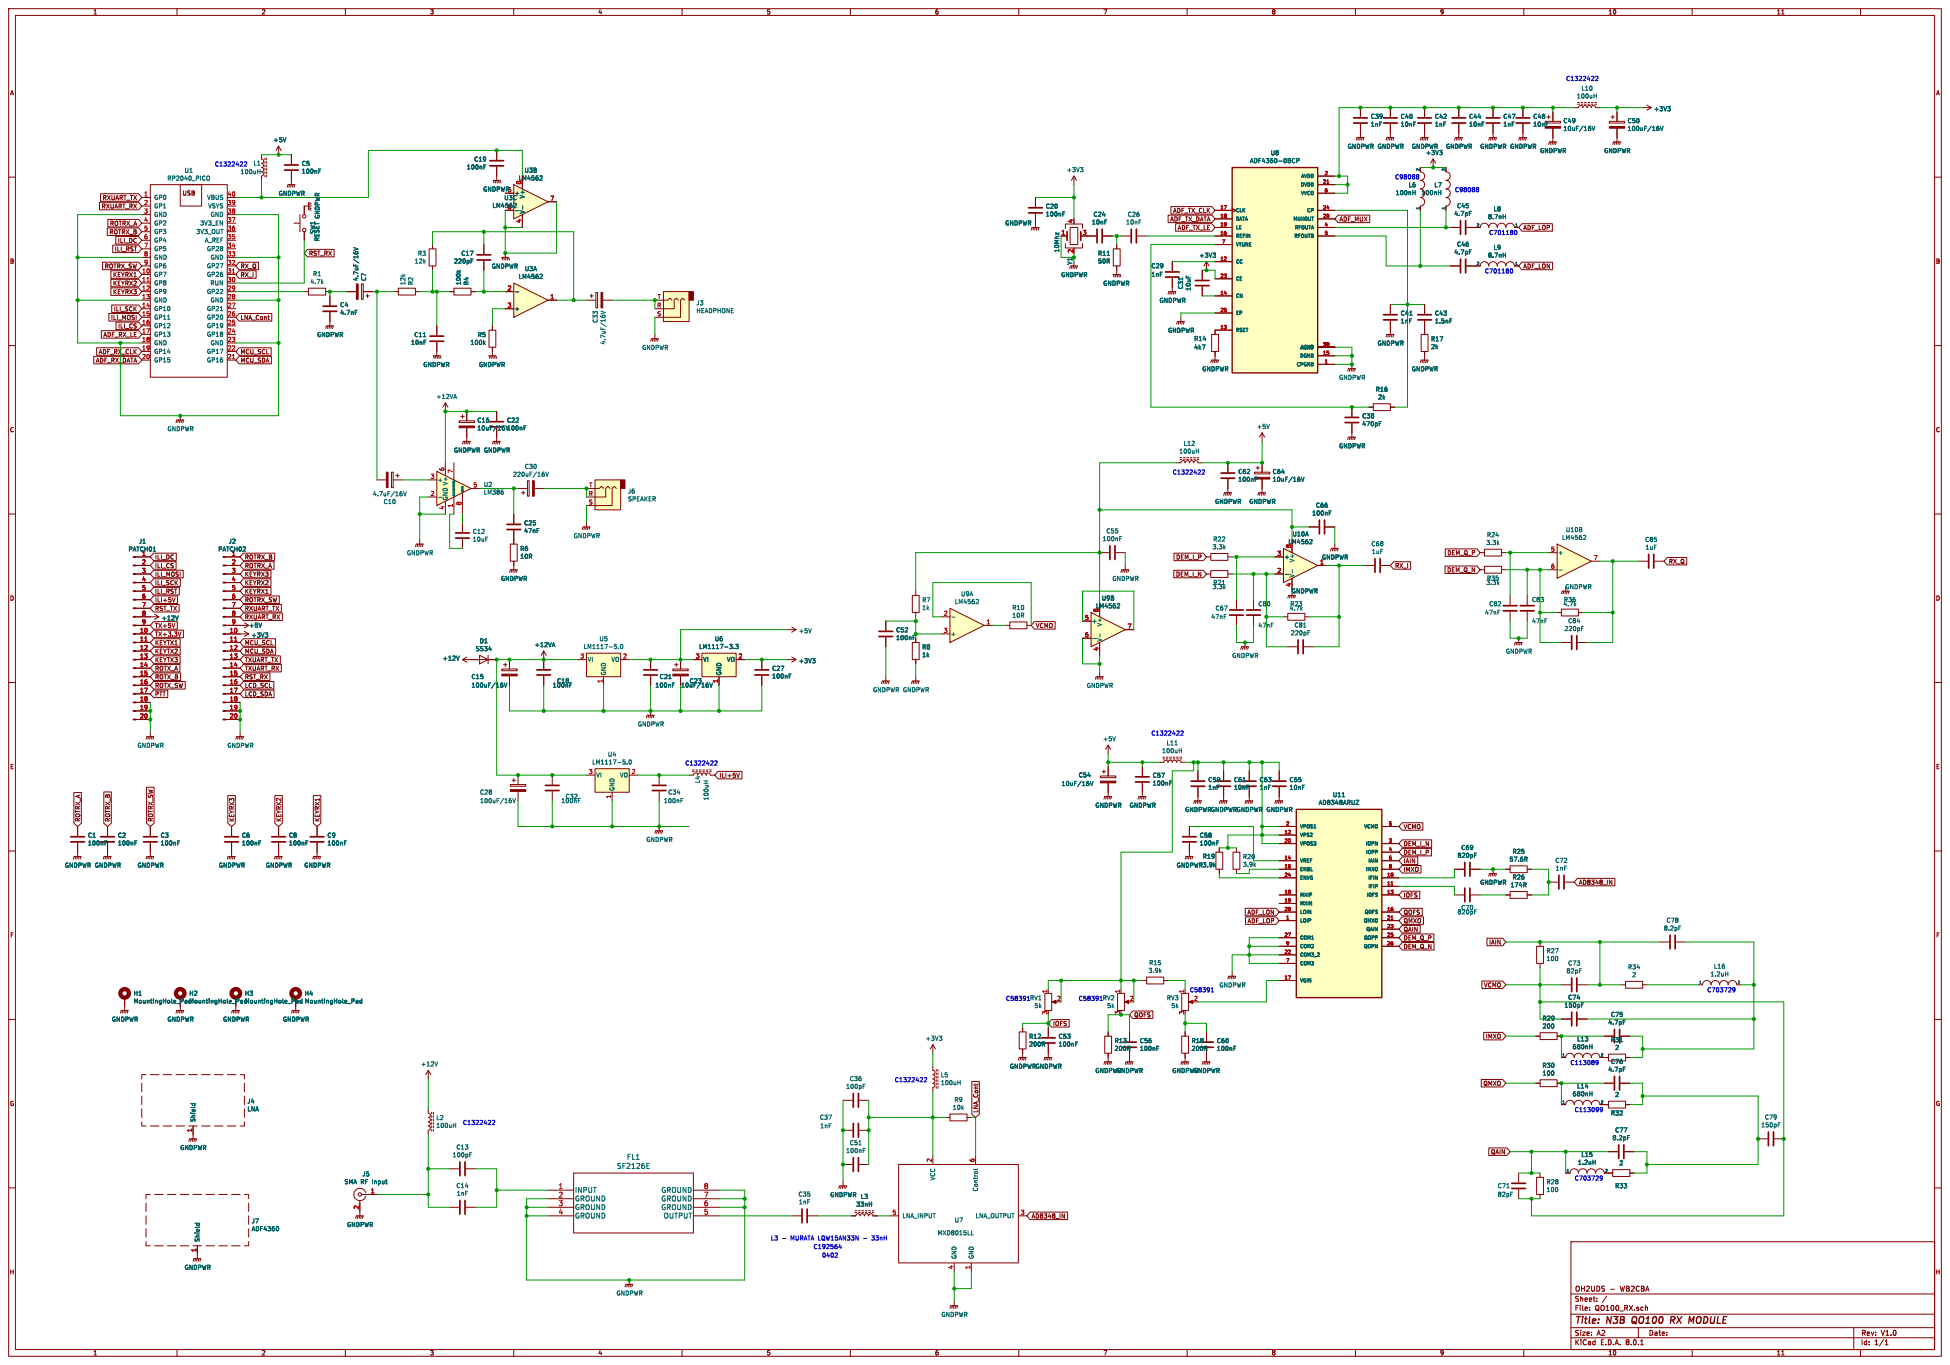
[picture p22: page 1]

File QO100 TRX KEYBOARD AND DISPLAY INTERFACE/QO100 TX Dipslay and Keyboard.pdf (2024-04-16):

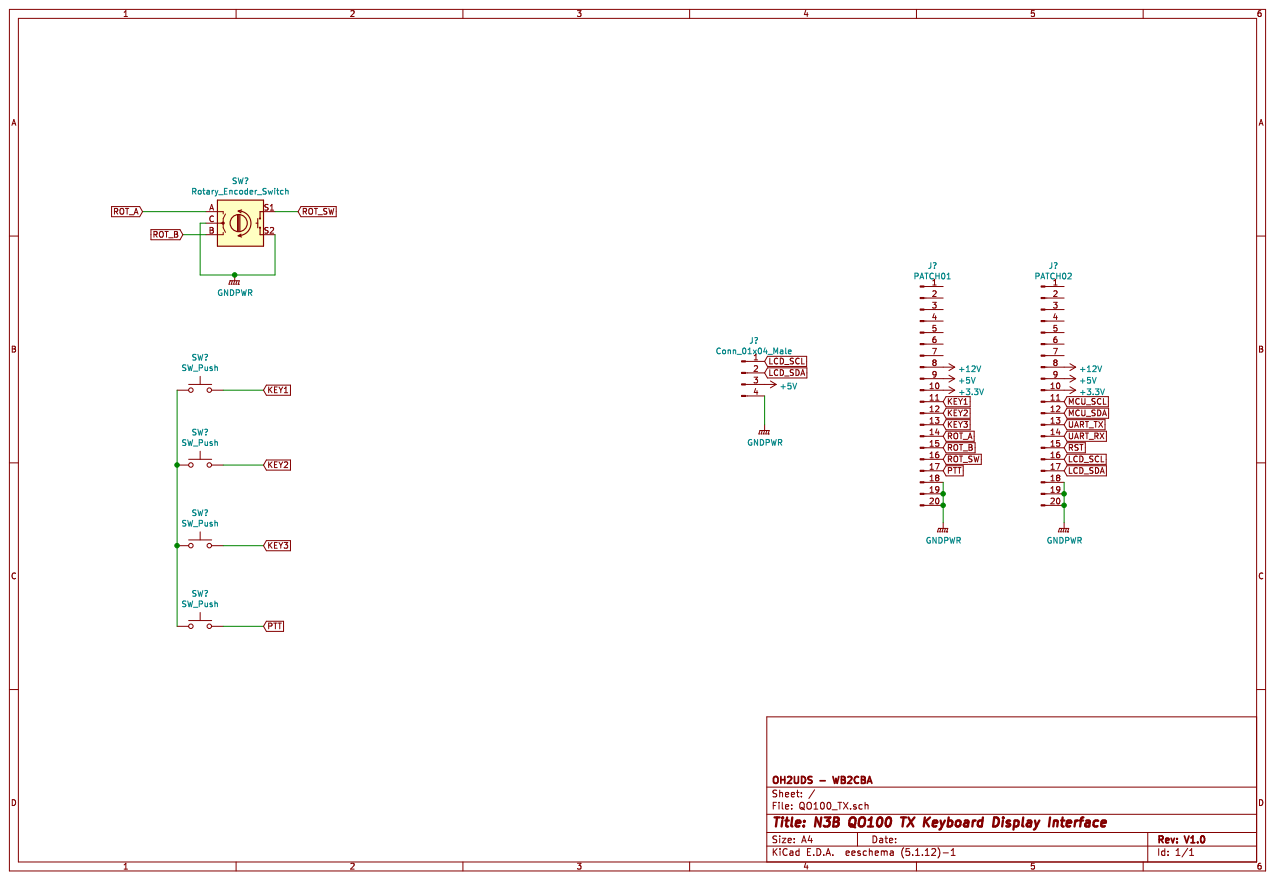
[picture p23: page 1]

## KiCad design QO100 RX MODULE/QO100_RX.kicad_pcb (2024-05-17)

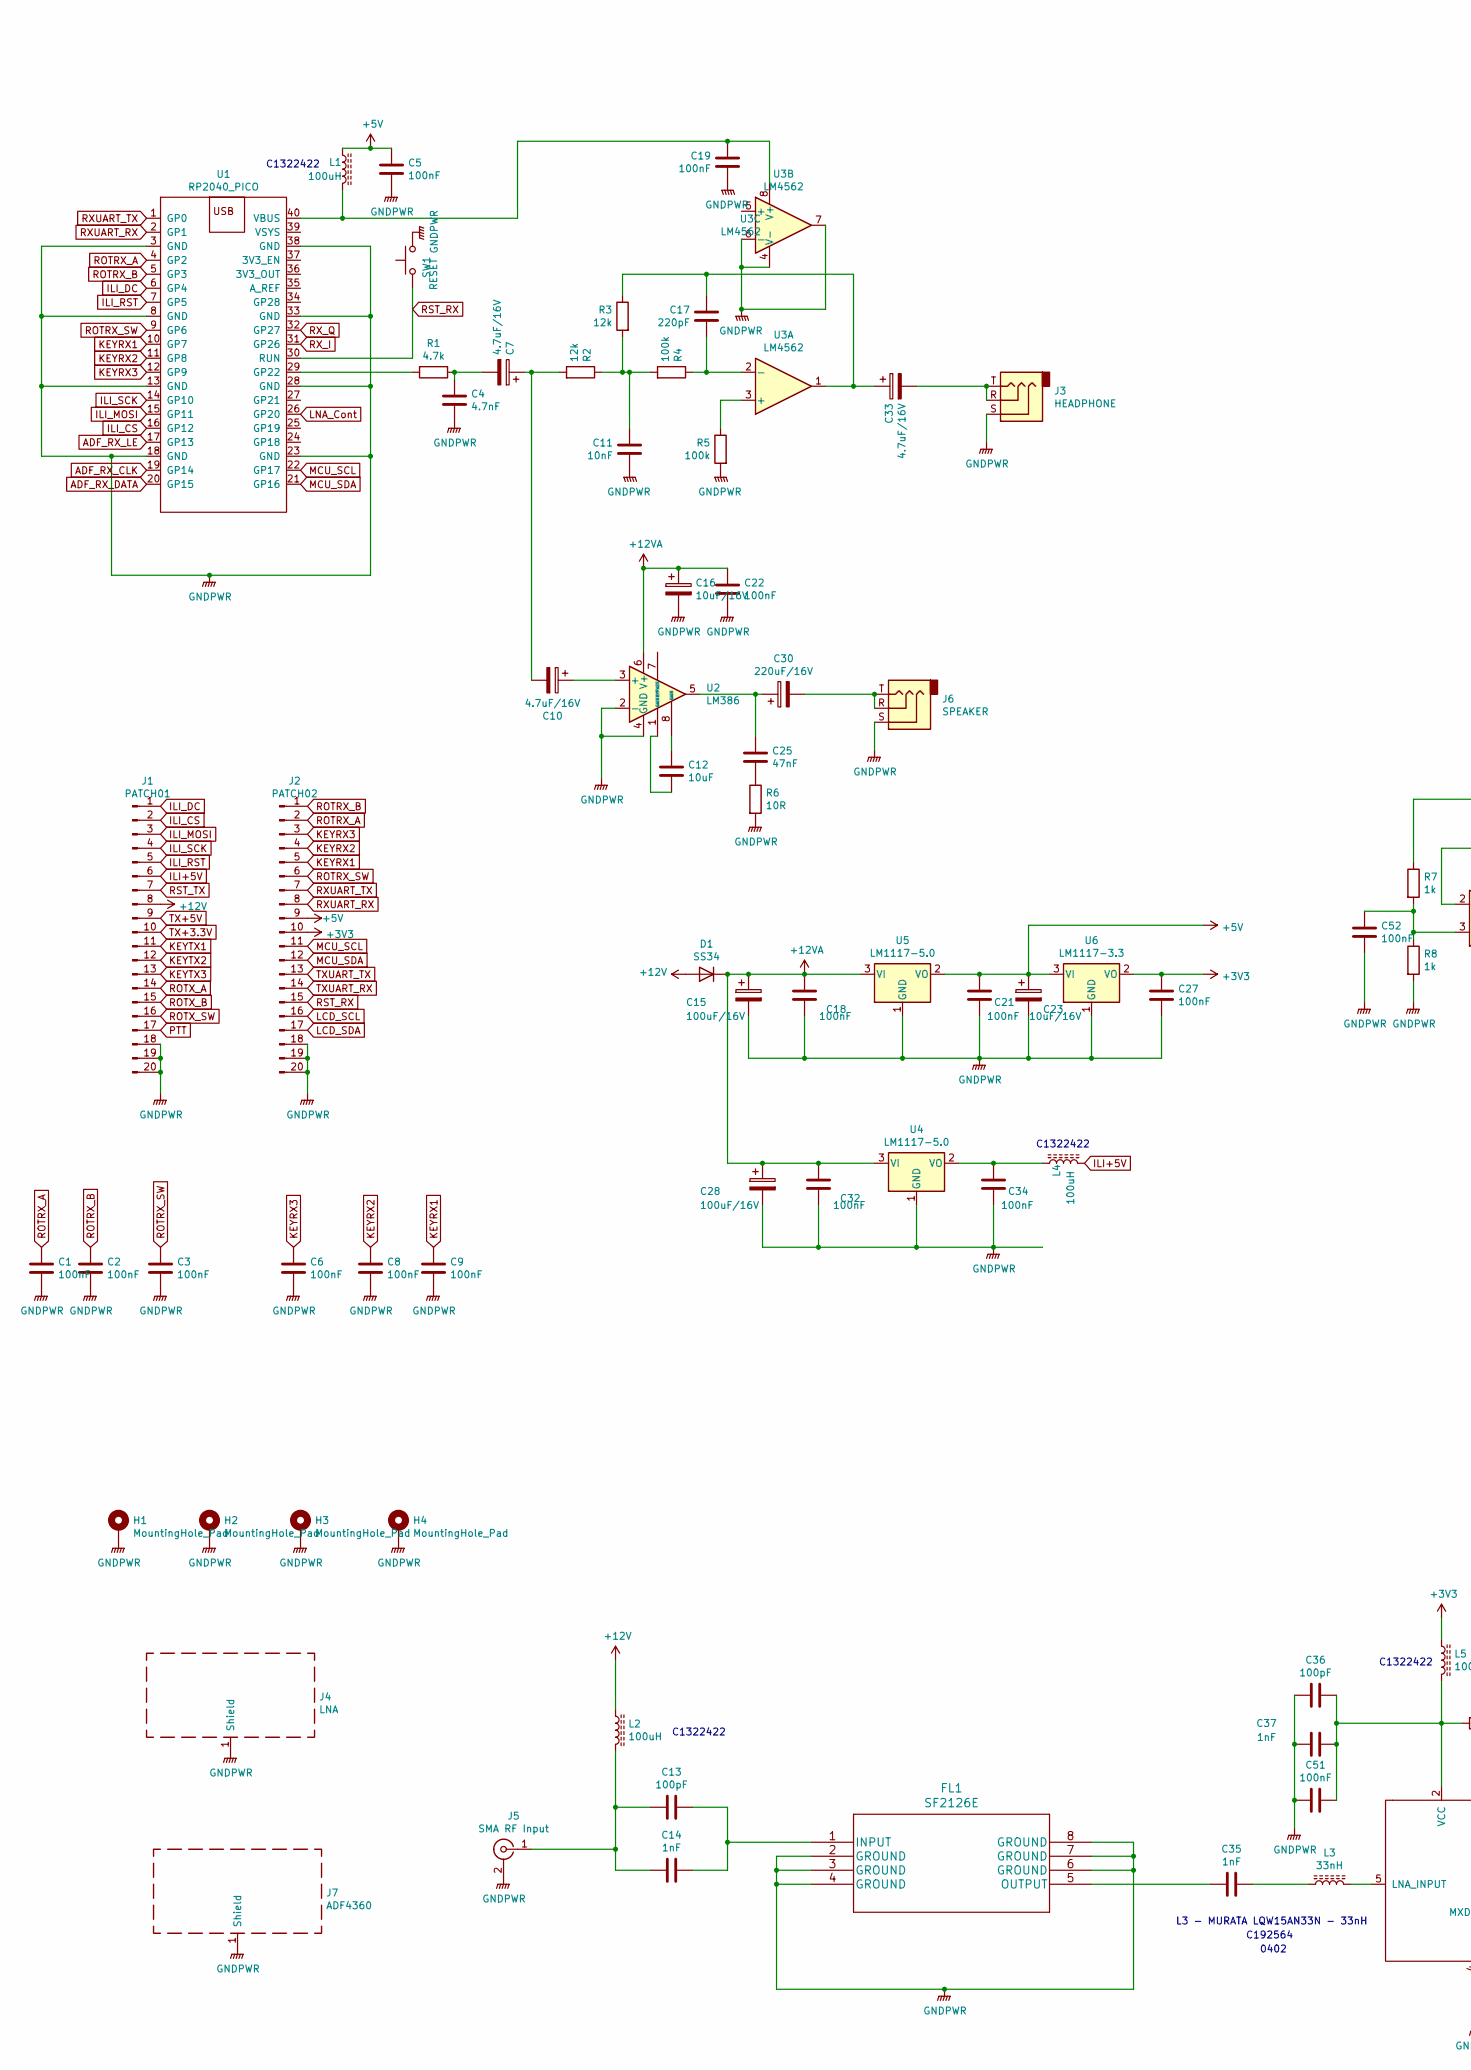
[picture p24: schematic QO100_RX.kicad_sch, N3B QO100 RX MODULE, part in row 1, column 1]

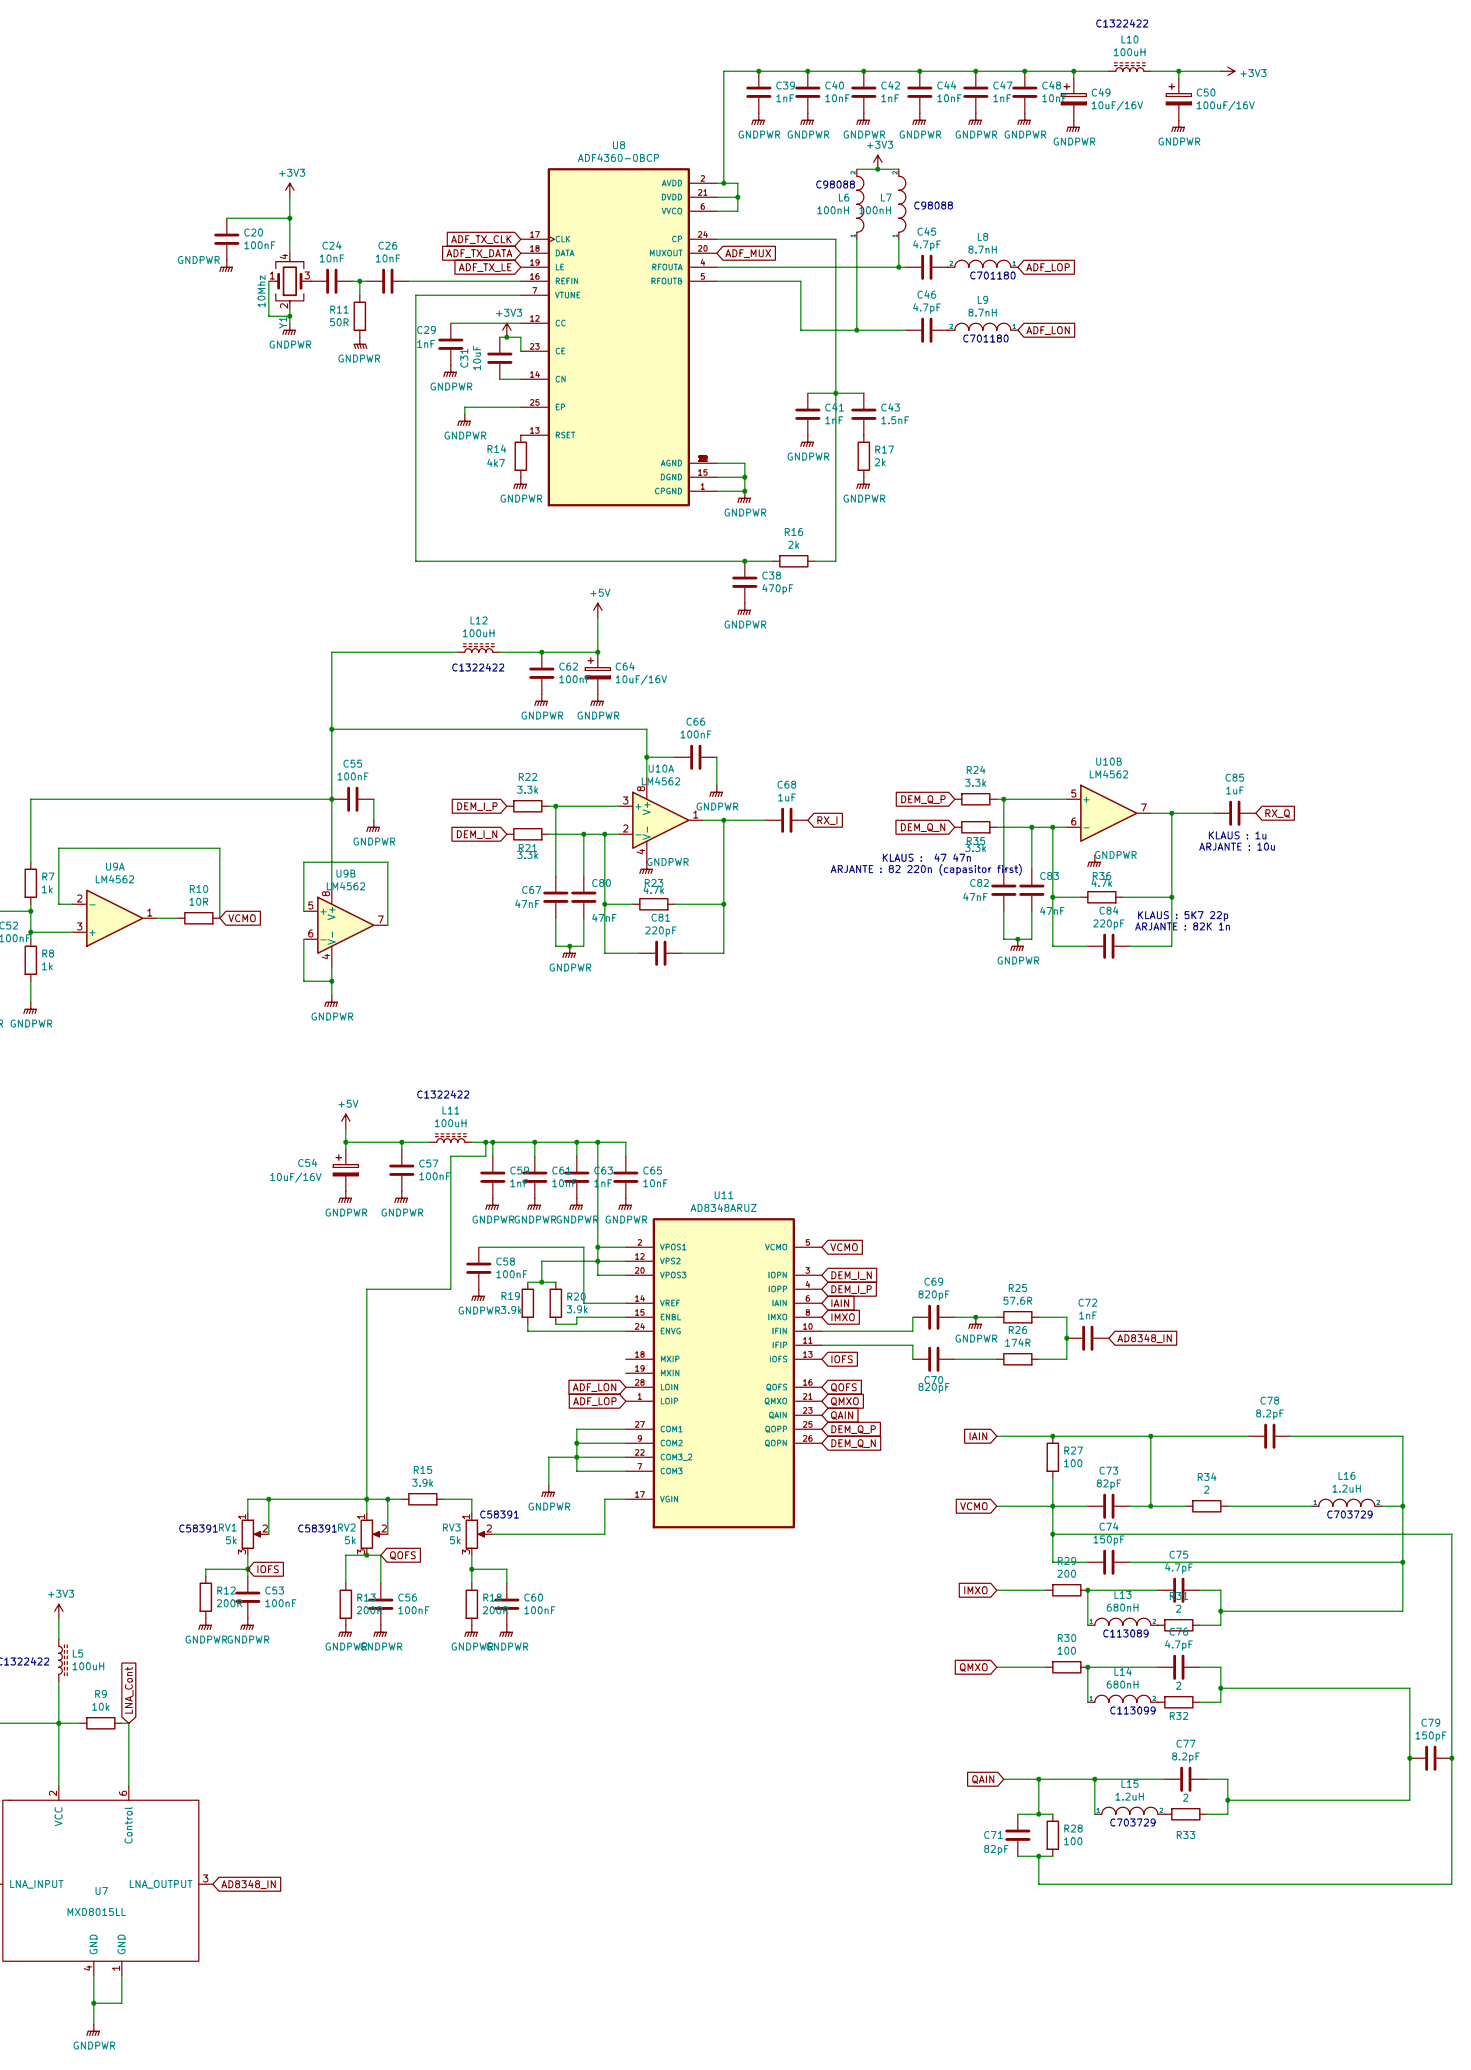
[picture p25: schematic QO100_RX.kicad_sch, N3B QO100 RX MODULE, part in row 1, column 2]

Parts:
C1, C2, C3, C5, C6, C8, C9, C18, C19, C20, C21, C22, C27, C32, C34, C51, C52, C53, C55, C56, C57, C58, C60, C62, C66: 100nF; C_0805_2012Metric
C4: 4.7nF; C_0805_2012Metric
C7, C10, C33: 4.7uF/16V; CP_Elec_4x5.4
C11, C24, C26, C40, C44, C48, C61, C65: 10nF; C_0805_2012Metric
C12, C31: 10uF; C_0805_2012Metric
C13, C36: 100pF; C_0805_2012Metric
C14, C29, C35, C37, C39, C41, C42, C47, C59, C63, C72: 1nF; C_0805_2012Metric
C15, C28, C50: 100uF/16V; CP_Elec_6.3x7.7
C16, C23, C49, C54, C64: 10uF/16V; CP_Elec_4x5.4
C17, C81, C84: 220pF; C_0805_2012Metric
C25, C67, C80, C82, C83: 47nF; C_0805_2012Metric
C30: 220uF/16V; CP_Elec_6.3x7.7
C38: 470pF; C_0805_2012Metric
C43: 1.5nF; C_0805_2012Metric
C45, C46, C75, C76: 4.7pF; C_0805_2012Metric
C68, C85: 1uF; C_0805_2012Metric
C69, C70: 820pF; C_0805_2012Metric
C71, C73: 82pF; C_0805_2012Metric
C74, C79: 150pF; C_0805_2012Metric
C77, C78: 8.2pF; C_0805_2012Metric
D1: SS34; D_SMA
FL1: SF2126E
H1, H2, H3, H4: MountingHole_Pad; MountingHole_3.2mm_M3_DIN965_Pad
J1: PATCH01; PinHeader_1x20_P2.54mm_Vertical
J2: PATCH02; PinHeader_1x20_P2.54mm_Vertical
J3: HEADPHONE; Jack_3.5mm_PJ-320B-SMT_Horizontal_CORR
J4: LNA; Laird_Technologies_BMI-S-102_16.50x16.50mm
J5: SMA RF Input; SMA_Samtec_SMA-J-P-X-ST-EM1_EdgeMount
J6: SPEAKER; Jack_3.5mm_PJ-320B-SMT_Horizontal_CORR
J7: ADF4360; Laird_Technologies_BMI-S-204-F_32.00x32.00mm
L1, L2, L4, L5, L10, L11, L12: 100uH; L_1210_3225Metric
L3: 33nH; L_0402_1005Metric
L6, L7: 100nH; L_0603_1608Metric
L8, L9: 8.7nH; L_0603_1608Metric
L13, L14: 680nH; L_0805_2012Metric
L15, L16: 1.2uH; L_0805_2012Metric
R1, R23, R36: 4.7k; R_0805_2012Metric
R2, R3: 12k; R_0805_2012Metric
R4, R5: 100k; R_0805_2012Metric
R6, R10: 10R; R_0805_2012Metric
R7, R8: 1k; R_0805_2012Metric
R9: 10k; R_0805_2012Metric
R11: 50R; R_0805_2012Metric
R12, R13, R18: 200R; R_0805_2012Metric
R14: 4k7; R_0805_2012Metric
R15, R19, R20: 3.9k; R_0805_2012Metric
R16, R17: 2k; R_0805_2012Metric
R21, R22, R24, R35: 3.3k; R_0805_2012Metric
R25: 57.6R; R_0805_2012Metric
R26: 174R; R_0805_2012Metric
R27, R28, R30: 100; R_0805_2012Metric
R29: 200; R_0805_2012Metric
R31, R32, R33, R34: 2; R_0805_2012Metric
RV1, RV2, RV3: 5k; Potentiometer_Bourns_3314J_Vertical
SW1: RESET; SW_Push_1P1T_NO_6x6mm_H9.5mm
U1: RP2040_PICO; RPI2040_PICO_SMD
U2: LM386; SO-8_3.9x4.9mm_P1.27mm
U3, U9, U10: LM4562; SO-8_3.9x4.9mm_P1.27mm
U4, U5: LM1117-5.0; SOT-223-3_TabPin2
U6: LM1117-3.3; SOT-223-3_TabPin2
U7: MXD8015LL; IC_BGC100GN6E6327XTSA1
U8: ADF4360-0BCP; ADF4360SEDA
U11: AD8348ARUZ; AD8348SEDA; MPN AD8348ARUZ
Y1: 10Mhz; Crystal_SMD_SeikoEpson_FA238V-4Pin_3.2x2.5mm

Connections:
+3V3: C20.1, C27.1, C31.1, C50.1, J2.10, L5.1, L6.2, L7.2, L10.2, U6.2 (VO), U8.23 (CE), Y1.4
+5V: C5.1, C21.1, C23.1, C54.1, C57.1, C62.1, C64.1, J2.9, L1.1, L11.1, L12.2, U5.2 (VO), U6.3 (VI)
+12V: D1.2 (A), J1.8, L2.1
+12VA: C15.1, C16.1, C18.1, C22.1, C28.1, C32.1, D1.1 (K), U2.6 (V+), U4.3 (VI), U5.3 (VI)
AD8348_IN: C72.2, U7.3 (LNA_OUTPUT)
ADF_LON: L9.1, U11.28 (LOIN)
ADF_LOP: L8.1, U11.1 (LOIP)
ADF_MUX: U8.20 (MUXOUT)
ADF_RX_CLK: U1.19 (GP14)
ADF_RX_DATA: U1.20 (GP15)
ADF_RX_LE: U1.17 (GP13)
ADF_TX_CLK: U8.17 (CLK)
ADF_TX_DATA: U8.18 (DATA)
ADF_TX_LE: U8.19 (LE)
DEM_I_N: R21.1, U11.3 (IOPN)
DEM_I_P: R22.2, U11.4 (IOPP)
DEM_Q_N: R35.1, U11.26 (QOPN)
DEM_Q_P: R24.2, U11.25 (QOPP)
GNDPWR: C1.2, C2.2, C3.2, C4.2, C5.2, C6.2, C8.2, C9.2, C11.2, C15.2, C16.2, C18.2, C19.2, C20.2, C21.2, C22.2, C23.2, C27.2, C28.2, C29.2, C32.2, C34.2, C36.2, C37.2, C38.2, C39.2, C40.2, C41.2, C42.2, C44.2, C47.2, C48.2, C49.2, C50.2, C51.2, C52.2, C53.2, C54.2, C55.2, C56.2, C57.2, C58.2, C59.2, C60.2, C61.2, C62.2, C63.2, C64.2, C65.2, C66.1, C67.2, C69.2, C80.2, C82.2, C83.2, FL1.2 (GROUND), FL1.3 (GROUND), FL1.4 (GROUND), FL1.6 (GROUND), FL1.7 (GROUND), FL1.8 (GROUND), H1.1, H2.1, H3.1, H4.1, J1.18, J1.19, J1.20, J2.18, J2.19, J2.20, J3.S, J4.1, J5.2 (Ext), J6.S, J7.1, R5.2, R6.2, R8.2, R11.2, R12.2, R13.2, R14.2, R17.2, R18.2, R25.1, SW1.2, U1.3 (GND), U1.8 (GND), U1.13 (GND), U1.18 (GND), U1.23 (GND), U1.28 (GND), U1.33 (GND), U1.38 (GND), U2.2 (-), U2.4 (GND), U3.4 (V-), U3.6 (-), U3.7, U4.1 (GND), U5.1 (GND), U6.1 (GND), U7.1 (GND), U7.4 (GND), U8.1 (CPGND), U8.3 (AGND), U8.8 (AGND), U8.9 (AGND), U8.10 (AGND), U8.11 (AGND), U8.15 (DGND), U8.22 (AGND), U8.25 (EP), U9.4 (V-), U9.6 (-), U10.4 (V-), U11.7 (COM3), U11.9 (COM2), U11.22 (COM3_2), U11.27 (COM1), Y1.1, Y1.2
IAIN: C73.1, C78.2, R27.1, R34.2, U11.6 (IAIN)
ILI+5V: J1.6, L4.2
ILI_CS: J1.2, U1.16 (GP12)
ILI_DC: J1.1, U1.6 (GP4)
ILI_MOSI: J1.3, U1.15 (GP11)
ILI_RST: J1.5, U1.7 (GP5)
ILI_SCK: J1.4, U1.14 (GP10)
IMXO: R29.2, U11.8 (IMXO)
IOFS: C53.1, R12.1, RV1.3, U11.13 (IOFS)
KEYRX1: C9.1, J2.5, U1.10 (GP7)
KEYRX2: C8.1, J2.4, U1.11 (GP8)
KEYRX3: C6.1, J2.3, U1.12 (GP9)
KEYTX1: J1.11
KEYTX2: J1.12
KEYTX3: J1.13
LCD_SCL: J2.16
LCD_SDA: J2.17
LNA_Cont: R9.1, U1.26 (GP20), U7.6 (Control)
MCU_SCL: J2.11, U1.22 (GP17)
MCU_SDA: J2.12, U1.21 (GP16)
unnamed: C4.1, C7.2, R1.1
unnamed: C10.1, U2.3 (+)
unnamed: C7.1, C10.2, R2.2
unnamed: C11.1, R2.1, R3.2, R4.2
unnamed: C12.1, U2.8 (GAIN)
unnamed: C12.2, U2.1 (GAIN)
unnamed: C13.1, C14.1, FL1.1 (INPUT)
unnamed: C13.2, C14.2, J5.1 (In), L2.2
unnamed: C17.1, C33.1, R3.1, U3.1
unnamed: C17.2, R4.1, U3.2 (-)
unnamed: C19.1, L1.2, U1.40 (VBUS), U3.8 (V+)
unnamed: C24.1, Y1.3
unnamed: C24.2, C26.1, R11.1
unnamed: C25.1, C30.1, U2.5
unnamed: C25.2, R6.1
unnamed: C26.2, U8.16 (REFIN)
unnamed: C29.1, U8.12 (CC)
unnamed: C30.2, J6.R, J6.T
unnamed: C31.2, U8.14 (CN)
unnamed: C33.2, J3.R, J3.T
unnamed: C34.1, L4.1, U4.2 (VO)
unnamed: C35.1, L3.1
unnamed: C35.2, FL1.5 (OUTPUT)
unnamed: C36.1, C37.1, C51.1, L5.2, R9.2, U7.2 (VCC)
unnamed: C38.1, R16.2, U8.7 (VTUNE)
unnamed: C39.1, C40.1, C42.1, C44.1, C47.1, C48.1, C49.1, L10.1, U8.2 (AVDD), U8.6 (VVCO), U8.21 (DVDD)
unnamed: C41.1, C43.1, R16.1, U8.24 (CP)
unnamed: C43.2, R17.1
unnamed: C45.1, L7.1, U8.4 (RFOUTA)
unnamed: C45.2, L8.2
unnamed: C46.1, L6.1, U8.5 (RFOUTB)
unnamed: C46.2, L9.2
unnamed: C52.1, R7.2, R8.1, U9.3 (+)
unnamed: C55.1, C66.2, L12.1, R7.1, U9.8 (V+), U10.8 (V+)
unnamed: C58.1, U11.14 (VREF)
unnamed: C59.1, C61.1, C63.1, C65.1, L11.2, R15.1, R19.1, R20.1, RV1.1, RV1.2, RV2.1, RV2.2, U11.2 (VPOS1), U11.12 (VPS2), U11.20 (VPOS3)
unnamed: C60.1, R18.1, RV3.3
unnamed: C67.1, R22.1, U10.3 (+)
unnamed: C68.2, C81.1, R23.2, U10.1
unnamed: C69.1, U11.10 (IFIN)
unnamed: C70.1, U11.11 (IFIP)
unnamed: C70.2, R26.1
unnamed: C72.1, R25.2, R26.2
unnamed: C74.1, C75.2, C78.1, L16.2, R31.1
unnamed: C75.1, L13.1, R29.1
unnamed: C76.1, L14.1, R30.1
unnamed: C76.2, C77.2, C79.1, R32.1, R33.1
unnamed: C80.1, C81.2, R21.2, R23.1, U10.2 (-)
unnamed: C82.1, R24.1, U10.5 (+)
unnamed: C83.1, C84.2, R35.2, R36.1, U10.6 (-)
unnamed: C84.1, C85.2, R36.2, U10.7
unnamed: L3.2, U7.5 (LNA_INPUT)
unnamed: L13.2, R31.2
unnamed: L14.2, R32.2
unnamed: L15.2, R33.2
unnamed: L16.1, R34.1
unnamed: R1.2, U1.29 (GP22)
unnamed: R5.1, U3.3 (+)
unnamed: R10.1, U9.1
unnamed: R14.1, U8.13 (RSET)
unnamed: R15.2, RV3.1
unnamed: R19.2, U11.24 (ENVG)
unnamed: R20.2, U11.15 (ENBL)
unnamed: RV3.2, U11.17 (VGIN)
unnamed: U9.5 (+), U9.7
PTT: J1.17
QAIN: C71.1, C77.1, L15.1, R28.1, U11.23 (QAIN)
QMXO: R30.2, U11.21 (QMXO)
QOFS: C56.1, R13.1, RV2.3, U11.16 (QOFS)
ROTRX_A: C1.1, J2.2, U1.4 (GP2)
ROTRX_B: C2.1, J2.1, U1.5 (GP3)
ROTRX_SW: C3.1, J2.6, U1.9 (GP6)
ROTX_A: J1.14
ROTX_B: J1.15
ROTX_SW: J1.16
RST_RX: J2.15, SW1.1, U1.30 (RUN)
RST_TX: J1.7
RXUART_RX: J2.8, U1.2 (GP1)
RXUART_TX: J2.7, U1.1 (GP0)
RX_I: C68.1, U1.31 (GP26)
RX_Q: C85.1, U1.32 (GP27)
TX+3.3V: J1.10
TX+5V: J1.9
TXUART_RX: J2.14
TXUART_TX: J2.13
VCMO: C71.2, C73.2, C74.2, C79.2, R10.2, R27.2, R28.2, U9.2 (-), U11.5 (VCMO)

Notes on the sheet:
C1322422
C701180
L3 - MURATA LQW15AN33N - 33nH
C113099
C58391
KLAUS : 1u ARJANTE : 10u
C192564
C98088
C703729
C113089
KLAUS : 5K7 22p ARJANTE : 82K 1n
KLAUS : 47 47n ARJANTE : 82 220n (capasitor first)
0402

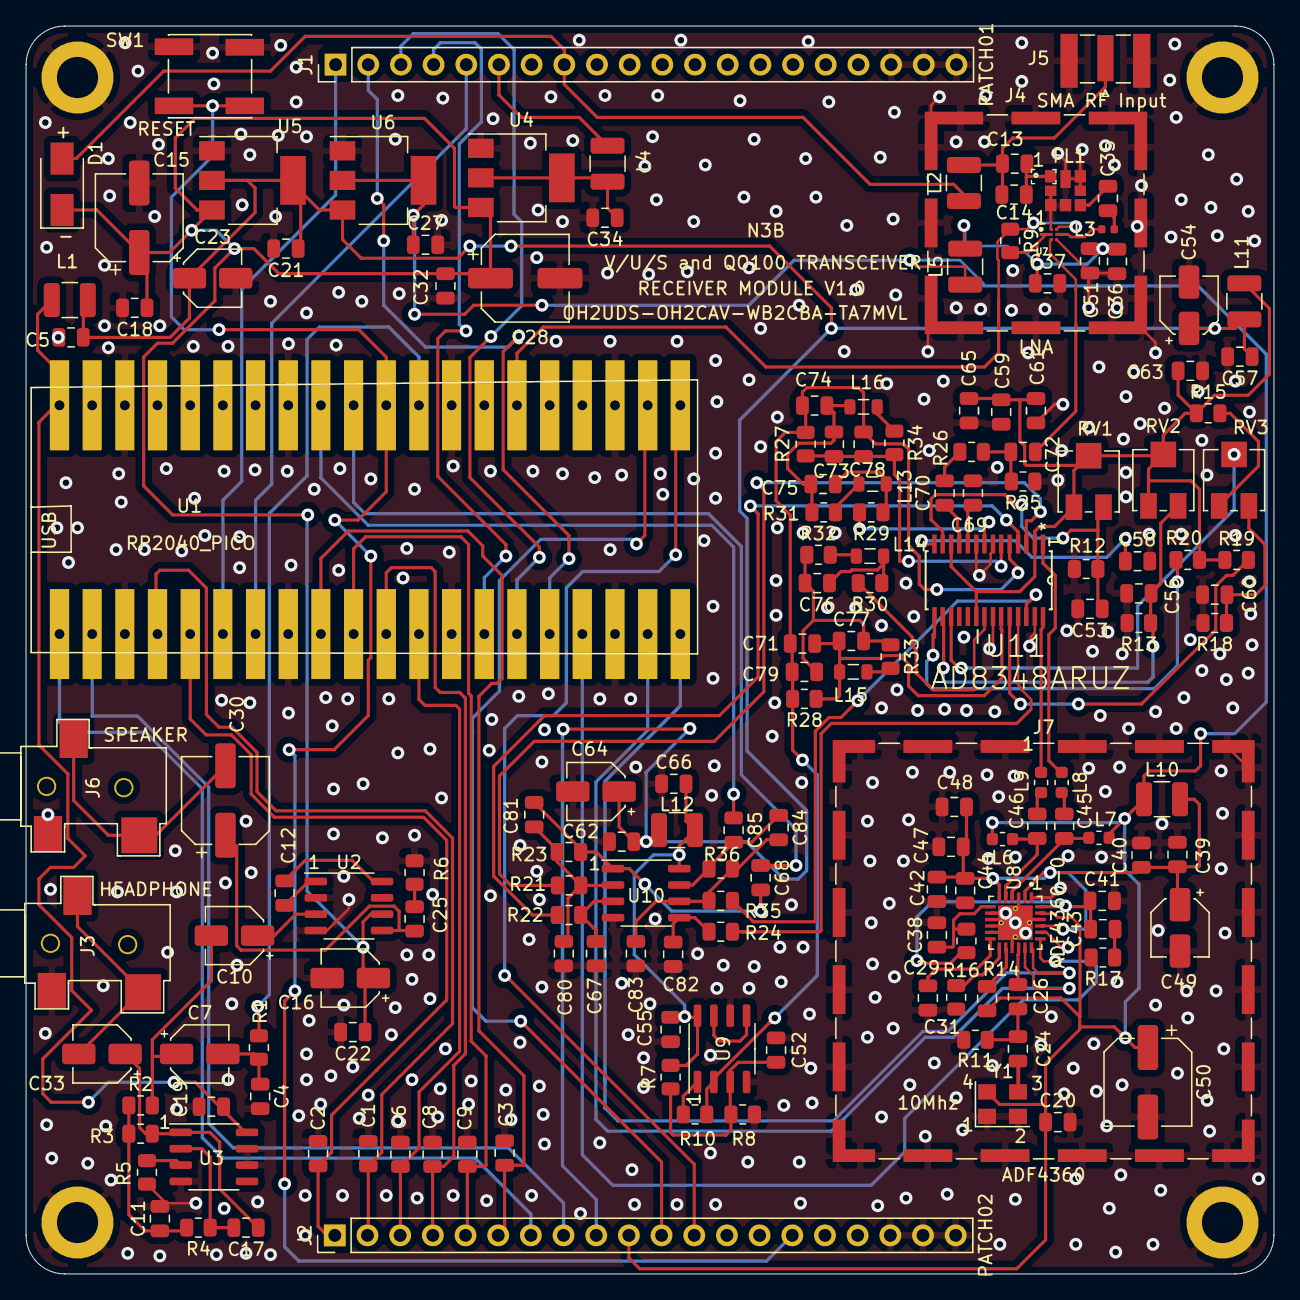
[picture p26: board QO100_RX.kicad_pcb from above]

Board: 2 copper layers, 97.0 x 97.0 mm, 166 parts (0 on the bottom side), 104 nets.

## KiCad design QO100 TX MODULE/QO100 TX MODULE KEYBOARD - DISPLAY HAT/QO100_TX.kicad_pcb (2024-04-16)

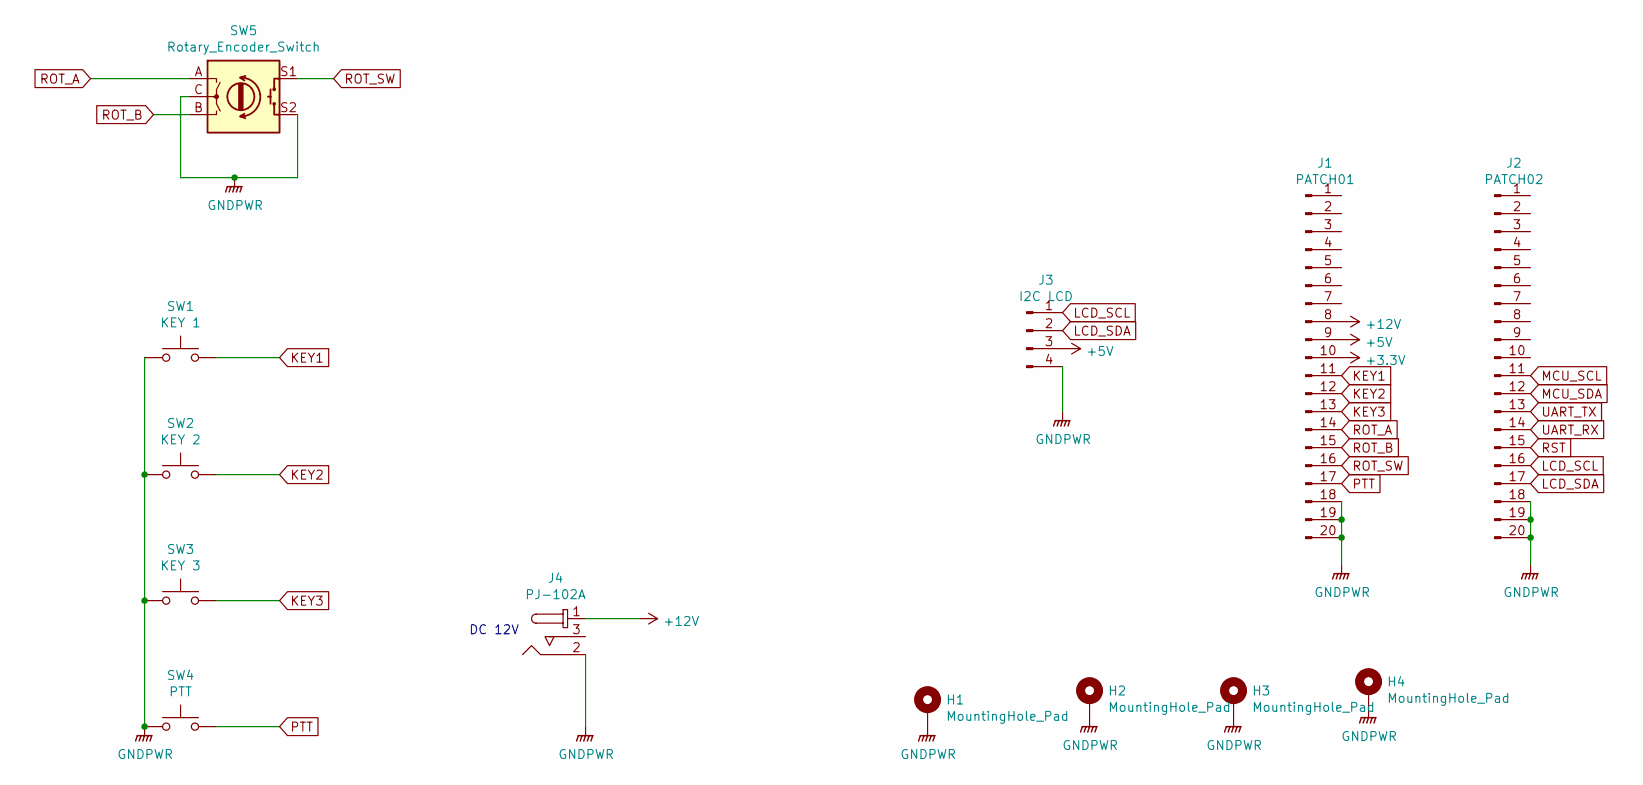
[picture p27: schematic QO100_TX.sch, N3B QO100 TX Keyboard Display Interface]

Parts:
H1, H2, H3, H4: MountingHole_Pad; MountingHole_3.2mm_M3_DIN965_Pad
J1: PATCH01; PinHeader_1x20_P2.54mm_Vertical
J2: PATCH02; PinHeader_1x20_P2.54mm_Vertical
J3: I2C LCD; PinHeader_1x04_P2.54mm_Vertical
J4: PJ-102A; Barrel_Jack_5.5mmODx2.1mmID_PJ-102A; MPN PJ-102A; Digi-Key_PN CP-102A-ND
SW1: KEY 1; SW_PUSH_6mm
SW2: KEY 2; SW_PUSH_6mm
SW3: KEY 3; SW_PUSH_6mm
SW4: PTT; SW_PUSH_6mm
SW5: Rotary_Encoder_Switch; RotaryEncoder_Alps_EC11E-Switch_Vertical_H20mm

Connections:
+3V3: J1.10
+5V: J1.9, J3.3
+12V: J1.8, J4.1
GNDPWR: H1.1, H2.1, H3.1, H4.1, J1.18, J1.19, J1.20, J2.18, J2.19, J2.20, J3.4, J4.2, SW1.1, SW2.1, SW3.1, SW4.1, SW5.C, SW5.S2
KEY1: J1.11, SW1.2
KEY2: J1.12, SW2.2
KEY3: J1.13, SW3.2
LCD_SCL: J2.16, J3.1
LCD_SDA: J2.17, J3.2
MCU_SCL: J2.11
MCU_SDA: J2.12
PTT: J1.17, SW4.2
ROT_A: J1.14, SW5.A
ROT_B: J1.15, SW5.B
ROT_SW: J1.16, SW5.S1
RST: J2.15
UART_RX: J2.14
UART_TX: J2.13

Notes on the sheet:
DC 12V

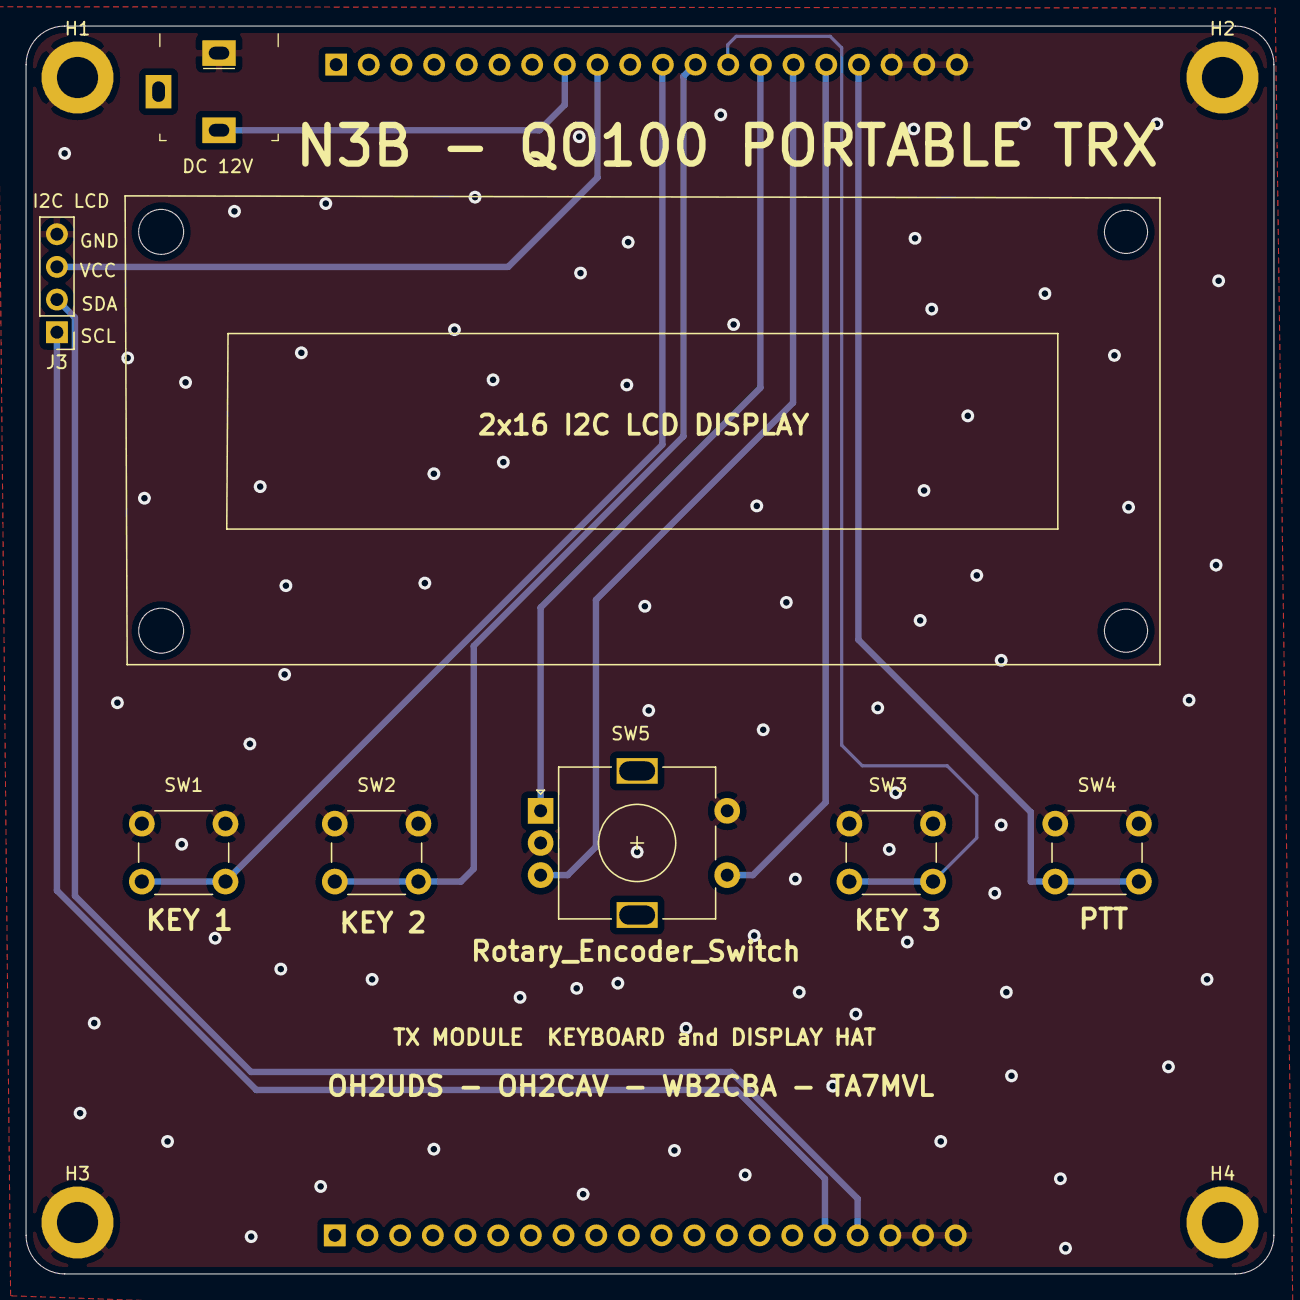
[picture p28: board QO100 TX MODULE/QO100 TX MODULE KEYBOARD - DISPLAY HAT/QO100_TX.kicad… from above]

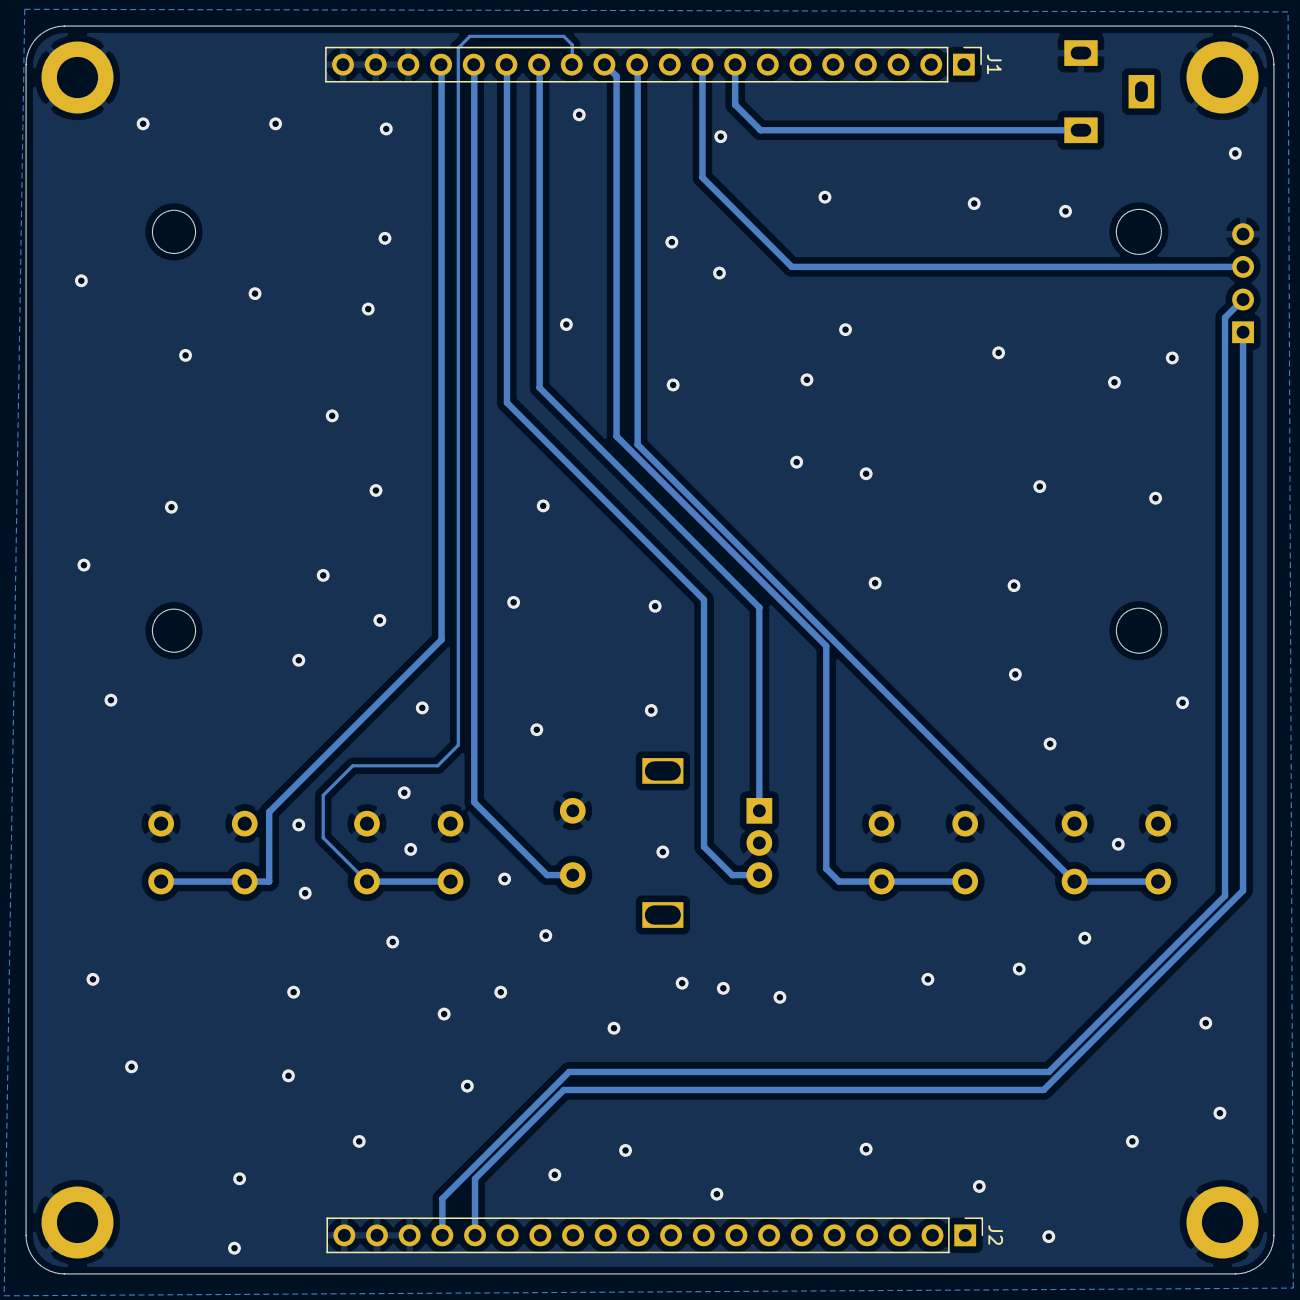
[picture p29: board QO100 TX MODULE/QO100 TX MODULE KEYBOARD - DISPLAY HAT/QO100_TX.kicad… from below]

Board: 2 copper layers, 97.0 x 97.0 mm, 13 parts (2 on the bottom side), 12 nets.

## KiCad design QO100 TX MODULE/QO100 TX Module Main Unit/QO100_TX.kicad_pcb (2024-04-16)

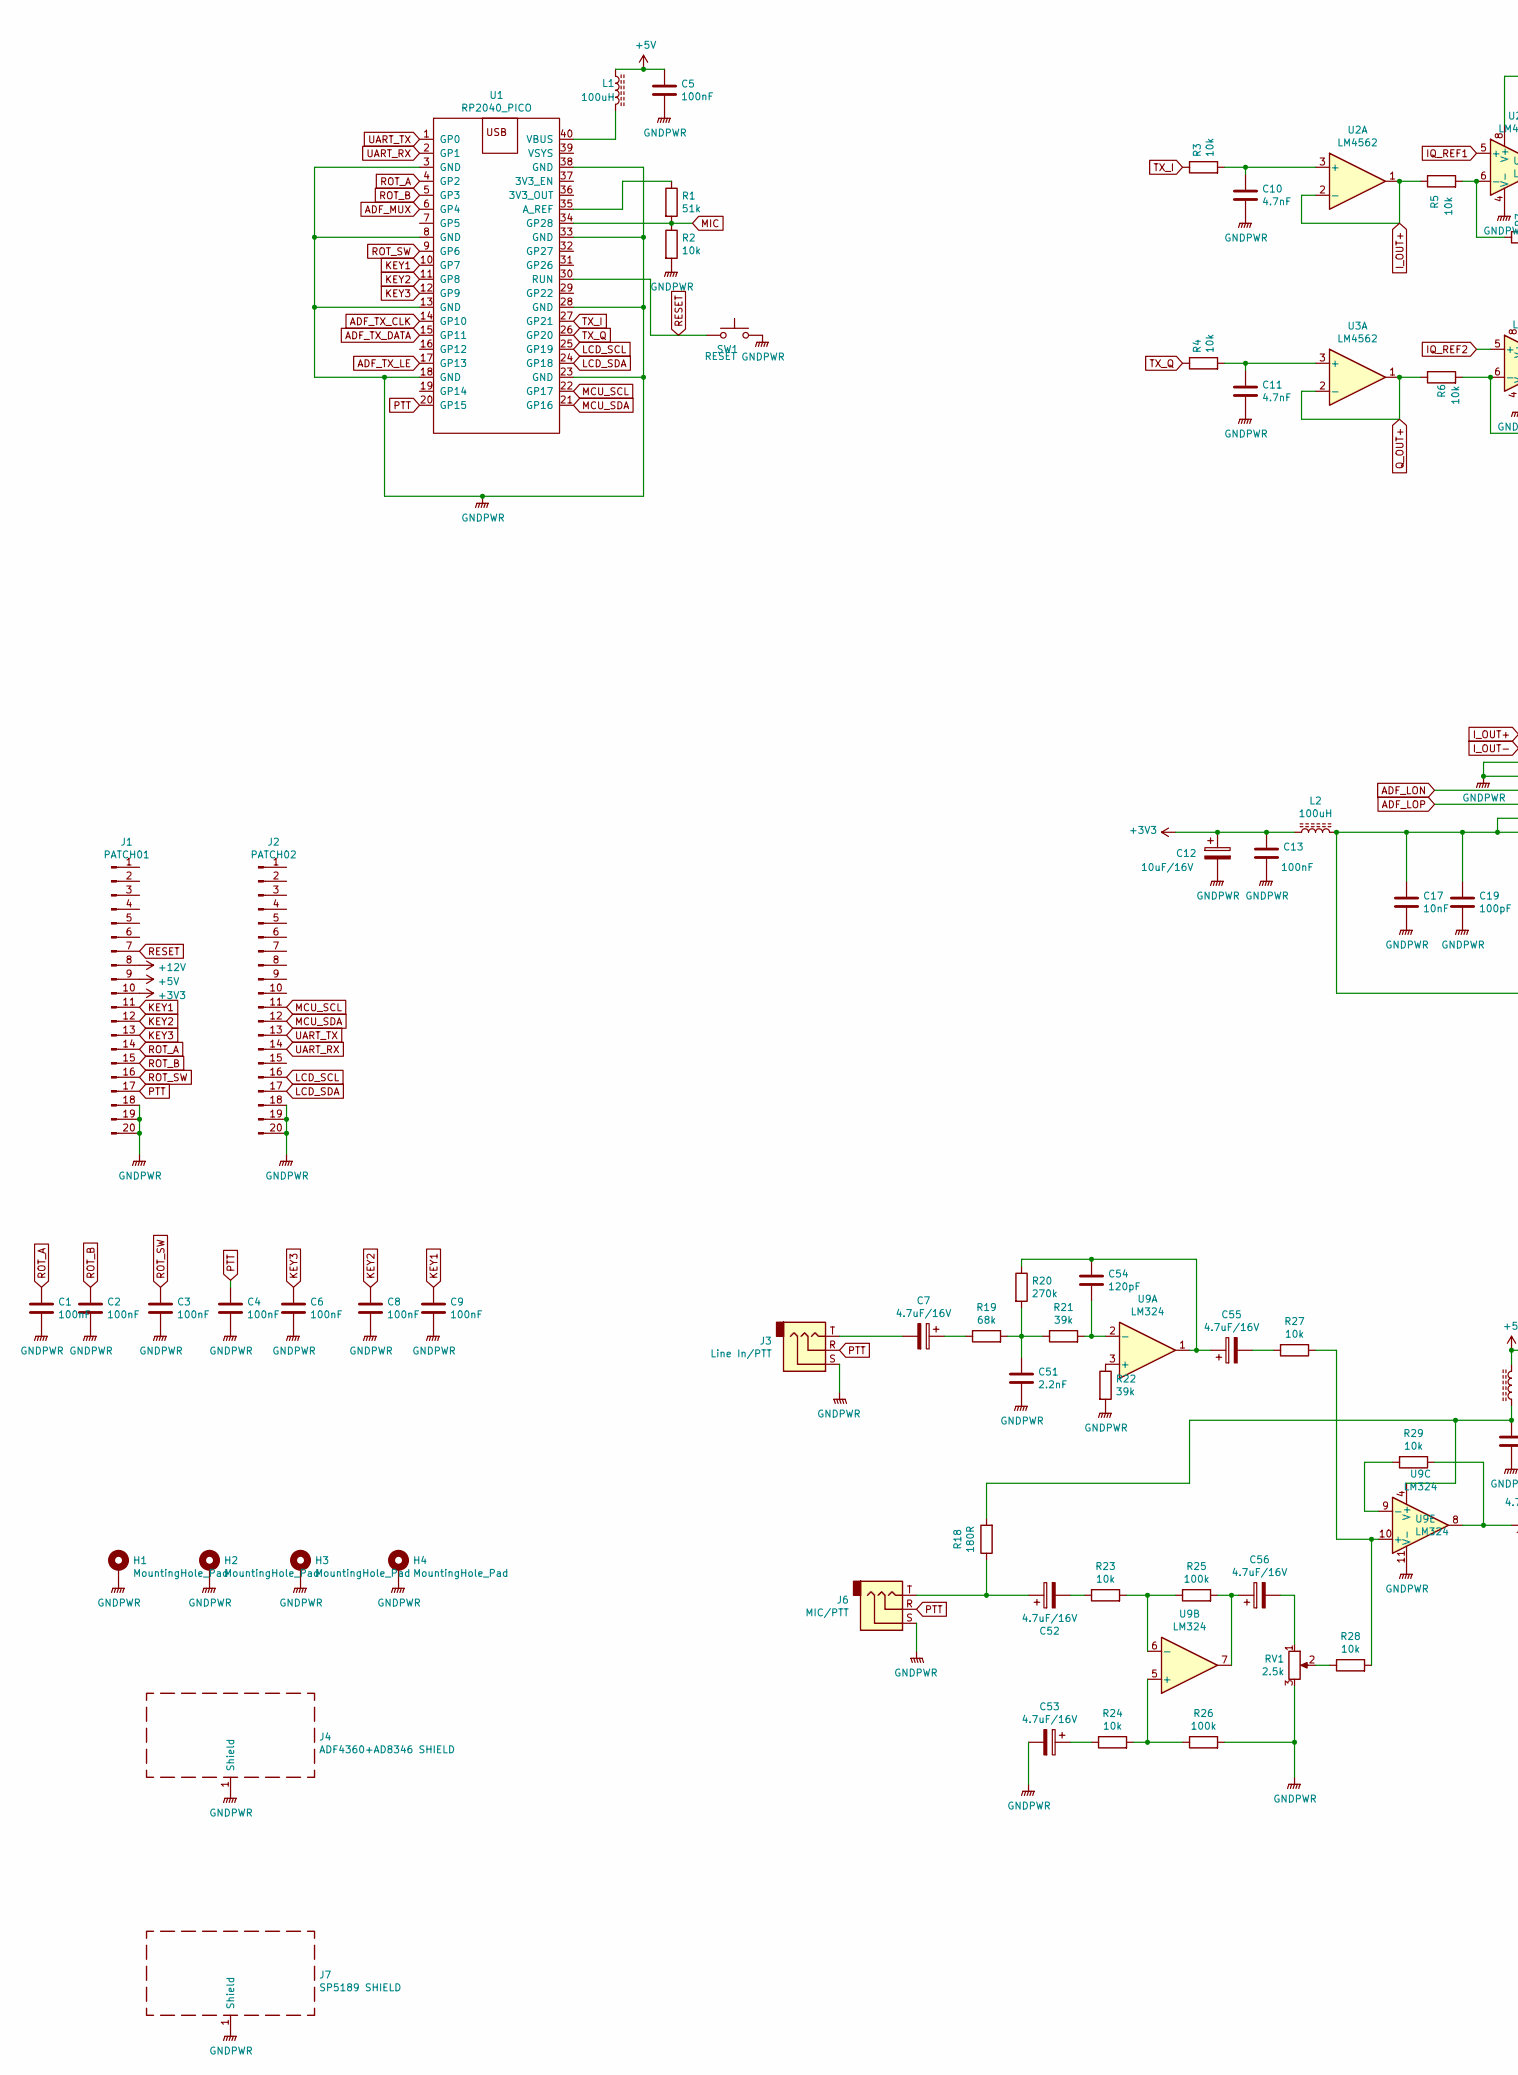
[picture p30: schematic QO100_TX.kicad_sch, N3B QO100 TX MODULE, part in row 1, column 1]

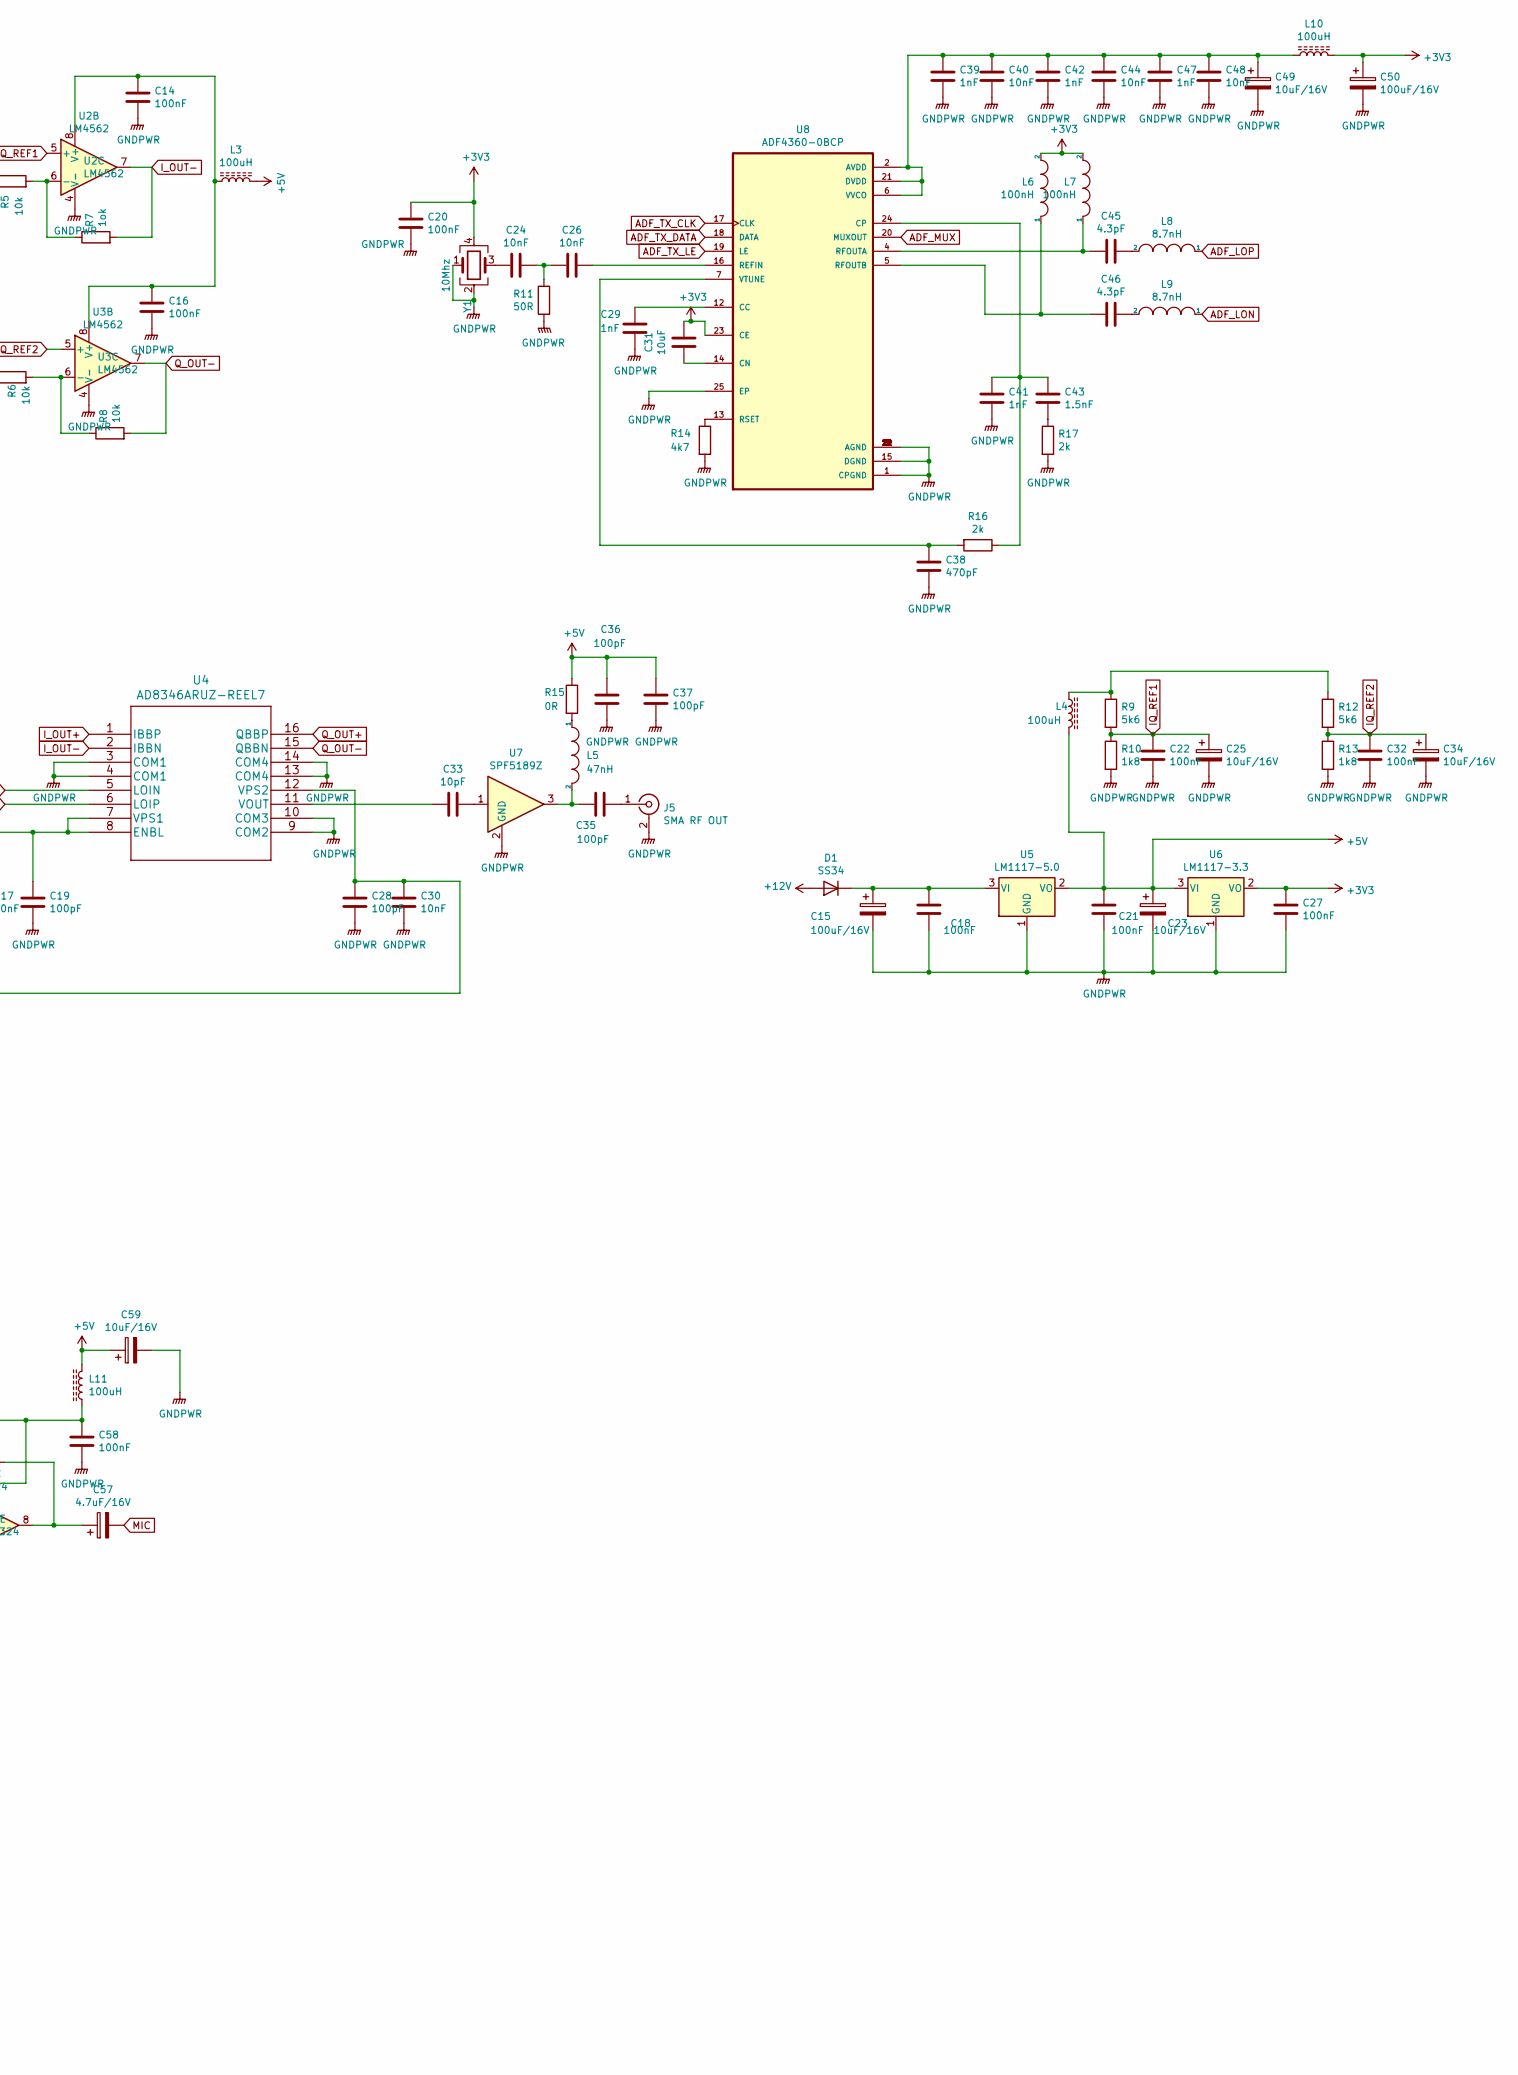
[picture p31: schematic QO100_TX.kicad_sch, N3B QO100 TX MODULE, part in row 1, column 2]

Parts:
C1, C2, C3, C4, C5, C6, C8, C9, C13, C14, C16, C18, C20, C21, C22, C27, C32, C58: 100nF; C_0805_2012Metric
C7, C52, C53, C55, C56, C57: 4.7uF/16V; CP_Elec_4x5.4
C10, C11: 4.7nF; C_0805_2012Metric
C12, C23, C25, C34, C49, C59: 10uF/16V; CP_Elec_4x5.4
C15, C50: 100uF/16V; CP_Elec_6.3x7.7
C17, C24, C26, C30, C40, C44, C48: 10nF; C_0805_2012Metric
C19, C28, C35, C36, C37: 100pF; C_0805_2012Metric
C29, C39, C41, C42, C47: 1nF; C_0805_2012Metric
C31: 10uF; C_0805_2012Metric
C33: 10pF; C_0805_2012Metric
C38: 470pF; C_0805_2012Metric
C43: 1.5nF; C_0805_2012Metric
C45, C46: 4.3pF; C_0805_2012Metric
C51: 2.2nF; C_0805_2012Metric
C54: 120pF; C_0805_2012Metric
D1: SS34; D_SMA
H1, H2, H3, H4: MountingHole_Pad; MountingHole_3.2mm_M3_DIN965_Pad
J1: PATCH01; PinHeader_1x20_P2.54mm_Vertical
J2: PATCH02; PinHeader_1x20_P2.54mm_Vertical
J3: Line In/PTT; Jack_3.5mm_PJ-320B-SMT_Horizontal_CORR
J4: ADF4360+AD8346 SHIELD; Laird_Technologies_BMI-S-210-F_44.00x30.50mm
J5: SMA RF OUT; SMA_Samtec_SMA-J-P-X-ST-EM1_EdgeMount
J6: MIC/PTT; Jack_3.5mm_PJ-320B-SMT_Horizontal_CORR
J7: SP5189 SHIELD; Wuerth_36103205_20x20mm
L1, L2, L3, L4, L10, L11: 100uH; L_1210_3225Metric
L5: 47nH; L_0805_2012Metric
L6, L7: 100nH; L_0603_1608Metric
L8, L9: 8.7nH; L_0603_1608Metric
R1: 51k; R_0805_2012Metric
R2, R3, R4, R5, R6, R8, R23, R24, R27, R28, R29: 10k; R_0805_2012Metric
R7: 1ok; R_0805_2012Metric
R9, R12: 5k6; R_0805_2012Metric
R10, R13: 1k8; R_0805_2012Metric
R11: 50R; R_0805_2012Metric
R14: 4k7; R_0805_2012Metric
R15: 0R; R_0805_2012Metric
R16, R17: 2k; R_0805_2012Metric
R18: 180R; R_0805_2012Metric
R19: 68k; R_0805_2012Metric
R20: 270k; R_0805_2012Metric
R21, R22: 39k; R_0805_2012Metric
R25, R26: 100k; R_0805_2012Metric
RV1: 2.5k; Potentiometer_Piher_PT-10-V10_Vertical
SW1: RESET; SW_Push_1P1T_NO_6x6mm_H9.5mm
U1: RP2040_PICO; RPI2040_PICO_SMD
U2, U3: LM4562; SOIC-8_3.9x4.9mm_P1.27mm
U4: AD8346ARUZ-REEL7; AD8346SEDA
U5: LM1117-5.0; SOT-223-3_TabPin2
U6: LM1117-3.3; SOT-223-3_TabPin2
U7: SPF5189Z; SOT-89-3
U8: ADF4360-0BCP; ADF4360SEDA
U9: LM324; SOIC-14_3.9x8.7mm_P1.27mm
Y1: 10Mhz; Crystal_SMD_SeikoEpson_FA238V-4Pin_3.2x2.5mm

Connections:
+3V3: C12.1, C13.1, C20.1, C27.1, C31.1, C50.1, J1.10, L2.1, L6.2, L7.2, L10.2, U6.2 (VO), U8.23 (CE), Y1.4
+5V: C5.1, C21.1, C23.1, C36.1, C37.1, C59.1, J1.9, L1.1, L3.2, L4.2, L11.2, R15.1, U5.2 (VO), U6.3 (VI)
+12V: D1.2 (A), J1.8
ADF_LON: L9.1, U4.5 (LOIN)
ADF_LOP: L8.1, U4.6 (LOIP)
ADF_MUX: U1.6 (GP4), U8.20 (MUXOUT)
ADF_TX_CLK: U1.14 (GP10), U8.17 (CLK)
ADF_TX_DATA: U1.15 (GP11), U8.18 (DATA)
ADF_TX_LE: U1.17 (GP13), U8.19 (LE)
GNDPWR: C1.2, C2.2, C3.2, C4.2, C5.2, C6.2, C8.2, C9.2, C10.2, C11.2, C12.2, C13.2, C14.2, C15.2, C16.2, C17.2, C18.2, C19.2, C20.2, C21.2, C22.2, C23.2, C25.2, C27.2, C28.2, C29.2, C30.2, C32.2, C34.2, C36.2, C37.2, C38.2, C39.2, C40.2, C41.2, C42.2, C44.2, C47.2, C48.2, C49.2, C50.2, C51.2, C53.2, C58.2, C59.2, H1.1, H2.1, H3.1, H4.1, J1.18, J1.19, J1.20, J2.18, J2.19, J2.20, J3.S, J4.1, J5.2 (Ext), J6.S, J7.1, R2.2, R10.2, R11.2, R13.2, R14.2, R17.2, R22.2, R26.2, RV1.3, SW1.2, U1.3 (GND), U1.8 (GND), U1.13 (GND), U1.18 (GND), U1.23 (GND), U1.28 (GND), U1.33 (GND), U1.38 (GND), U2.4 (V-), U3.4 (V-), U4.3 (COM1), U4.4 (COM1), U4.9 (COM2), U4.10 (COM3), U4.13 (COM4), U4.14 (COM4), U5.1 (GND), U6.1 (GND), U7.2 (GND), U8.1 (CPGND), U8.3 (AGND), U8.8 (AGND), U8.9 (AGND), U8.10 (AGND), U8.11 (AGND), U8.15 (DGND), U8.22 (AGND), U8.25 (EP), U9.11 (V-), Y1.1, Y1.2
IQ_REF1: C22.1, C25.1, R9.2, R10.1, U2.5 (+)
IQ_REF2: C32.1, C34.1, R12.2, R13.1, U3.5 (+)
I_OUT+: R5.1, U2.1, U2.2 (-), U4.1 (IBBP)
I_OUT-: R7.2, U2.7, U4.2 (IBBN)
KEY1: C9.1, J1.11, U1.10 (GP7)
KEY2: C8.1, J1.12, U1.11 (GP8)
KEY3: C6.1, J1.13, U1.12 (GP9)
LCD_SCL: J2.16, U1.25 (GP19)
LCD_SDA: J2.17, U1.24 (GP18)
MCU_SCL: J2.11, U1.22 (GP17)
MCU_SDA: J2.12, U1.21 (GP16)
MIC: C57.2, R1.2, R2.1, U1.34 (GP28)
unnamed: C7.1, R19.1
unnamed: C7.2, J3.T
unnamed: C10.1, R3.2, U2.3 (+)
unnamed: C11.1, R4.2, U3.3 (+)
unnamed: C14.1, C16.1, L3.1, U2.8 (V+), U3.8 (V+)
unnamed: C15.1, C18.1, D1.1 (K), U5.3 (VI)
unnamed: C17.1, C19.1, C28.1, C30.1, L2.2, U4.7 (VPS1), U4.8 (ENBL), U4.12 (VPS2)
unnamed: C24.1, Y1.3
unnamed: C24.2, C26.1, R11.1
unnamed: C26.2, U8.16 (REFIN)
unnamed: C29.1, U8.12 (CC)
unnamed: C31.2, U8.14 (CN)
unnamed: C33.1, U7.1
unnamed: C33.2, U4.11 (VOUT)
unnamed: C35.1, J5.1 (In)
unnamed: C35.2, L5.2, U7.3
unnamed: C38.1, R16.2, U8.7 (VTUNE)
unnamed: C39.1, C40.1, C42.1, C44.1, C47.1, C48.1, C49.1, L10.1, U8.2 (AVDD), U8.6 (VVCO), U8.21 (DVDD)
unnamed: C41.1, C43.1, R16.1, U8.24 (CP)
unnamed: C43.2, R17.1
unnamed: C45.1, L7.1, U8.4 (RFOUTA)
unnamed: C45.2, L8.2
unnamed: C46.1, L6.1, U8.5 (RFOUTB)
unnamed: C46.2, L9.2
unnamed: C51.1, R19.2, R20.2, R21.1
unnamed: C52.1, J6.T, R18.1
unnamed: C52.2, R23.1
unnamed: C53.1, R24.1
unnamed: C54.1, C55.1, R20.1, U9.1
unnamed: C54.2, R21.2, U9.2 (-)
unnamed: C55.2, R27.2
unnamed: C56.1, R25.2, U9.7
unnamed: C56.2, RV1.1
unnamed: C57.1, R29.1, U9.8
unnamed: C58.1, L11.1, R18.2, U9.4 (V+)
unnamed: L1.2, U1.40 (VBUS)
unnamed: L4.1, R9.1, R12.1
unnamed: L5.1, R15.2
unnamed: R1.1, U1.35 (A_REF)
unnamed: R5.2, R7.1, U2.6 (-)
unnamed: R6.2, R8.1, U3.6 (-)
unnamed: R14.1, U8.13 (RSET)
unnamed: R22.1, U9.3 (+)
unnamed: R23.2, R25.1, U9.6 (-)
unnamed: R24.2, R26.1, U9.5 (+)
unnamed: R27.1, R28.2, U9.10 (+)
unnamed: R28.1, RV1.2
unnamed: R29.2, U9.9 (-)
PTT: C4.1, J1.17, J3.R, J6.R, U1.20 (GP15)
Q_OUT+: R6.1, U3.1, U3.2 (-), U4.16 (QBBP)
Q_OUT-: R8.2, U3.7, U4.15 (QBBN)
RESET: J1.7, SW1.1, U1.30 (RUN)
ROT_A: C1.1, J1.14, U1.4 (GP2)
ROT_B: C2.1, J1.15, U1.5 (GP3)
ROT_SW: C3.1, J1.16, U1.9 (GP6)
TX_I: R3.1, U1.27 (GP21)
TX_Q: R4.1, U1.26 (GP20)
UART_RX: J2.14, U1.2 (GP1)
UART_TX: J2.13, U1.1 (GP0)

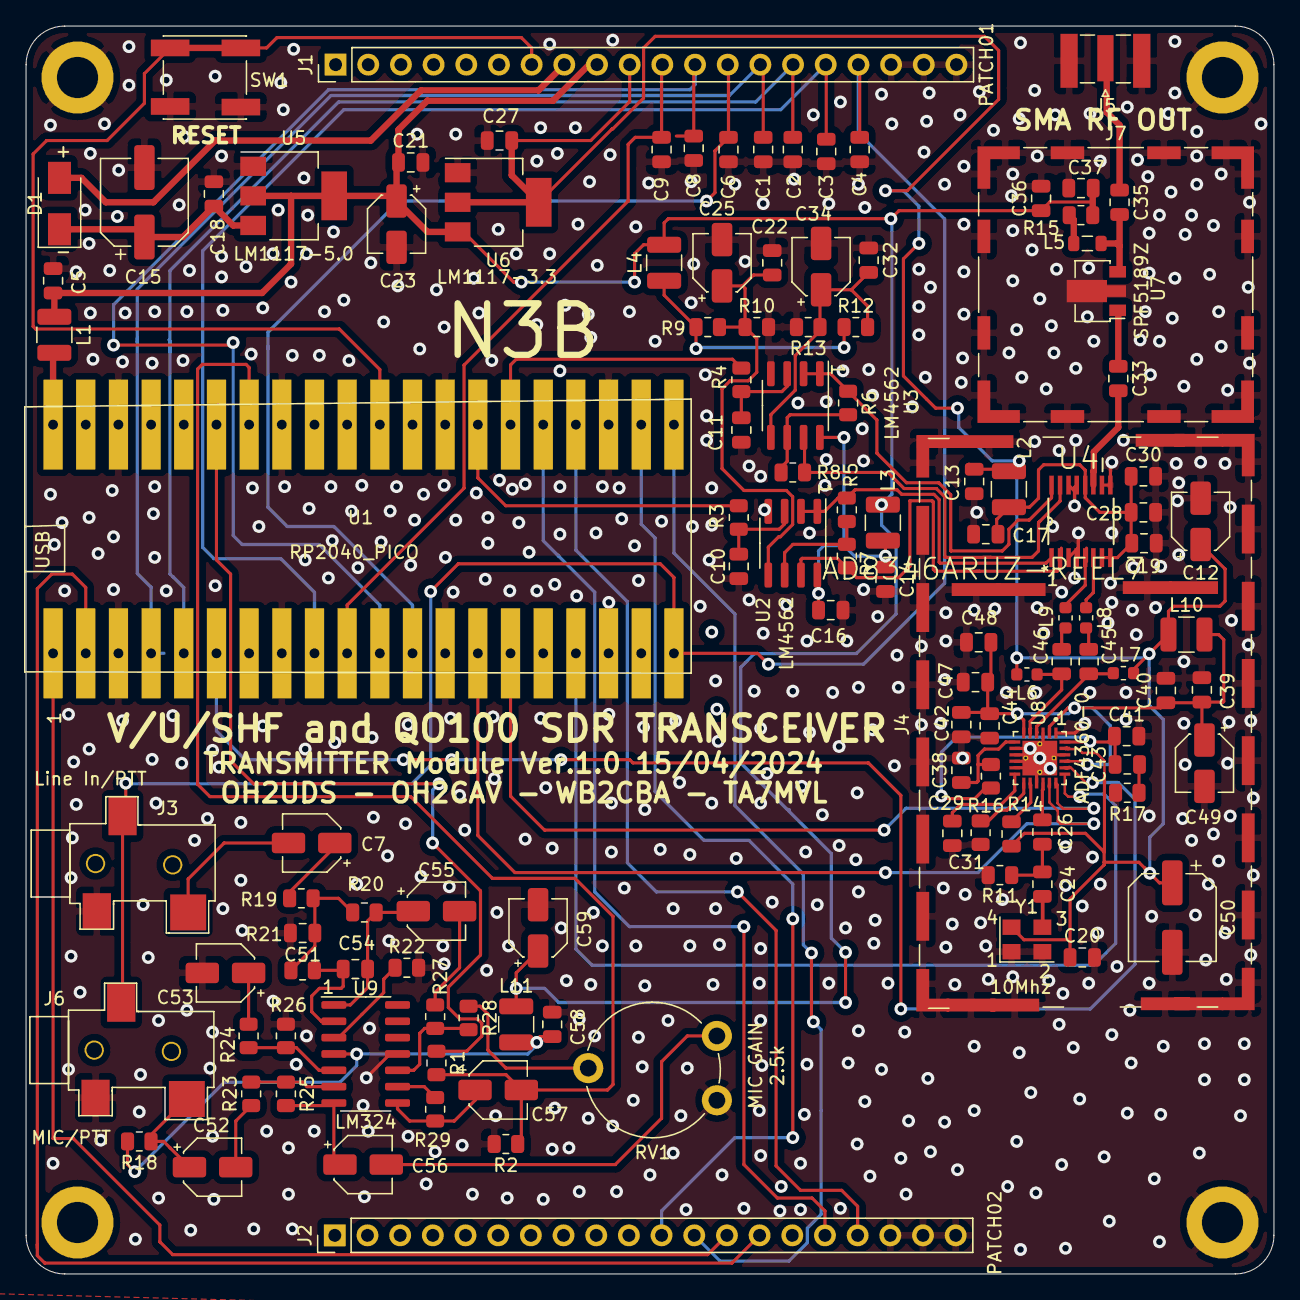
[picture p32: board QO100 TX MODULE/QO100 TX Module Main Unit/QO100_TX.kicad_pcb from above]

Board: 2 copper layers, 97.0 x 97.0 mm, 123 parts (0 on the bottom side), 81 nets.

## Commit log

2024-04-16 initial transmitter commits from barb
    [QO100_TX-B_Cu.gbr, QO100_TX-B_Mask.gbr, QO100_TX-B_Paste.gbr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]
2024-05-17 folder re-organisations
    [QO100_RX.kicad_pcb, QO100_RX.sch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]
2024-06-15 pictures added
    [QO100_RX.kicad_sch]

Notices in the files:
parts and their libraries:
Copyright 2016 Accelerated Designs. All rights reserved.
